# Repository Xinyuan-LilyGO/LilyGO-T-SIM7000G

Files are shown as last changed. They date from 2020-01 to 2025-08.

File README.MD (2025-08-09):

<h1 align = "center">LilyGo SIM7000G</h1>

## **This repository has been moved to [LilyGo-Modem-Series](https://github.com/Xinyuan-LilyGO/LilyGo-Modem-Series/) Please visit the latest repository to see how to get started**
<!-- 

# News

* **For more complete and rich examples, please visit the new repository [LilyGO-T-A76XX](https://github.com/Xinyuan-LilyGO/LilyGO-T-A76XX)**
* It is known that the firmware version 1529B08SIM7000G V01 has problems connecting to the MQTTS 8883 port. Please update the firmware version 1529B10SIM7000G
* Please see the [upgrade guide](./docs/How%20to%20update%20firmware.md)

```bash
-> AT+SIMCOMATI
<-  Revision:1529B08SIM7000G
    CSUB:V01
    APRev:1529B08SIM7000,V01
    QCN:MDM9206_TX3.0.SIM7000G_P1.03_20220415
    IMEI:xxxxxxxxxxxxx
```

### Version 20200415

   This board is an improvement of the original with fixes added that where recommended from feedback.
1. Added active GPS antenna power control, when the module GPIO4 is not turned on the antenna consumes only the static current of the LDO.
2. Replaced TP4056 with CN3065 for solar charge input management.
3. Added reverse battery protection
4. Added battery overcharge protection
5. Added battery over-discharge protection

 ### Version 20191227

   First board release,Sales have been stopped.

<h2 align = "left">Product 📷:</h2>

| Examples | Product  Link | Schematic | Status |
| :---: | :---: | :---: | :----: |
| [Version 20200415 (点击查看)](./Historical/SIM7000G_20200415/README.MD) | [Aliexpress](https://www.aliexpress.com/item/4000542688096.html)/[Amazon USA](https://www.amazon.com/dp/B099RQ7BSR?ref=myi_title_dp)/[FR](https://www.amazon.fr/dp/B099RQ7BSR?ref=myi_title_dp)/[DE](https://www.amazon.de/dp/B099RQ7BSR?ref=myi_title_dp) | [New Version](./schematic/SIM7000G_20200415.pdf) | ✅ |
| [Version 20191227 (点击查看)](./Historical/SIM7000G_20191227/README.MD) | Obsolete | [Old Version](./schematic/SIM7000G_20191227.pdf) | ❌ |

## Use reference

| Product | Youtube  link | explanation | Status | 
| :---: | :---: |:---:| :----: |
| T -SIM7000G | [Youtube link](https://www.youtube.com/watch?v=XlEUWIxdaNU) | How to test whether LILYGO T-SIM7000G can register with the network | ✅ |
| LilyGo device | [Youtube link](https://www.youtube.com/watch?v=f3BybP3L7ls) | How to enter boot mode to download the firmware | ✅ |

## Notes for new Users

0. SIM7000/SIM707G does not support 4G network. Please ensure that the USIM card you use supports 2G(GSM)/NB-IOT access,SIM7070 positioning and cellular cannot be used simultaneously. Please disconnect the network when positioning, and turn off GPS when connecting to the network

1. pin VIN is a USB input, if a battery is being used to power the device there will be no voltage output from VIN meaning 3.3v is the only power output.

2. When using the built-in battery pack the on/off switch will function as normal, supplying/cutting off power to the board, However, if an external battery pack is used and attached to the VBAT pin the on/off switch will be bypassed meaning the only way to shut off will be to disconnect the batteries.

3. On/off switch is for battery use only, it will not function when plugged into USB.

4. Battery voltage can not be read when plugged into USB using the onboard BAT ADC(35)

5. Recommended solar panels are 4.4v to 6v **DO NOT EXCEED OR BOARD MAY BE DAMAGED**

6. When an SD card in you can not upload software in Arduino IDE since the SD card uses IO2 as CS, the SD card must be removed when uploading a new sketch.

7. On Version 20200415, When using GPS the SIM7000G(GPIO4)/SIM7070G(GPIO5)(Physical pin number 48) needs to be set to HIGH to enable the antenna `modem.sendAT("+CGPIO=0,48,1,1");` once finished the pin can be set LOW `modem.sendAT("+CGPIO=0,48,1,0");` to prevent power leaking to the GPS antenna, This will make help battery life. If using USB or battery life is not a concern, it can be left HIGH.

8. If you are unable to access the network, please try <examples/Arduino_NetworkTest>, which will test the network connection. There are also binary files in the firmware directory, you can use the [Flash Download Tools](https://www.espressif.com/sites/default/files/tools/flash_download_tool_v3.8.5.zip) to download.

9.  How to change the connection method?
   - For example, the `Arduino_TinyGSM/AllFunctions.ino`  , you only need to change `modem.setNetworkMode(38);` to the corresponding number, and your network access speed depends on the carrier of the SIM card you use. Before using it, you can communicate with the operator of your SIM card.
   - The effect is as follows:
   ![](image/LTE.png)

10. The initial network registration may be slow. Please be patient. You can configure the locked band as shown in the following figure.
   ![CBANDCFG](image/CBANDCFG.png)

11. How to update firmware?
   - [Upgrade guidelines ](docs/How%20to%20update%20firmware.md)

12. When the onboard USB bridge cannot be downloaded, you can use the external USB bridge to upload the sketch
   ![](./Historical/Image/externalDownloader.jpg)

13. Voltage range

| Battery Voltage requirements | Minimum | Maximum | Charging Current |
| --- | --- | --- | --- |
| SIM7000G | 3.5V | 4.2V | 500mA |
| SIM7070G | 3.5V | 4.2V | 500mA |

* It is recommended to use 18650 batteries with a capacity of more than 2500mA

| Solar Voltage requirements | Minimum | Maximum | Charging Current |
| --- | --- | --- | --- |
| SIM7000G | 4.4V | 6V | 500mA |
| SIM7070G | 4.4V | 6V | 500mA |

> \[!TIP]
>
> It is recommended to use a solar panel with an output voltage of 6V or 5V and a power of about 5-10W. Solar energy can only charge the battery. Without the battery, the panel cannot supply power.
> Please note that this is only a suggestion. It is not necessary to use a 5-10W solar panel. 1W is also acceptable.
> The size of the solar panel determines the current and speed of solar charging. Please note that depending on the environment,
> the sunshine time may not exceed one hour per day. At this time, if the solar panel is too small and the light is not sufficient, it cannot be charged.

## GPIO MAP

| FUNCTION | GPIO NUM |
| --- | --- |
| RX | 26 |
| TX | 27 |
| PWR | 4 |
| DTR | 25 |
| RING | NC |
| RESET | NC |
| ON BOARD LED(BLUE)  | 12 |
| SD SOCKET MISO | 2 |
| SD SOCKET MOSI | 15 |
| SD SOCKET SCK | 14 |
| SD SOCKET CS | 13 |
| BATTERY ADC CONNECT | 35 |
| SOLAR ADC CONNECT | 36 |

## ON-BOARD LED

| FUNCTION | COLOR |
| --- | --- |
| MODEM STATUS | RED (Near the modem) |
| MODEM NETWORK STATE | RED (Near the modem) |
| CHARGE FULL | GREEN (Near the USB port) |
| CHARGING | RED (Near the USB port) |
| GPIO CONTROL | BLUE |

### **MODEM STATUS**

- As long as the modem is turned on, the STATUS light will remain on and will go out when it is turned off.

### **MODEM NETWORK STATE**

| Network light status | Module working status |
| --- | --- |
| 64ms on/ 800ms off | When not registered on the network |
| 64ms on/ 3000ms off  | Already registered on the network (PS domain registration successful) |
| 64ms on/ 300ms off | During data transmission (PPP dial-up state and when using internal TCP/FTP/HTTP and other data services) |
| Off | Power off or PSM sleep mode | -->

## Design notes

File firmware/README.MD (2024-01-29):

# Write to new users

- This page provides a quick diagnosis of whether the hardware is normal. The firmware in the example table below can provide a quick test of the hardware. Follow the writing method below.
- When using GPS positioning test, please do it outdoors or by extending the active GPS antenna. The geographical location cannot be obtained indoors.
- For network testing, please connect the LTE antenna to the board's silk screen MAIN or SIM IPEX antenna base.
- Please do not use a SIM card with a locked PIN code. Please delete the PIN code before use.

# 1️⃣ Quickly diagnose hardware

| GPS Test describe | GPS Test Firmware | Network Test Firmware |
| --- | --- | --- |
| Firmware decoded NMEA data | [GPS_Decoder.bin](./GPS_Decoder.bin) | [firmware](./Arduino_NetworkTest_Frimware.bin) |
| Firmware for raw NMEA data | [GPS_RAW_DATA.bin](./GPS_RAW_DATA.bin) | [firmware](./Arduino_NetworkTest_Frimware.bin) |

* [Firmware for raw NMEA data video](https://youtu.be/eVJ8NNOeWnY)

| Network Test describe | Network Test Firmware |
| --- | --- |
| Firmware automatically searches for networks | [firmware](./Arduino_NetworkTest_Frimware.bin) |

[1]: https://www.lilygo.cc/products/t-sim7000g

## Use ESP Download Tool

| Steps  | [T-SIM70XX][1] |
| --- | --- |
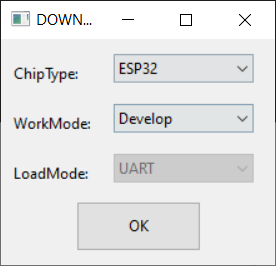
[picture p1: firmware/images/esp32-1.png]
| Step 1 |  |
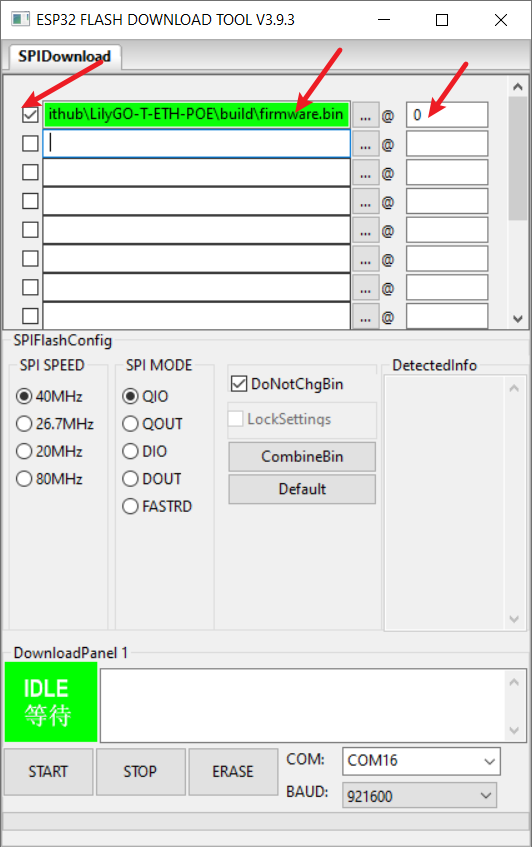
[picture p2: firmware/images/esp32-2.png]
| Step 2 |  |

## Use Web Flasher

[esp.huhn.me](https://esp.huhn.me/)

web_flasher

# 2️⃣FAQ

- Can't upload any sketch，Please enter the upload mode manually.
   1. Connect the board via the USB cable
   2. Press and hold the BOOT button , While still pressing the BOOT button (If there is no BOOT button, you need to use wires to connect GND and IO0 together.)
   3. Press RST button
   4. Release the RST button
   5. Release the BOOT button (If there is no BOOT button, disconnect IO0 from GND.)
   6. Upload sketch

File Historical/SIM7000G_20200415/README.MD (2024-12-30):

<h1 align = "center">LilyGO T-SIM7000G 20200415</h1>

### PinOut

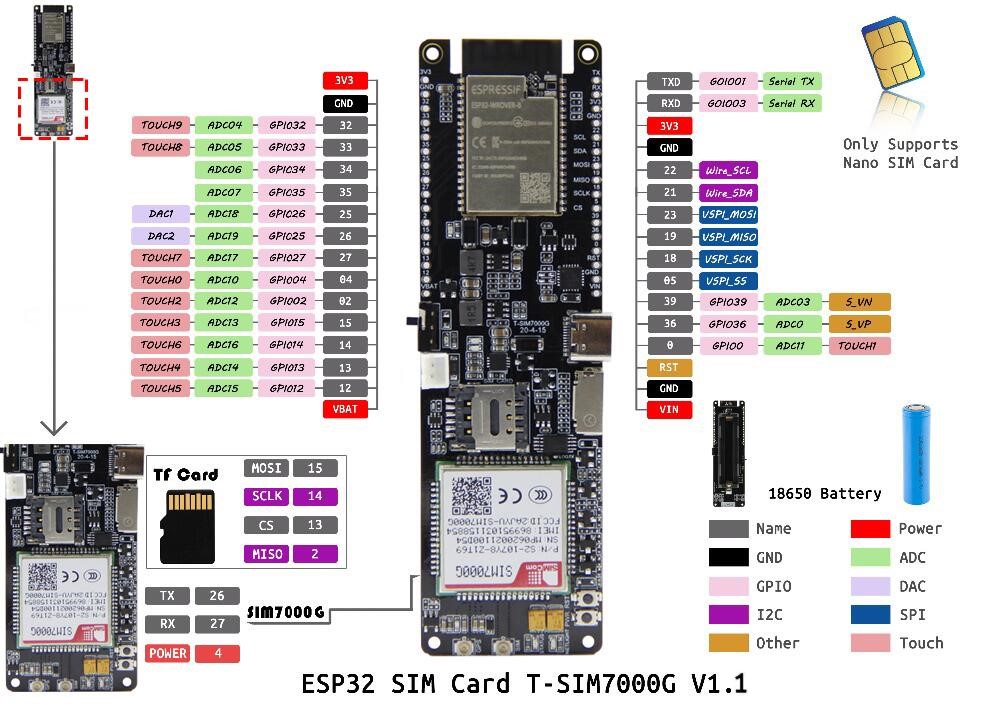
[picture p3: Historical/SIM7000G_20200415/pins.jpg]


### Dimensions
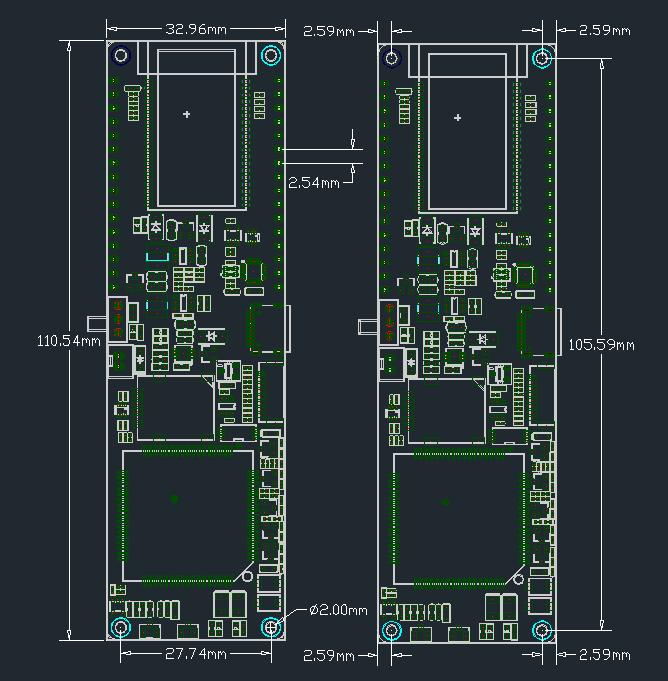
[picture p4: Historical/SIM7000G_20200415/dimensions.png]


## Examples
- Arduino + TinyGSM library: [examples/Arduino_TinyGSM](../../examples/Arduino_TinyGSM/)
- Platformio_Arduino_Thingsboard :[/exaples/Platformio_Arduino_Thingsboard](../../examples/Platformio_Arduino_Thingsboard)
- Loboris Micropython: [/examples/MicroPython_LoBo](../../examples/MicroPython_LoBo)
- Arduino Cayenne: [/examples/Arduino_Cayenne](../../examples/Arduino_Cayenne)

## SIM7000G connection
| Name | Pins |
| --- | --- |
| Modem DTR | 25 |
| Modem Rx | 26 |
| Modem Tx | 27 |
| Modem PowerKey | 4 |
| Modem Reset | 5 |
| Modem GPS | SIM7000G(GPIO4)/SIM7070G(GPIO5)(Physical pin number 48) |
| BAT ADC | 35 |
| SOLAR ADC | 36 |
| SD MISO | 2 |
| SD MOSI | 15 |
| SD CLK | 14 |
| SD CS | 13 |
| LED | 12 |

**Modem GPS** is the internal GPIO of the SIM7000G module. When using GPS, GPIO4 needs to be set to high level, as shown below:

```
// Set SIM7000G(GPIO4)/SIM7070G(GPIO5) to HIGH ,Open GPS power
modem.sendAT("+CGPIO=0,48,1,1");

// Set SIM7000G(GPIO4)/SIM7070G(GPIO5) to LOW ,Close GPS power
modem.sendAT("+CGPIO=0,48,1,0");
```

- About the onboard indicator light description:
1. In the pin diagram, the red indicator light near the upper right of the switch is only on when the battery is connected, and it is always on when the USB is connected. It indicates that the battery is charging. If the battery is not connected, it may be Flashing
2. Below the red light is the green indicator light, which lights up only when the battery is fully charged, and it is always on when the battery is connected

3. Close to the side of the SIM7000G antenna is the status indicator. If the SIM7000G starts normally, it will always be on. If it does not start normally, it will not be on. It cannot be turned off by software.
4. Close to the status indicator is the network indicator, it indicates the network status, it can be closed by software

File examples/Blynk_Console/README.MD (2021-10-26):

<h1 align = "center">T-PCIE-SIM7000 Blynk_Console</h1>

## **[English](./README.MD) | [中文](./README_CN.MD)**

# Steps:
1. Need to install the following dependencies
     - [Adafruit BMP085 Library](https://github.com/adafruit/Adafruit-BMP085-Library)
     - [blynk-library](https://github.com/blynkkk/blynk-library)
     - [TinyGSM](https://github.com/vshymanskyy/TinyGSM)

2. Register and login[blynk.cloud](https://blynk.cloud/dashboard/login) 

3. Create a new template or use an existing template (The name can be customized)

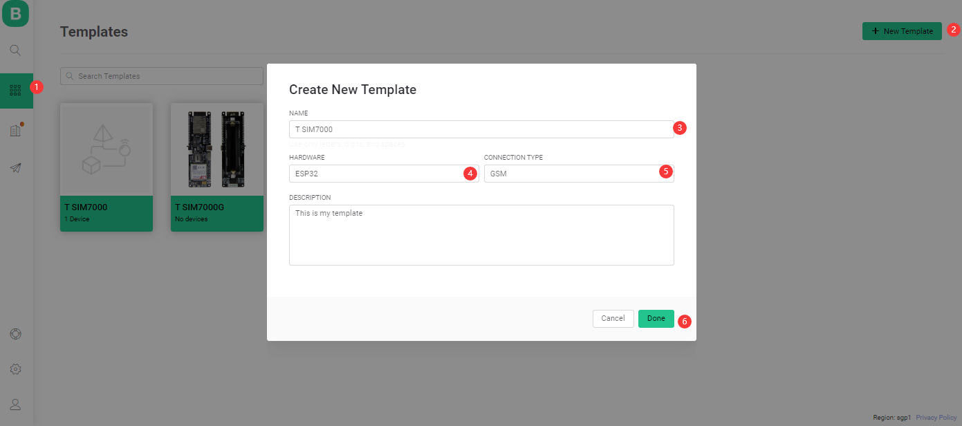
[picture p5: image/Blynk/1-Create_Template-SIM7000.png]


4.   When the Template is ready, go to Search -> Devices - Create New Device

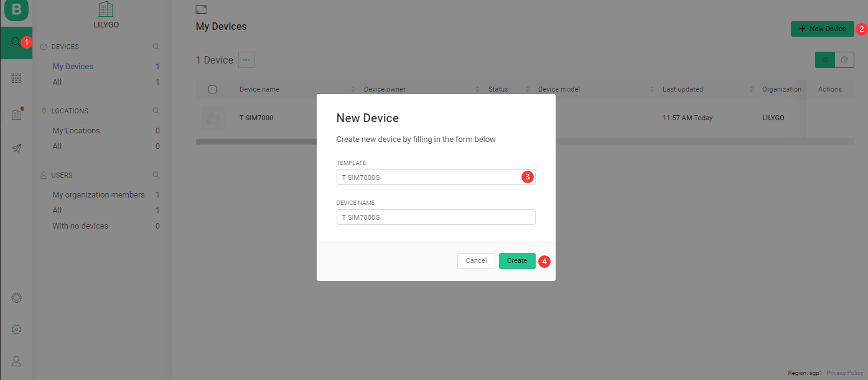
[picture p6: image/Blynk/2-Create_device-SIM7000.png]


5. Configuration module

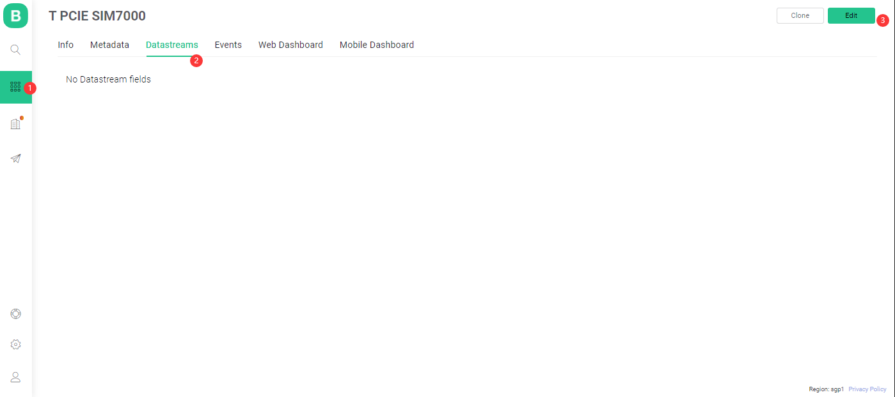
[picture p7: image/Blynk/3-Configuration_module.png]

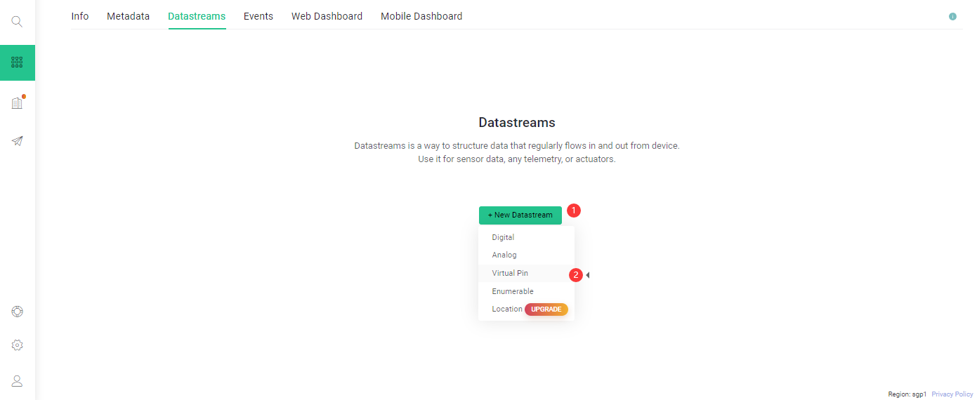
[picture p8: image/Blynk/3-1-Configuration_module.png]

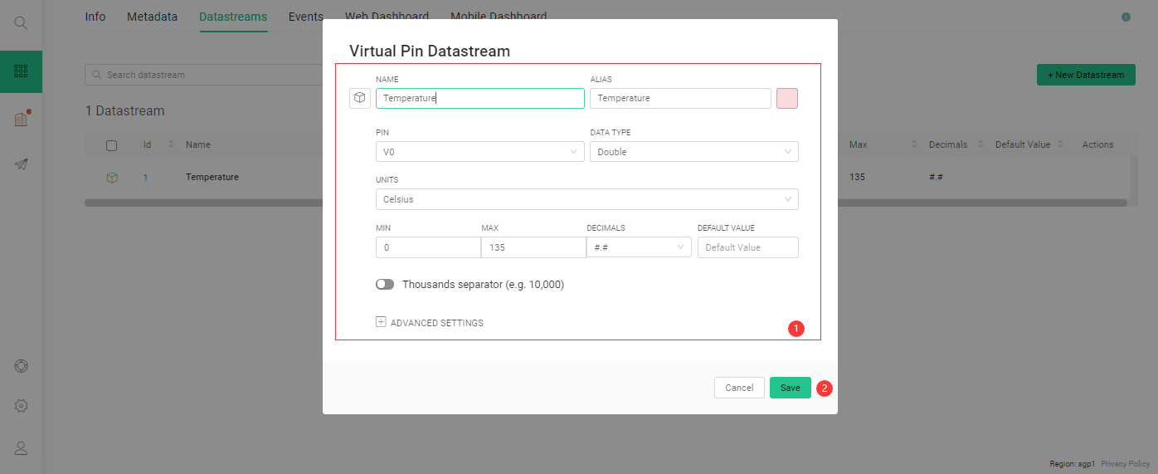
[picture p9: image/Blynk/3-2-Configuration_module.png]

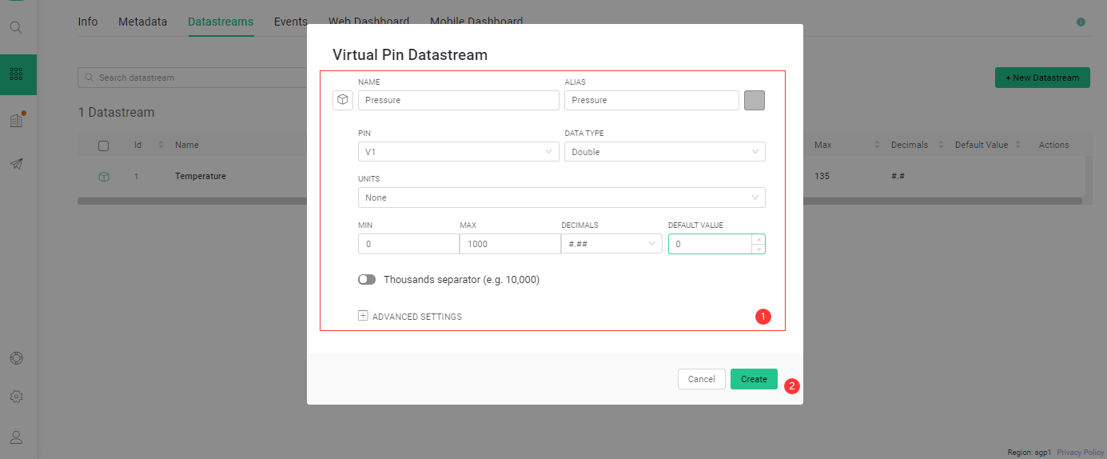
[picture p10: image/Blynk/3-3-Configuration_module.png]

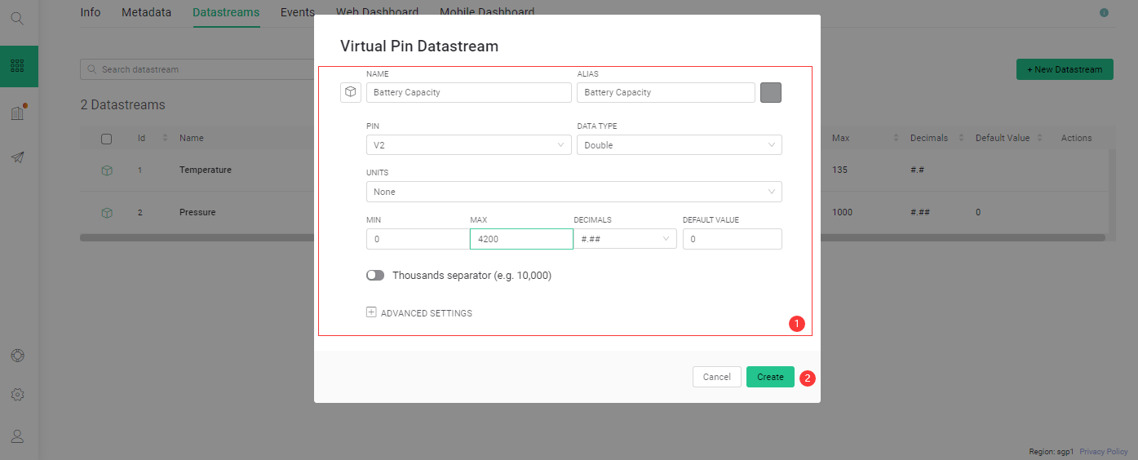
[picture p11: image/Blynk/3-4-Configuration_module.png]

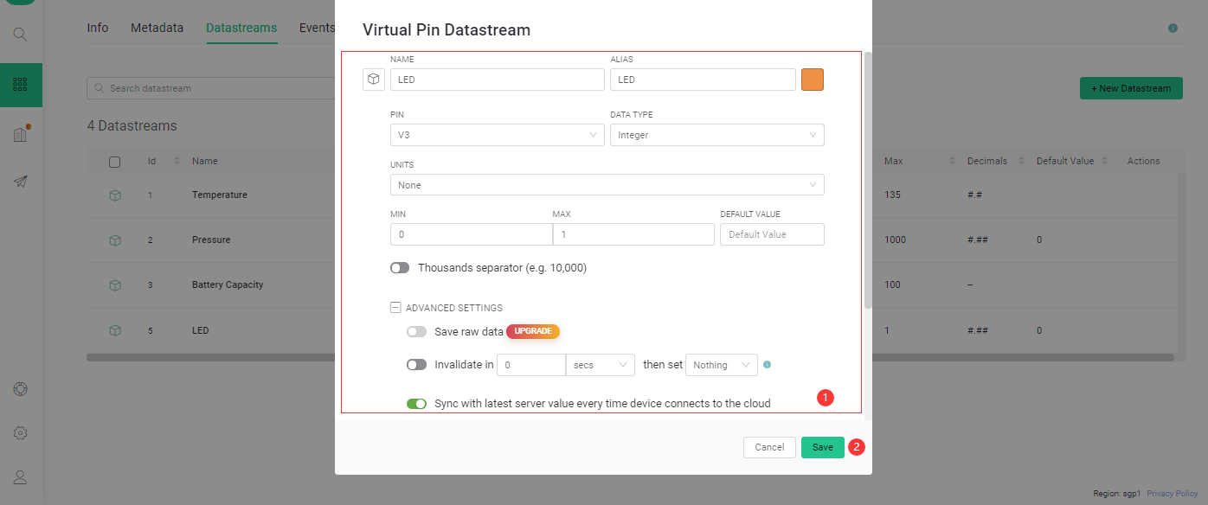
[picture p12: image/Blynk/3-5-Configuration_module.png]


6. Set up the Web dashboard

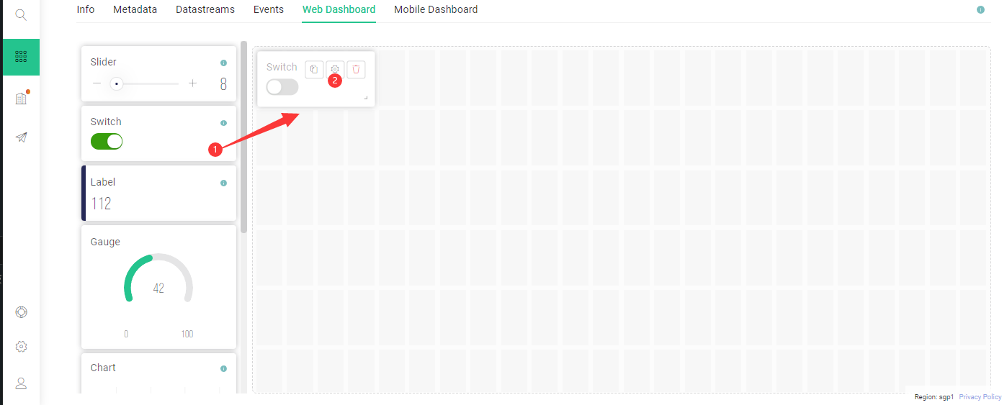
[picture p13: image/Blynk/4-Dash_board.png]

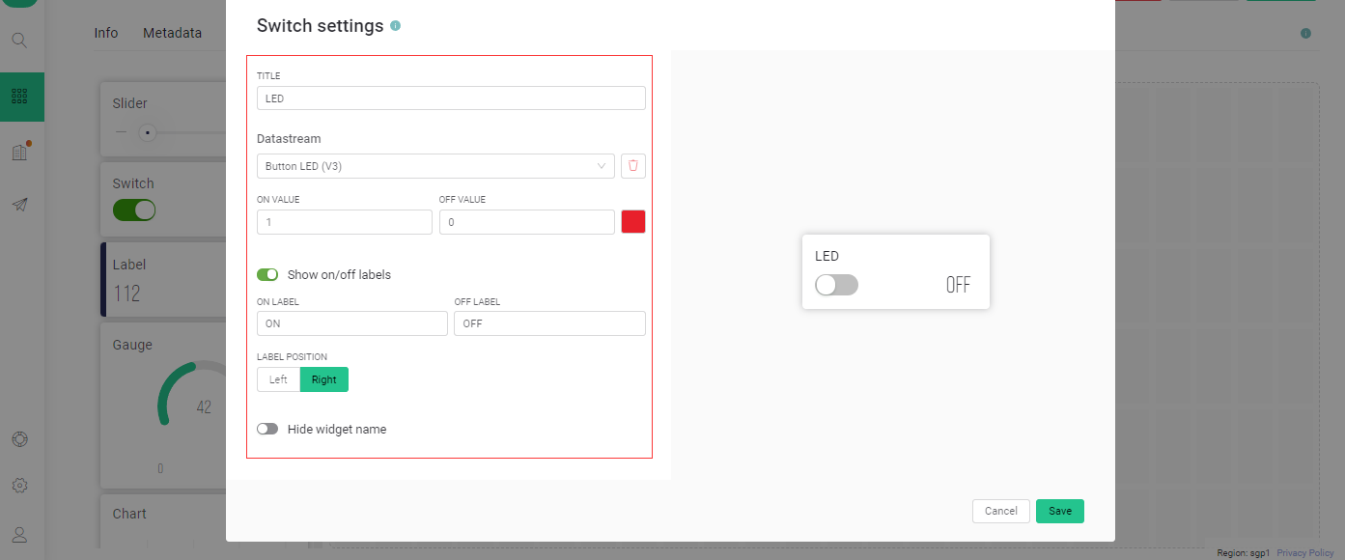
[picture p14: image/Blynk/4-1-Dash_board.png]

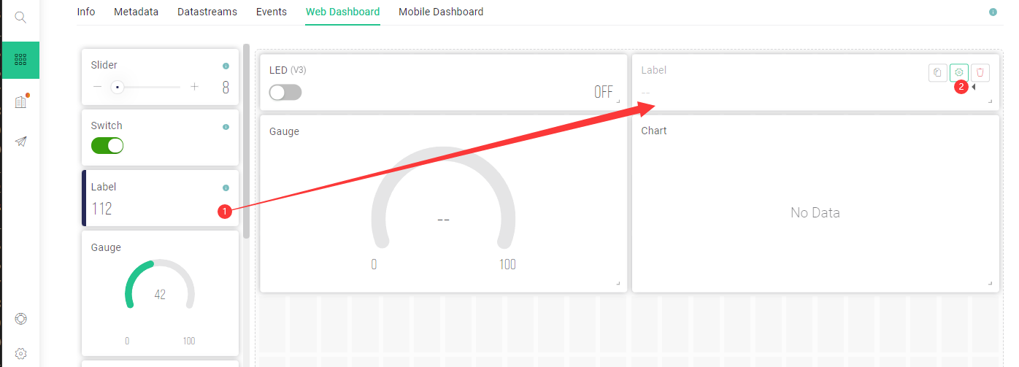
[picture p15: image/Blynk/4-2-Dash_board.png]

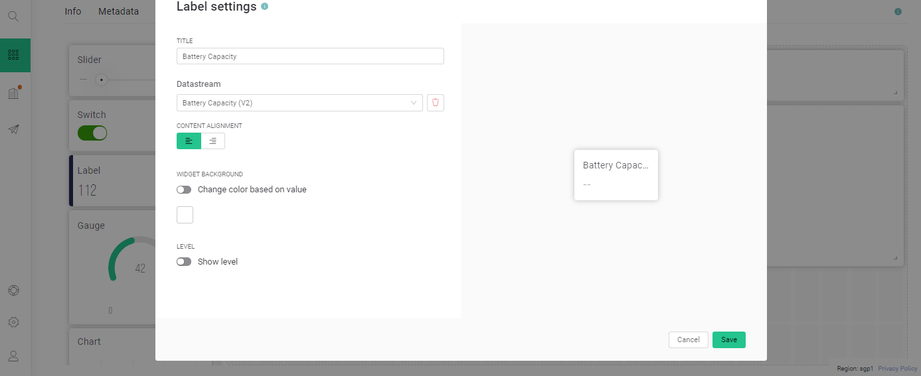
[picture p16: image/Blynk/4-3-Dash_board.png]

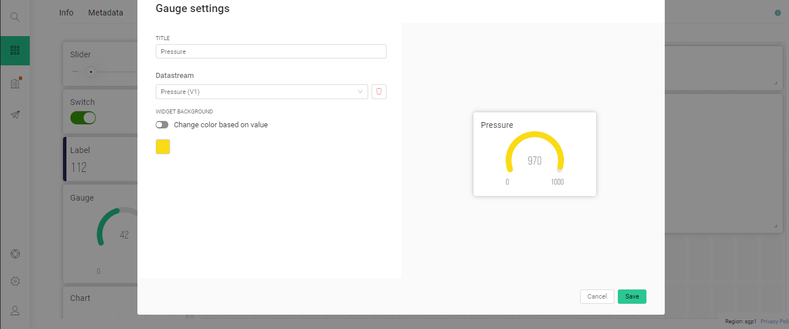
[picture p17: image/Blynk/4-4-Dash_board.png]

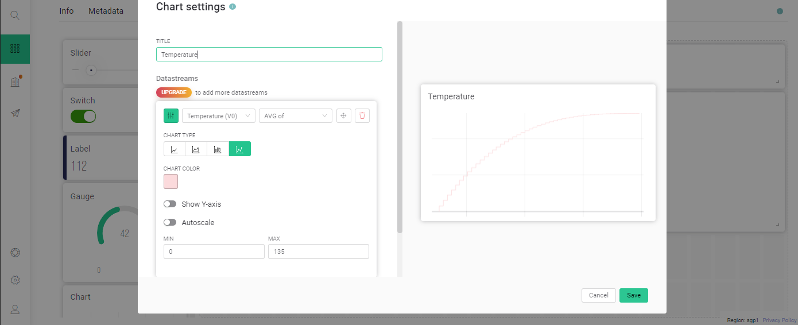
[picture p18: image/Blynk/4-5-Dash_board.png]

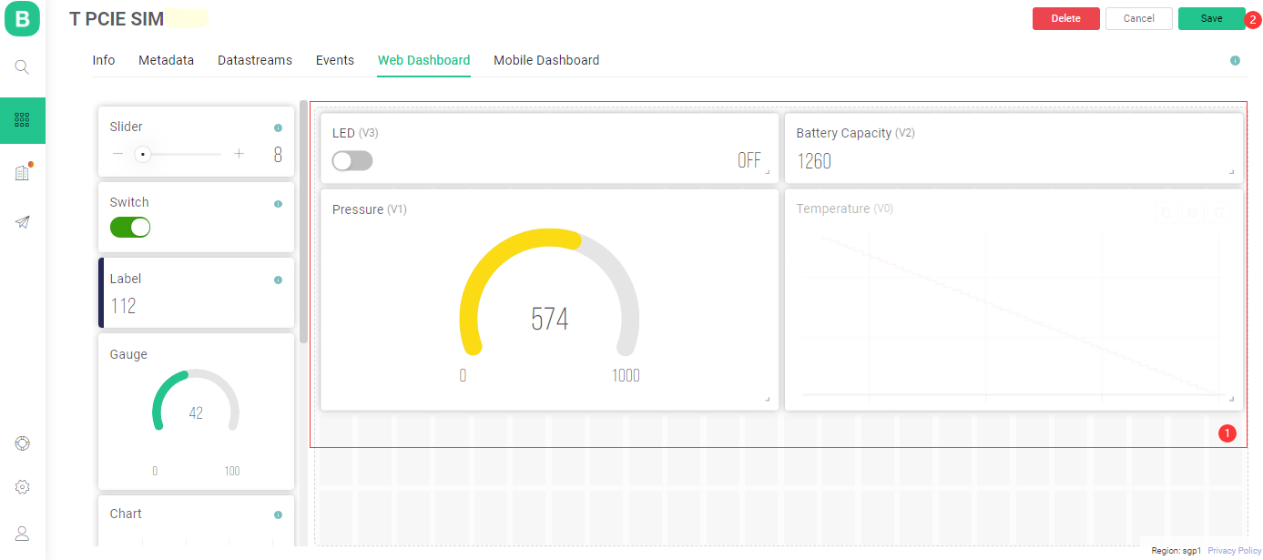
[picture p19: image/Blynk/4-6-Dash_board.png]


7. Replace the macro definition in the code

    #define BLYNK_TEMPLATE_ID ""
    #define BLYNK_DEVICE_NAME ""
    #define BLYNK_AUTH_TOKEN "";

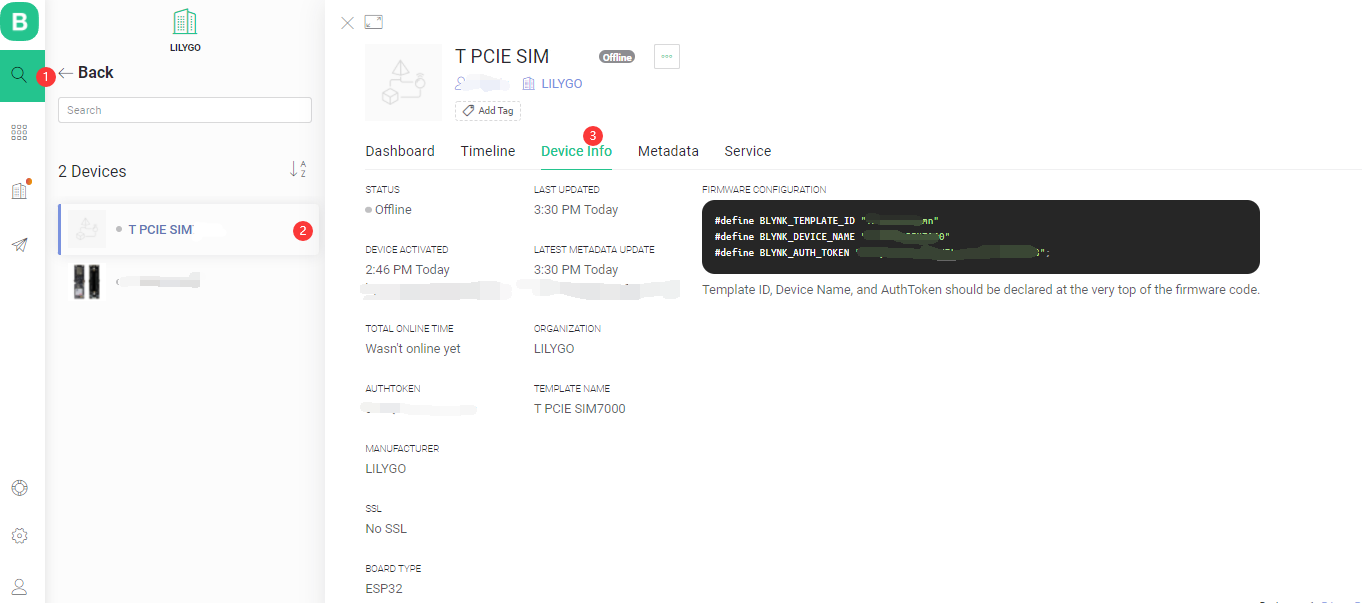
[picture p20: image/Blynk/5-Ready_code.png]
 

8. Upload the code and now you control the LDE and get the data in the cloud
   
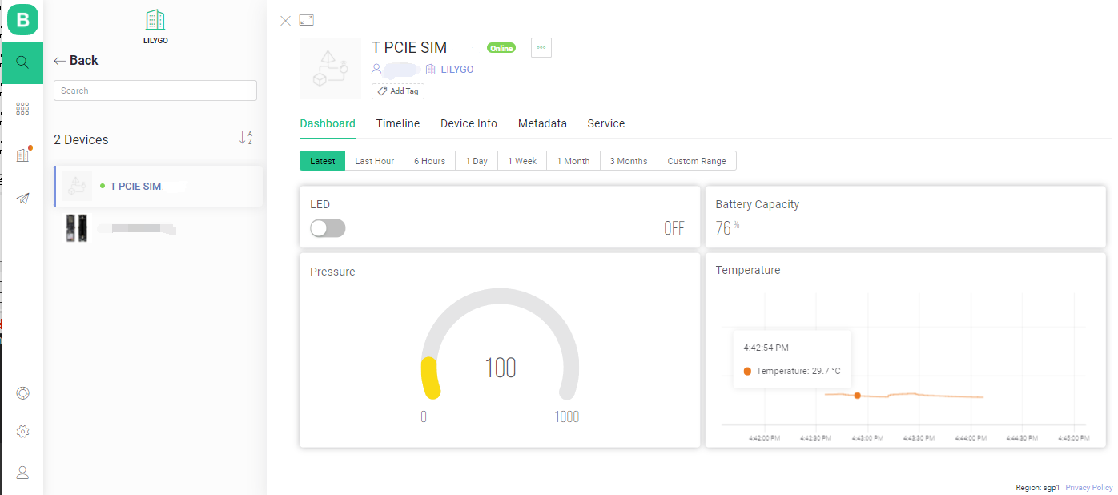
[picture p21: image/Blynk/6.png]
   

9. Reference[Documentation](https://docs.blynk.io/en/)

# Hardware
Connections for T-SIM7000 and BMP180
| T-PCIE pin  | BMP180 pin |
| --- | --- |
| 3.3 | VIN |
| GND | GND |
| GPIO21(SDA) | SDA |
| GPIO22(SCL) | SCL |

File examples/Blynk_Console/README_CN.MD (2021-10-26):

<h1 align = "center">T-PCIE-SIM7000 Blynk_Console</h1>

## **[English](./README.MD) | [中文](./README_CN.MD)**

# 步骤:

1. 需要安装下面的库
     - [Adafruit BMP085 Library](https://github.com/adafruit/Adafruit-BMP085-Library)
     - [blynk-library](https://github.com/blynkkk/blynk-library)
     - [TinyGSM](https://github.com/vshymanskyy/TinyGSM)

2. 注册登录[blynk.cloud](https://blynk.cloud/dashboard/login) 

3. 创建新模板或使用已有模板



4. 当模板准备好，进入搜索->设备-创建新设备  



5. 配置模块








6. 设置 Web 仪表板 









7. 替换代码中的宏

#define BLYNK_TEMPLATE_ID ""
#define BLYNK_DEVICE_NAME ""
#define BLYNK_AUTH_TOKEN "";



8. 上传代码，可以控制LDE和获取数据

 

10. 参考[文档](https://docs.blynk.io/en/)

# 硬件接线
| T-PCIE pin  | BMP180 pin |
| --- | --- |
| 3.3 | VIN |
| GND | GND |
| GPIO21(SDA) | SDA |
| GPIO22(SCL) | SCL |

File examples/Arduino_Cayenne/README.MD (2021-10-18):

<h1 align = "center">LilyGO T-SIM7000 Cayenne</h1>

💦 ☀💨🌹 The sample code is based on the **[LilyGO T-SIM7000](https://www.aliexpress.com/item/4000542688096.html)** board, which takes the data of the external BMP180 sensor and uploads it to **[Cayenne](https://cayenne.mydevices.com/)**.

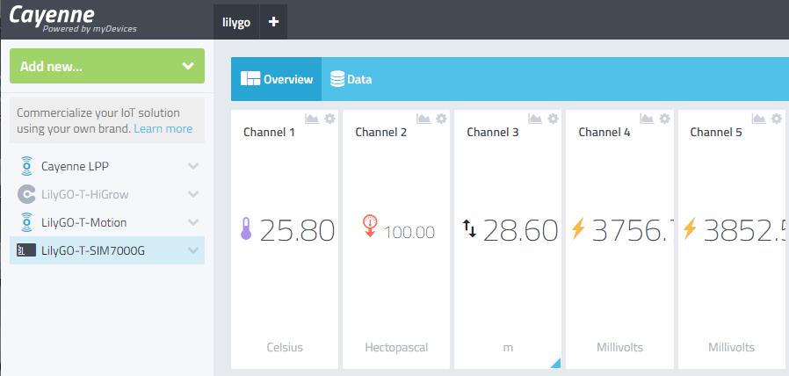
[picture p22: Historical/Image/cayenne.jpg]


# Steps:
1. Need to install the following dependencies
     - [Adafruit BMP085 Library](https://github.com/adafruit/Adafruit-BMP085-Library)
     - [CayenneMQTT](https://github.com/myDevicesIoT/Cayenne-MQTT-Arduino)
     - [ArduinoJson](https://github.com/bblanchon/ArduinoJson) Use version 6.13.0
     - [TinyGSM](https://github.com/vshymanskyy/TinyGSM)
2. Set the Cayenne authentication info to match the authentication info from the Dashboard.If you don't have an account, then [create an account](https://accounts.mydevices.com/auth/realms/cayenne/login-actions/registration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)
3. After logging in, you will see the dashboard, click **Add new** in the upper left,Choose **Generic ESP8266**,Then you can see the MQTT username, password and ID you need to use,Replace it with the definition in `main.cpp`
4. Set the network name and password.
5. Compile and upload the sketch.
6. A temporary widget will be automatically generated in the Cayenne Dashboard. To make the widget permanent click the plus sign on the widget.
7. By default, GSM is used to upload sensor data. You can also change it to ESP32 to upload. You only need to host the **USE_GSM** macro in the sketch.

# Hardware
Connections for T-SIM7000 and BMP180
| T-SIM7000 pin | BMP180 pin |
| --- | --- |
| 3.3 | VIN |
| GND | GND |
| GPIO21(SDA) | SDA |
| GPIO22(SCL) | SCL |

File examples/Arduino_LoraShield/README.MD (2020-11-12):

## Install the following dependency library files:
[arduino-LoRa](https://github.com/sandeepmistry/arduino-LoRa)

- For more examples, please refer to arduino-LoRa/examples

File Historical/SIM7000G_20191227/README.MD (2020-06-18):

<h1 align = "center">LilyGO T-SIM7000G </h1>

### PinOut

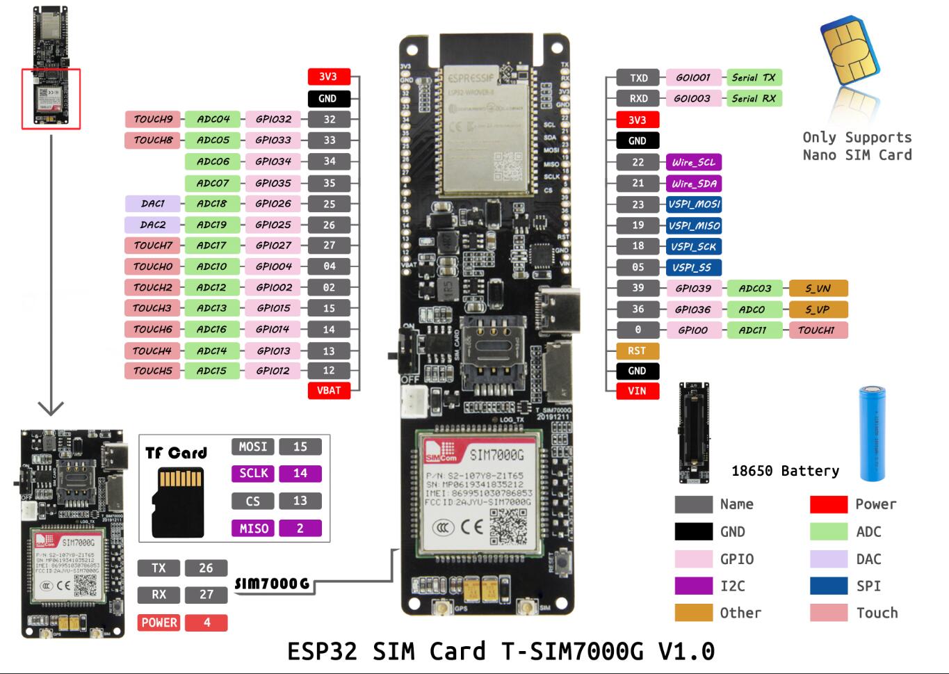
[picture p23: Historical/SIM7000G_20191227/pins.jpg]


### Dimensions
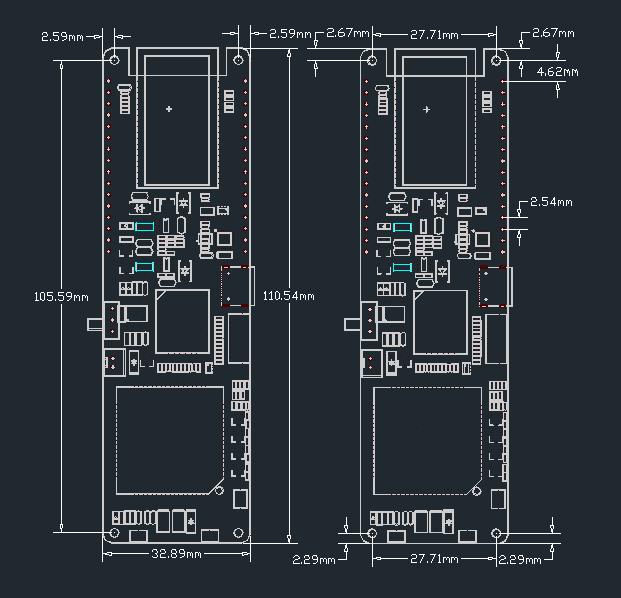
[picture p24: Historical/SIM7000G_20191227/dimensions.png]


## Examples
- Arduino + TinyGSM library: [examples/Arduino_TinyGSM](../../examples/Arduino_TinyGSM/)
- Platformio_Arduino_Thingsboard :[/exaples/Platformio_Arduino_Thingsboard](../../exaples/Platformio_Arduino_Thingsboard)
- Arduino Cayenne: [/examples/Arduino_Cayenne](../../examples/Arduino_Cayenne)

## SIM7000G connection
| Name | Pins |
| --- | ---- |
| PIN_RX | 26 |
| PIN_TX | 27 |
| PWR_PIN | 4 |
| BAT_ADC | 35 |
| SOLAR_ADC | 36 |
| SD MISO | 2 |
| SD MOSI | 15 |
| SD CLK | 14 |
| SD CS | 13 |

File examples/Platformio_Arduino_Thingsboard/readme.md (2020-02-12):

# Example project for Platformio

- T-SIM7000 NBIoT or GSM mode (modified TinyGSM lib)
- Connecting to Thingsboard and sending telemetry battery/rssi/bootcount via MQTT
- Sleeping ESP32 & SIM7000 (~1mA consumption)

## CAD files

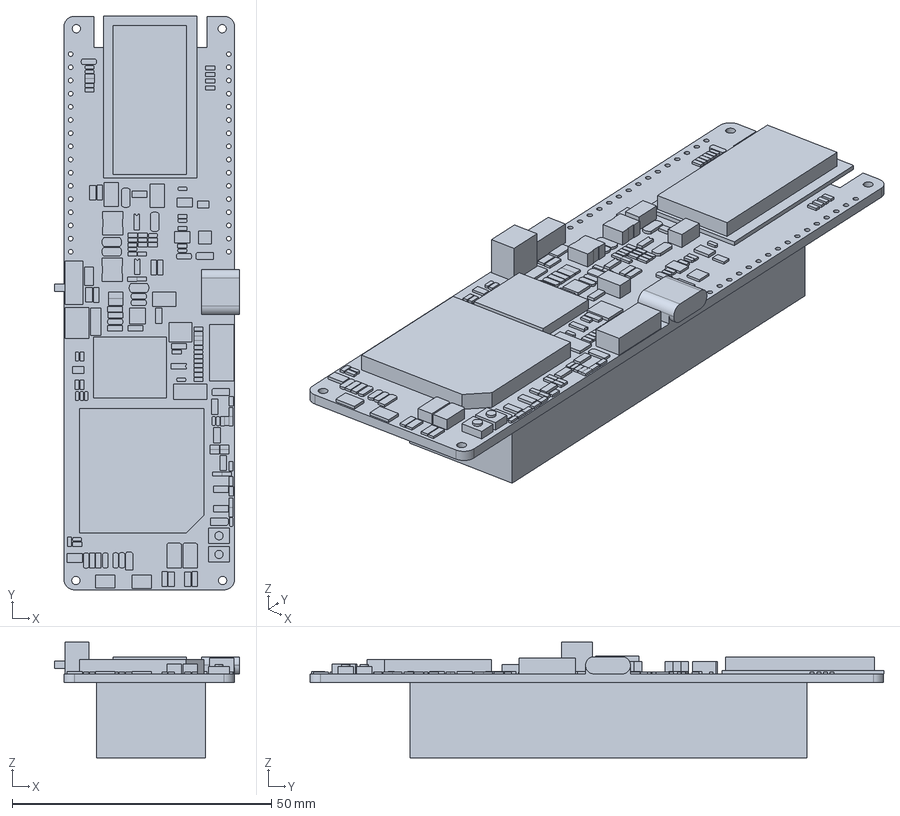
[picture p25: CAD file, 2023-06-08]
3D_file/T-SIM7000G(6.08).stp
35.7 x 110.6 x 22.4 mm

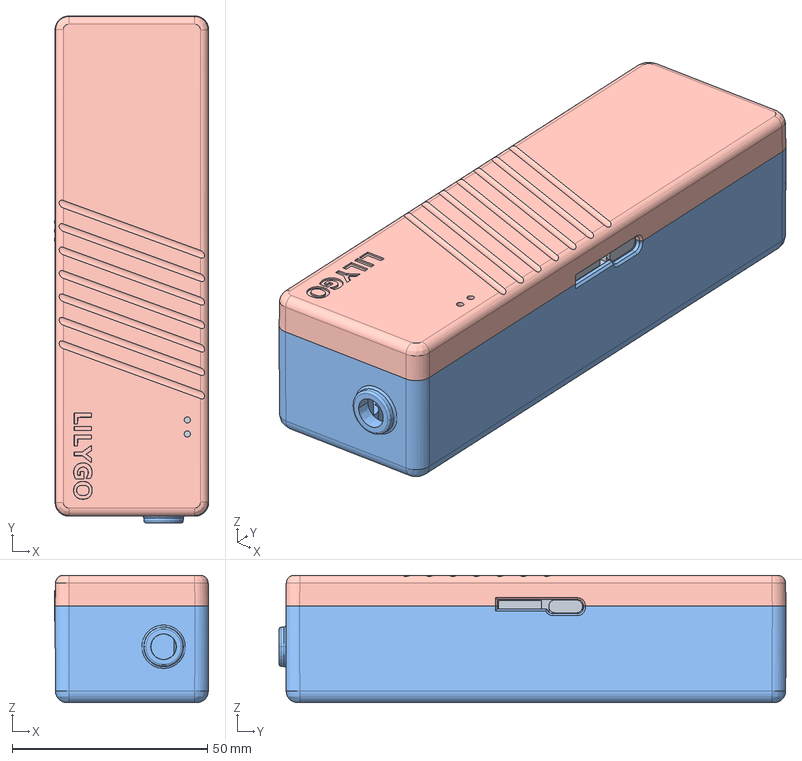
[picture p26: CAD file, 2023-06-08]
3D_file/t-sim7000g-shell.stp
39.5 x 129.8 x 32.6 mm
007_02_T-SIM7000G-B-COVER
006_02_T-SIM7000G-A-COVER
003_01_A7672-C-COVER
T-SIM7000G_6_08_

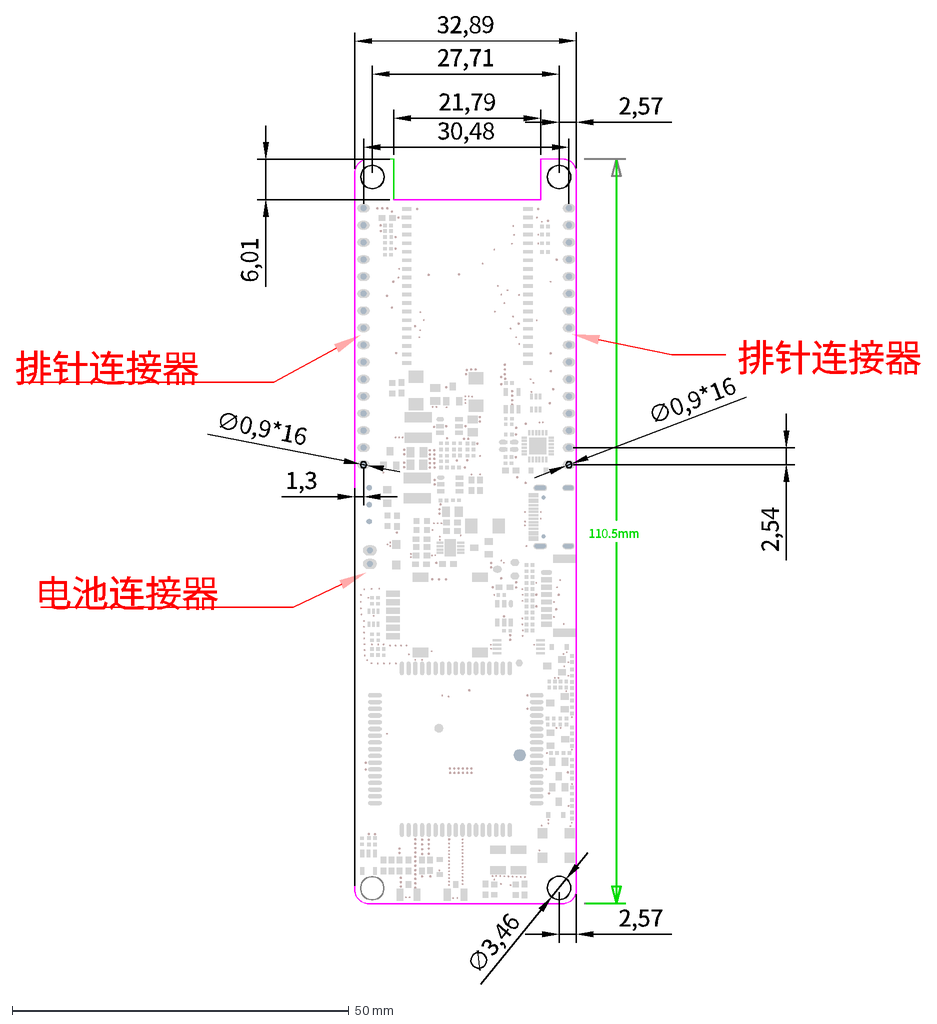
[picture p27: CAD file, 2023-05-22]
3D_file/T-SIM7000G..dxf
110.5mm
32,89
27,71
2,57
∅3,46
21,79
6,01
电池连接器
排针连接器
∅0,9*16
2,54
30,48
1,3

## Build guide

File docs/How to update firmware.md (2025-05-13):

## Quick Step

1. To solder the USB to the upgrade solder joint, you can choose a flying lead or directly solder the USB to the contact.
2. Power on the SIM7000G board, and at the same time connect the USB interface to the computer port (please note that you need to insert the SIM card during the upgrade process)
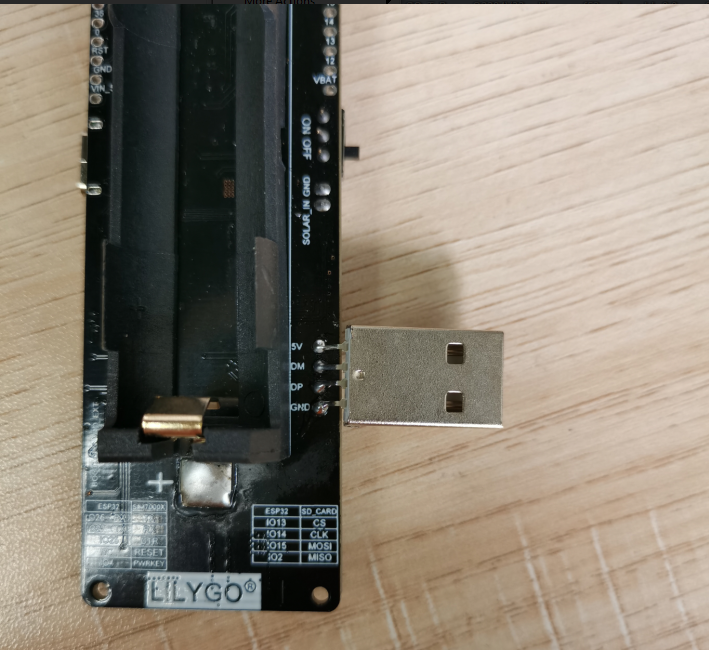
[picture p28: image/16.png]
    
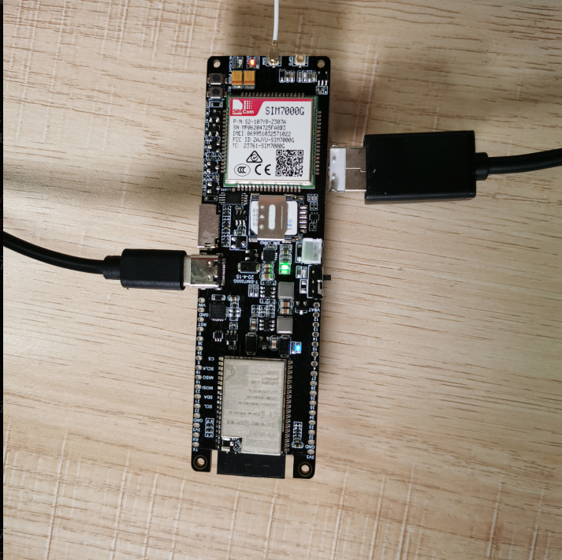
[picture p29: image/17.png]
    
3. Download [SIM7000X Driver](https://1drv.ms/u/s!AmbpOqVezk5drS-ateuVXXDK1ulv?e=yc0kXz), and decompress the corresponding compressed package according to the system you are using.
4. Open the computer device manager and follow the steps below to add the driver.
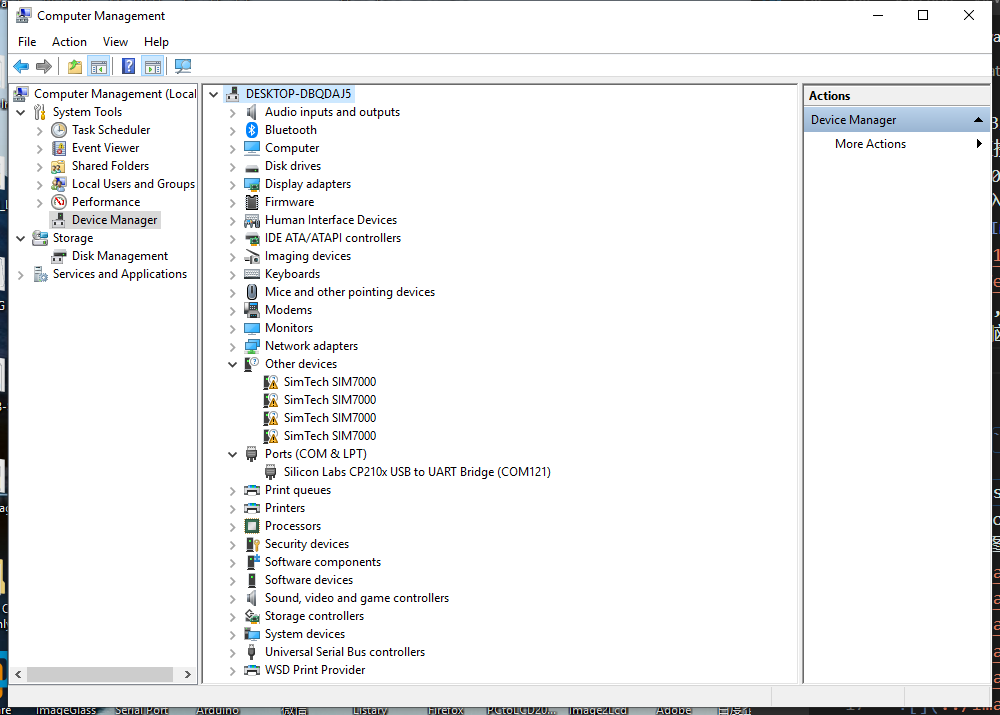
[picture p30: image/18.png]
    
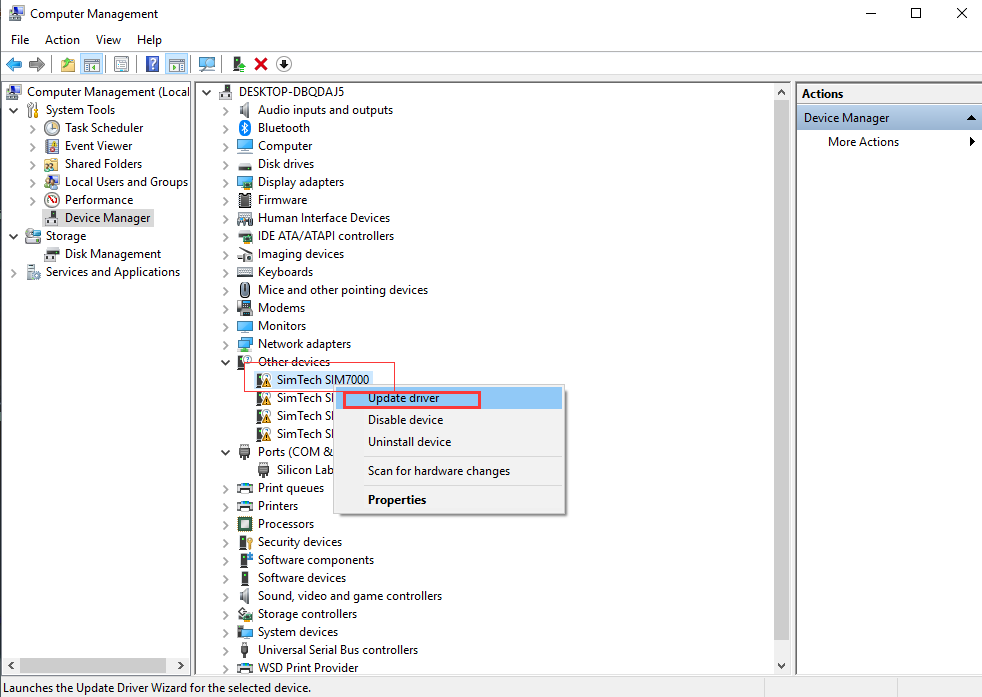
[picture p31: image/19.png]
    
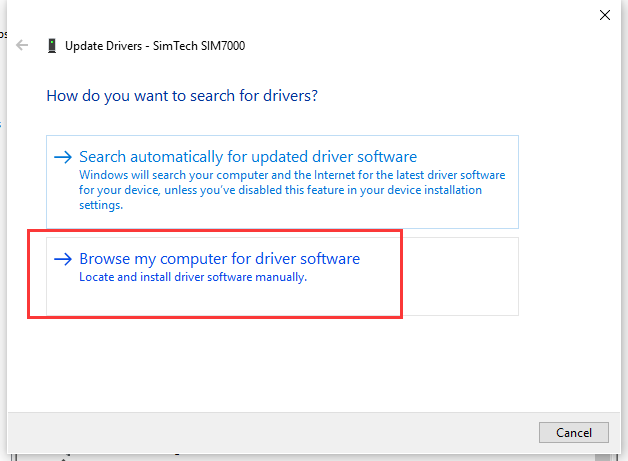
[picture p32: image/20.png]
    
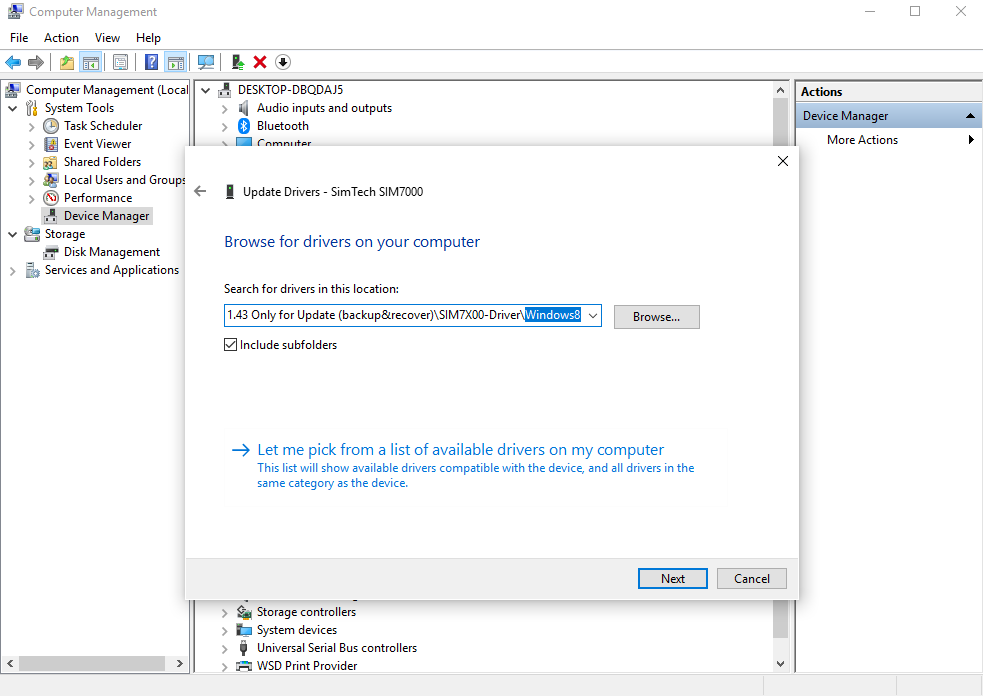
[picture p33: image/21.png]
    
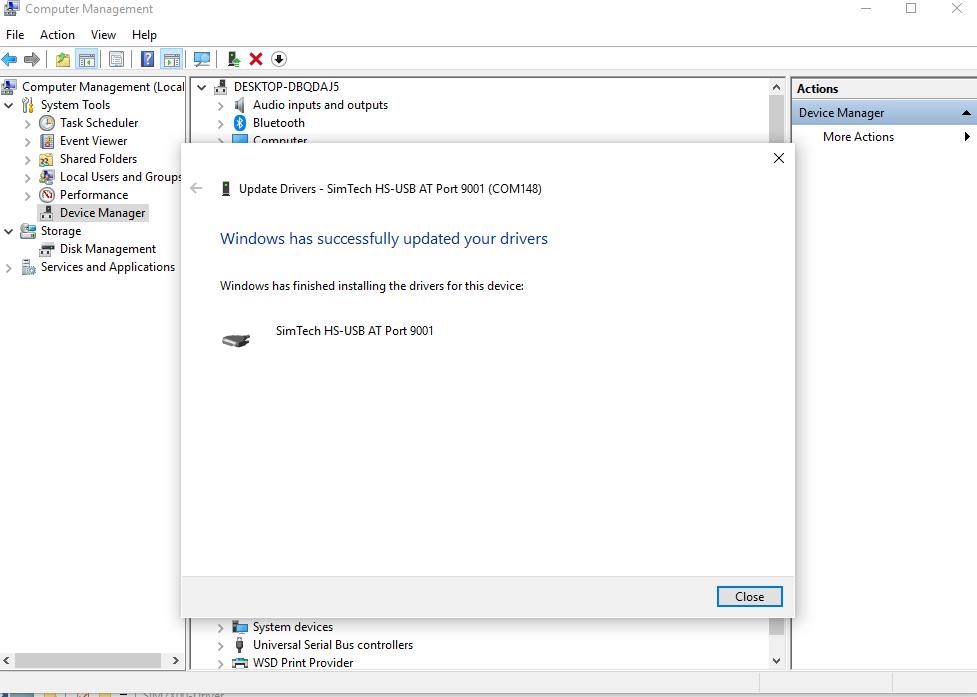
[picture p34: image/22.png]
    
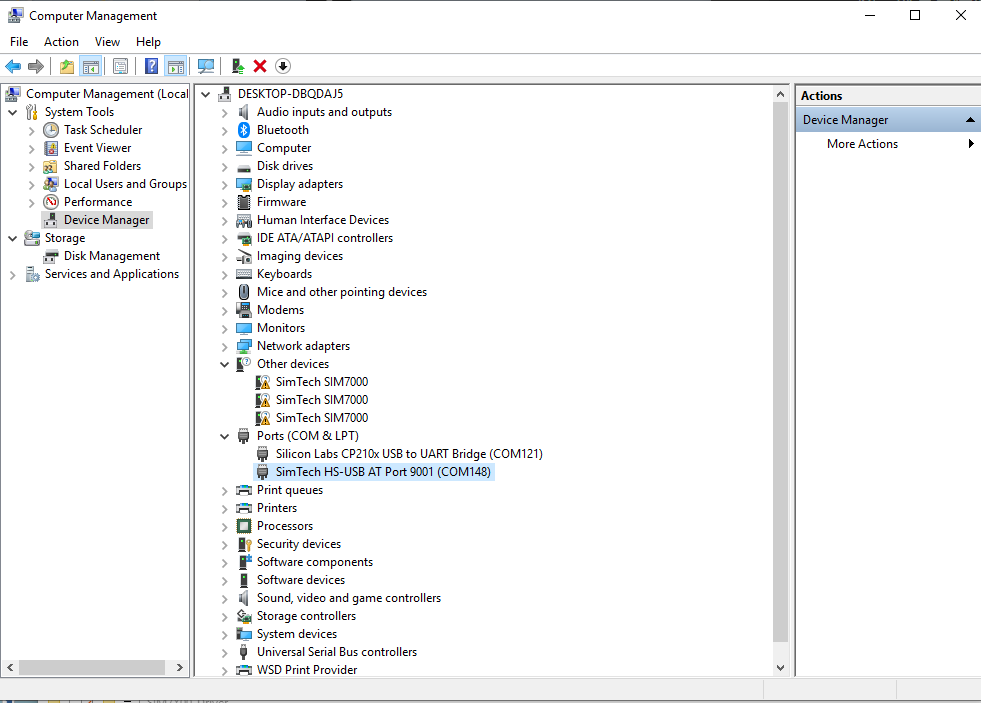
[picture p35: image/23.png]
    
    Follow the above steps to install the driver for the remaining ports that are not installed.
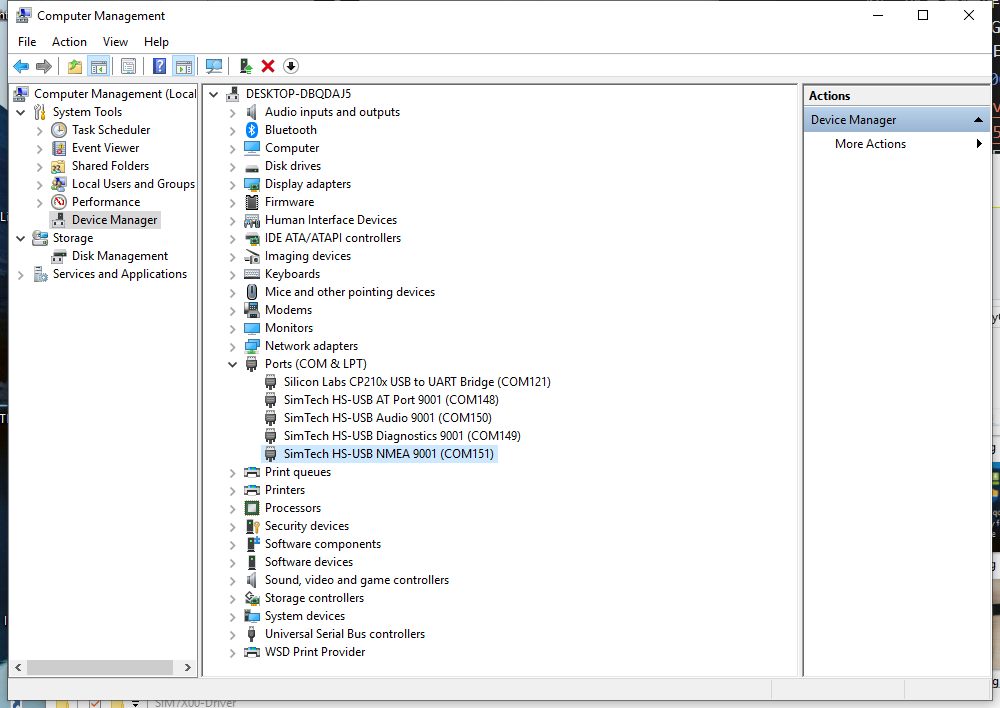
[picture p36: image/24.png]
    

5. Unzip `SIM7000-Update-tools.7z`
6. Open `setup.exe` , install update tools
7. Follow the steps below to install
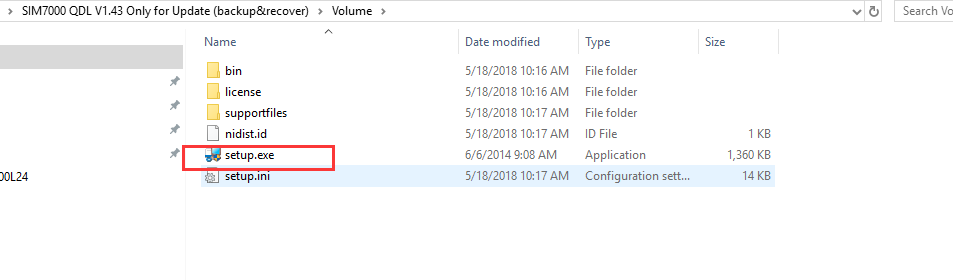
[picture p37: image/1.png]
    
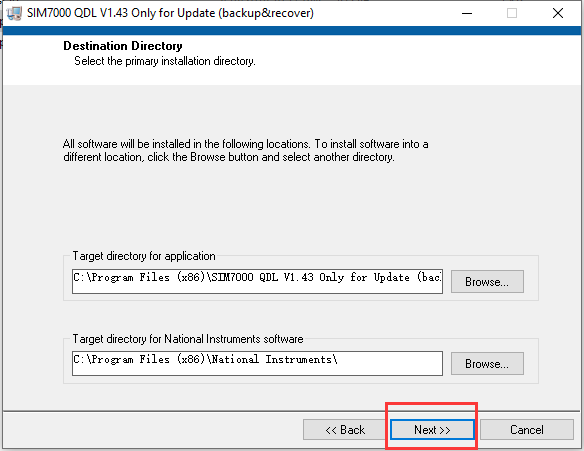
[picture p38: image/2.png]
    
    
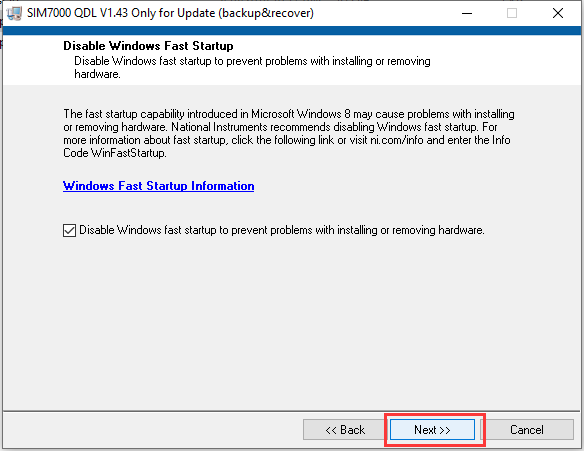
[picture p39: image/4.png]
    
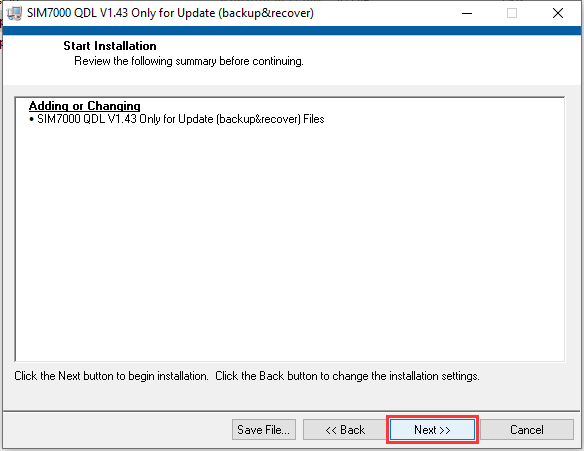
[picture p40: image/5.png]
    
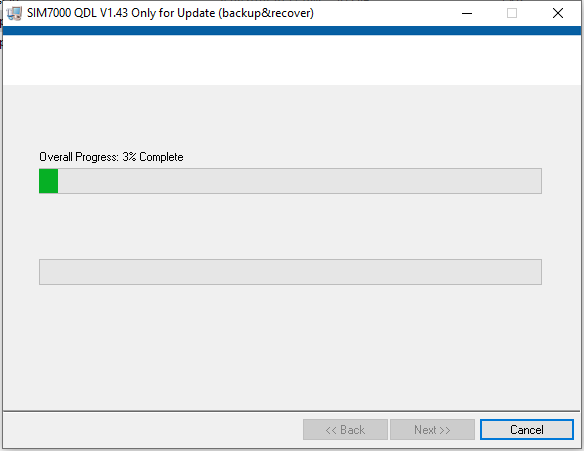
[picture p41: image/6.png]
    
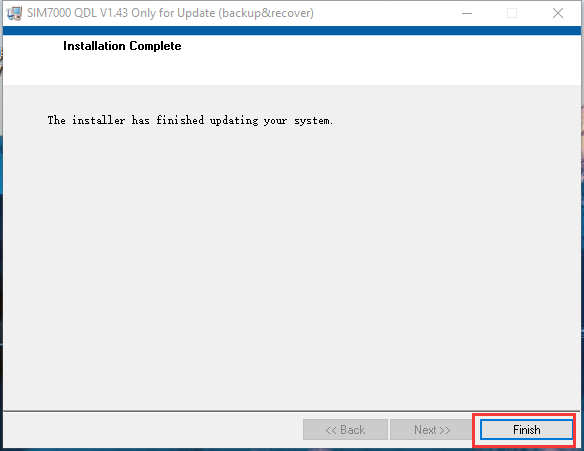
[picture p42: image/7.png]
    
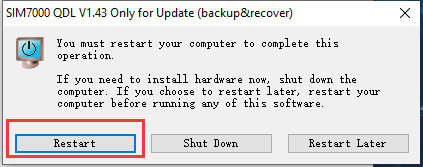
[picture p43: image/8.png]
    

8. Open the upgrade tool and follow the diagram below

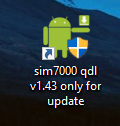
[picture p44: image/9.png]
    
    
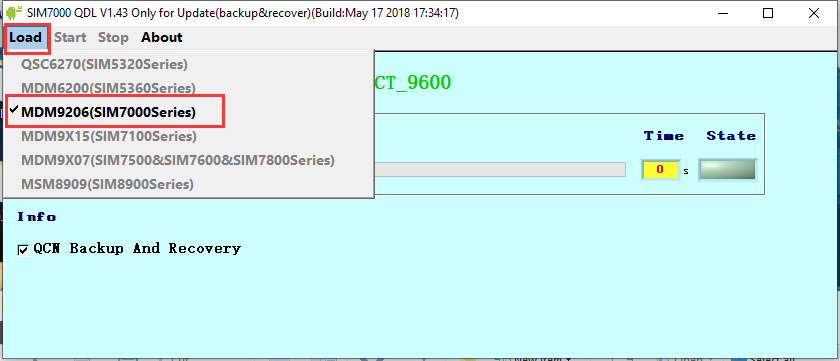
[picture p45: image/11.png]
    
    
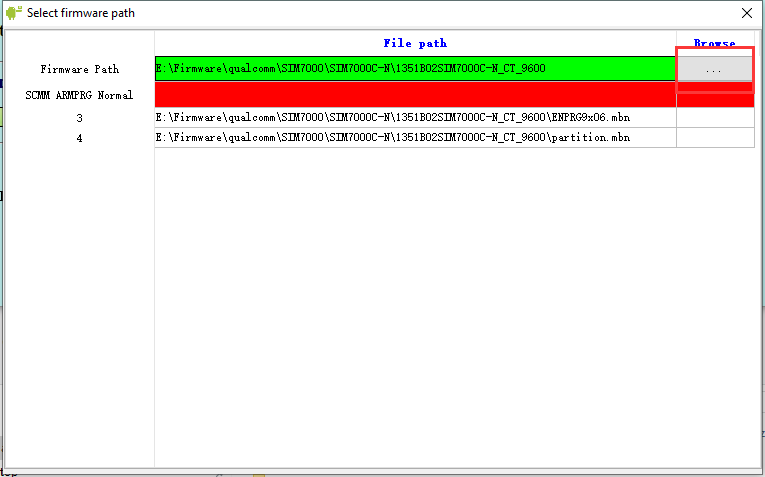
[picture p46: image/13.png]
    
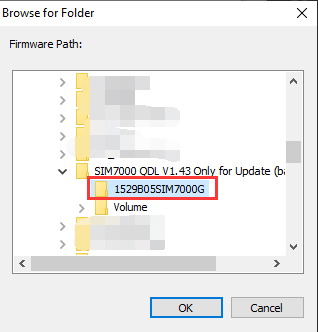
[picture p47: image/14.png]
    
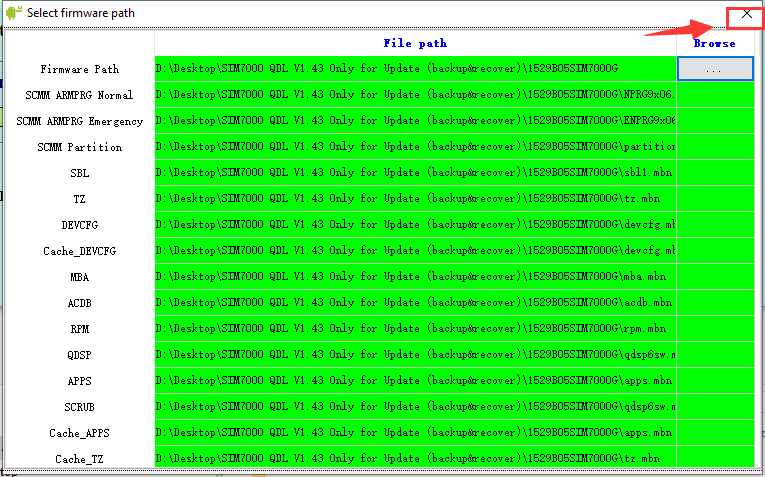
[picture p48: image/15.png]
    
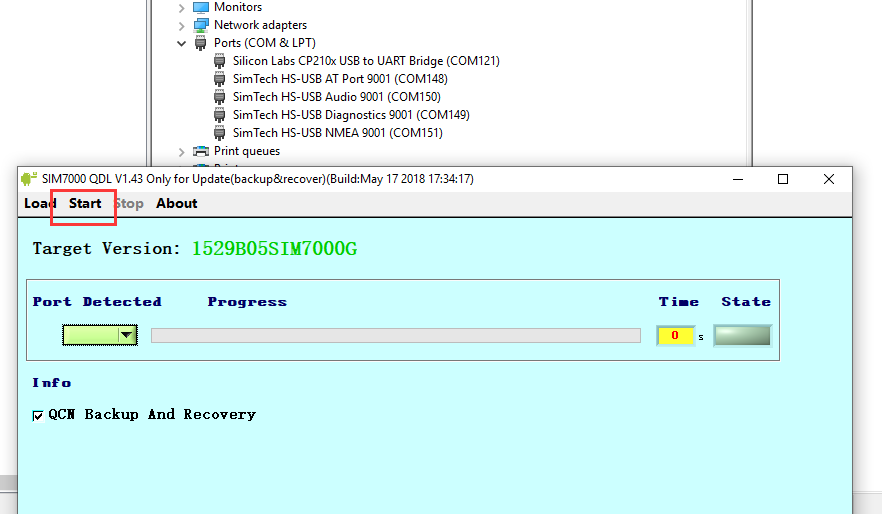
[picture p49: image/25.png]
    
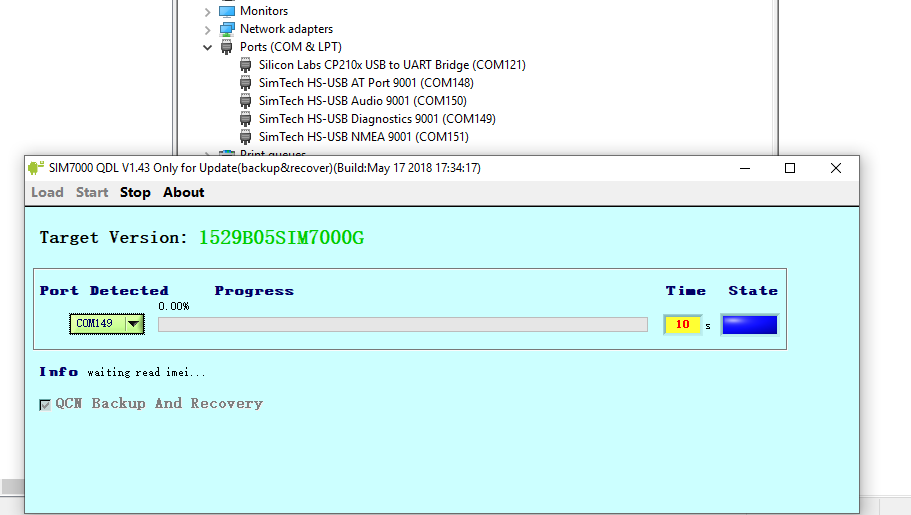
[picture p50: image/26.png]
    
    Note that when the following figure is executed, it will prompt that the new port has no driver installed. After adding the driver according to the above steps to install the driver, click Start again to update.
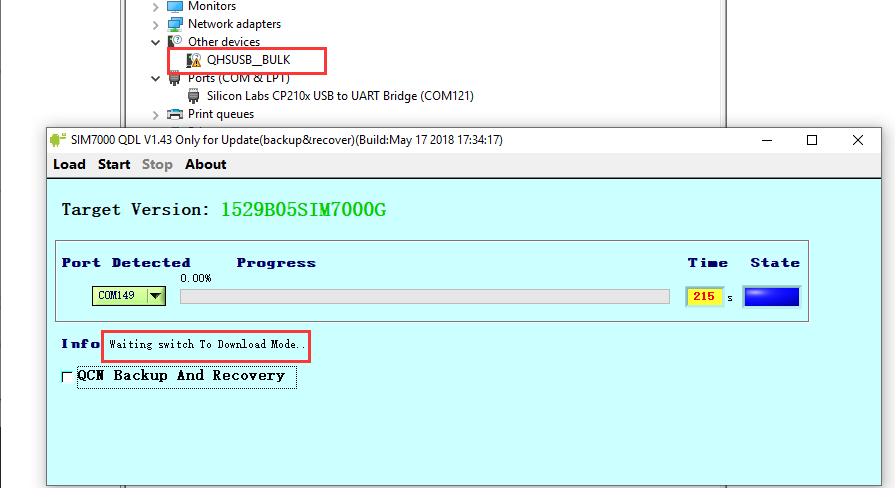
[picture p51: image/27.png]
    

    When prompted `Update Success!`, click Stop to stop the update. At this point, the firmware update has been completed.

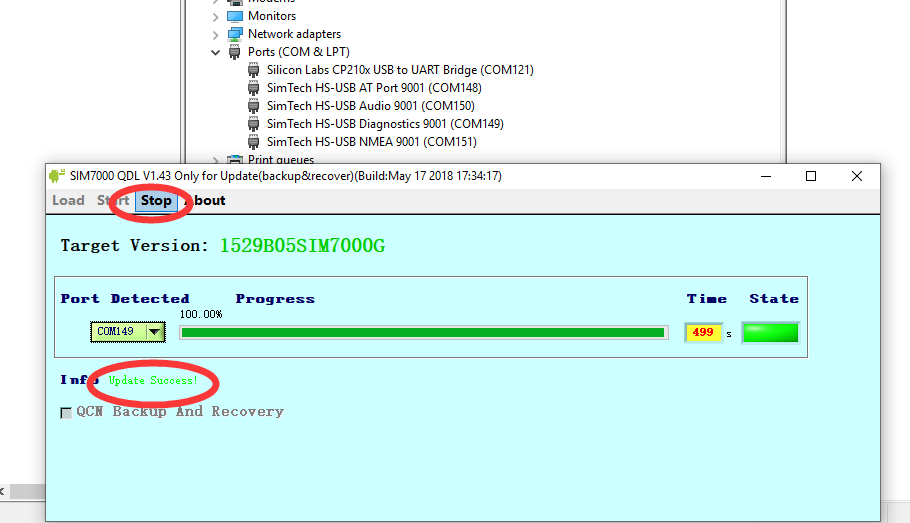
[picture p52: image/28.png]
    

9. Open the serial terminal tool, or the built-in serial tool of `Arduino IDE`, select `AT Port` for the port, and enter `AT+CGMR` to view the firmware version
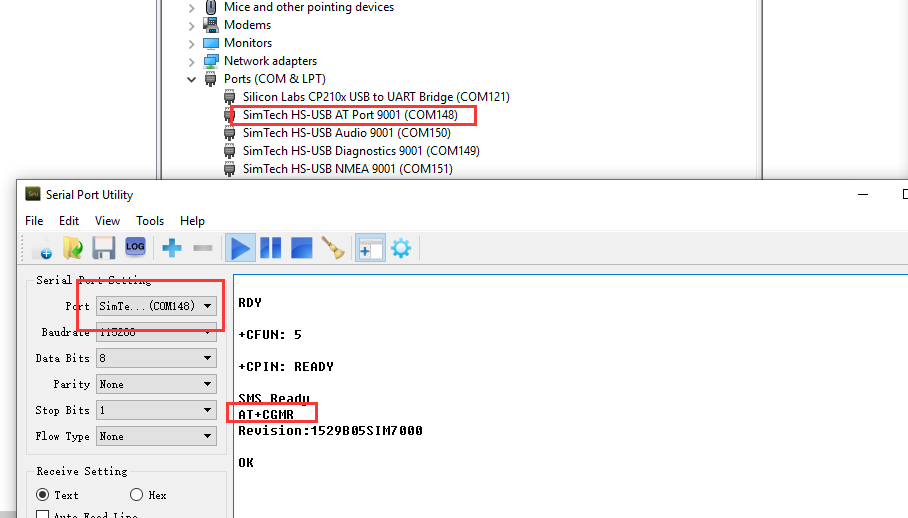
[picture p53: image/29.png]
    

## Resources

- [SIM7000X FlashTools](https://1drv.ms/u/s!AmbpOqVezk5drS1BascoH0_8EjTT?e=um3Q6A)
- [SIM7000X Dirver](https://1drv.ms/u/s!AmbpOqVezk5drS-ateuVXXDK1ulv?e=PN9QdC)
- [SIM7070  FlashTools](https://1drv.ms/u/s!AmbpOqVezk5dsHJDMvza3wE8961_?e=sa9zT8)
- [SIM7070  Dirver](https://1drv.ms/u/s!AmbpOqVezk5dsHJDMvza3wE8961_?e=sa9zT8)
<!-- - [1529B10SIM7000G Firmware](https://drive.google.com/file/d/105Jix1EYtxPomX5H1_2VmJphmYDoCYPJ/view?usp=sharing) -->
- [1529B11V01SIM7000G Fixed MQTTS,HTTPS](https://drive.google.com/file/d/12rZ9b7z3ONCPwtevOcz3khYl5vw4zGL3/view?usp=sharing)
  
## Note

If you need to update the 7070G internal firmware, please select the model below to update

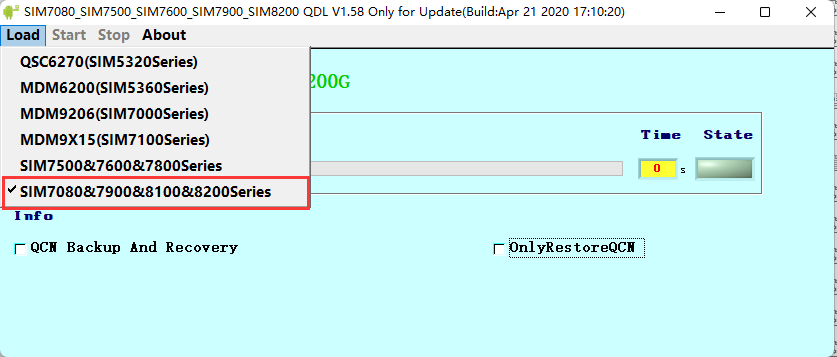
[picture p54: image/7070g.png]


Note: the modem must be kept powered on during the procedure; upload an appropriate sketch (such as [ATdebug.ino](/examples/Arduino_TinyGSM/ATdebug/ATdebug.ino)), as needed.

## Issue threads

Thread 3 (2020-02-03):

Deep sleep power consumption

ClemensGruber, 2020-02-03:
Has someone tested the power consomption in deep sleep already. I found on

http://www.lilygo.cn/prod_view.aspx?TypeId=50033&Id=1246
> Sleep Current: 1.2mA

This would be more than the previous model, the TTGO T-Com needs. SIM7000 should be much less power hungry in deep sleep. And I think there are some mechanisms to switch off power compeletely for the SIM7000? [At least it was discussed. ](https://github.com/Xinyuan-LilyGO/LilyGO-T-SIM7000G/issues?q=is%3Aissue+is%3Aclosed)

nikil511, 2020-02-05:
yes, I have tested it and was near ~1mA
https://github.com/Xinyuan-LilyGO/LilyGO-T-SIM7000G/issues/4

ROSW6341, 2020-02-08:
Was the current measured with an active GPS antenna connected?

ROSW6341, 2020-02-08:
I'm not sure this pertains to the issue of unexplained deep sleep power consumption, but are the signals to the source and drain of Q7 (V_BAT & VVBAT respectively) by chance reversed?

eiriksels, 2020-02-10:
Hi.

I have done some initial testing and I think it is draining the battery much faster than I expected. I first tried to just put the ESP in deep sleep, but for this board it seems that the SIM7000 stays alive(Unlike the T-Call board)? I use the TinyGSM Library.

I use this to enable sleep:
esp_sleep_enable_timer_wakeup(Time);
esp_deep_sleep_start();

I therefore included a modem turnoff command( modem.poweroff();) in addition to the sleep command.

Could you give me any advise on how you are putting the board to sleep between sending values?

nikil511, 2020-02-10:
https://github.com/nikil511/LilyGO-T-SIM7000G/tree/master/examples/Platformio_Arduino_Thingsboard

eiriksels, 2020-02-11:
@nikil511 Thanks a lot. It turns out that it was my network settings that caused the battery usage. I was actually on 2G and not NB IoT as wanted. I will create a separate issue for this setup because I have not been able to use the AT debug sketch with this board to manually set the operator setup.

eiriksels, 2020-02-12:
@nikil511 Did you disable or remove the blue onboard power-indicator led to reach the 1mA consumption?

nikil511, 2020-02-19:
@eiriksels nope...but..there is no power indicator led on my version of the hardware. :-/
(maybe something is different in the final version, I have beta hardware)

kapitan-u, 2020-02-27:
Improvement idea: 100k/100k divider for measuring battery power is causing excessive power draw.
please consider P-FET solution described here
https://fettricks.blogspot.com/2014/01/reducing-voltage-divider-load-to-extend.html
for future versions

ROSW6341, 2020-02-27:
Improvement idea #2:  The GPS antenna circuit applies supplies power for active antennas.  Unfortunately there is no means to switch the power off when the SIM7000 is shut down.  An active antenna will continue to draw about 10mA even when the ESP32 and SIM7000 are shut off.  A P-channel FET could be used as a switch with an N-channel FET's drain tied to its gate to act as a level converter (the 4+ volt battery supply is too high for either the ESP32 or the SIM7000).  The N-FET's gate would be tied to the SIM7000 1.8v V-EXT.  Pulling the N-FET's source low would enable the switch.

ROSW6341, 2020-02-27:
In response the kapitan-u's post.  The 100K/100K divider would draw about 20 uA assuming a battery voltage of 4 volts.  A reasonable assumption for the capacity of a 18650 battery is in the area of 3000 mAH.  So it would take about 150,000 hrs for the resistor divider to deplete the battery.  An active antenna with the current feed circuit will draw 500 times as much.

nikil511, 2020-03-11:
@ROSW6341
I tested sleep consumption with GPA antenna connected and its 36ma (!)
Tried AT+CGNSPWR=0 same thing
AT+CVAUXS=0 gives error

So, yes, I confirm there is a serious sleep current consumption problem!

Elmi77, 2020-05-28:
So can anybody recommend a passive GPS antenna that works with this board?

yevgenb, 2020-06-08:
Can we power off SIM7000 or GPS only completely to reduce consumption?

ROSW6341, 2020-06-08:
I retested the current draw in deep sleep mode with an active GPS antenna on v1 of the board.  This and the previous test above were done using an in-line USB voltage/current meter.  The previous reading of 36ma was in error because the USB com port was open being monitored by a terminal emulator.  The new reading of 16ma was taken with the same setup but without opening the com port (no terminal emulator).  That value is more in-line with what I would expect for the current drawn by the green 'battery charged' LED and an active GPS antenna.

ROSW6341, 2020-06-08:
> Can we power off SIM7000 or GPS only completely to reduce consumption?

Both can be powered off.  See the SIM7000 Series AT Command manual.  The SIM7000 Hardware Design documentation describes an additional way to power off the SIM using the PWRKEY.

ROSW6341, 2020-06-08:
So can anybody recommend a passive GPS antenna that works with this board?

The next version of the board (now available on AliExpress) has a means to control the power to an active GPS antenna.

Elmi77, 2020-06-14:
> So can anybody recommend a passive GPS antenna that works with this board?
>
> The next version of the board (now available on AliExpress) has a means to control the power to an active GPS antenna.

Sounds good! How can one recognise if the correct (new) version is offered? I think there are a lot of older boards still floating around...

Mr-HaleYa, 2020-06-16:
@ClemensGruber The new version has better power consumption due to the GPS antenna now being able to be completely disabled, If your question has been answered please close your issue

ClemensGruber, 2020-06-16:
I do not use the GPS function so I'm interested in the lowest possible deep sleep power consumption. We have a long term measurement project with solar power support. I found values between 1 mA in sleep mode and 7 uA in power off mode for the SIM7000x series, see https://www.simcom.com/product/SIM7000X.html so I wonder why there is still a sleep current of about 750uA on the web page. Has someone tried do power off the SIM7000 and measured the depp sleep current of the new version?

lewisxhe, 2020-06-18:
The new version has been updated, the issue will be closed, if there are other issues, please open the issue

ClemensGruber, 2020-06-18:
@lewisxhe you are writing at https://github.com/Xinyuan-LilyGO/LilyGO-T-SIM7000G/issues/11#issuecomment-626593667

> About the latest version, the test has been completed, and the final test sleep is about 300uA.

But on the product page https://www.aliexpress.com/item/4000542688096.html you can read Sleep Current:Without GPS antenna, sleep current is about 750uA

May you share your deep sleep testing code? And do you know why there is a far higher amount on the product page?

lewisxhe, 2020-06-18:
I have told them to let them delete, this sleep current is only the old version, the new version of the sample code when the test is completed, go to sleep about 300uA, this is my actual test!
@ClemensGruber

javipelopi, 2021-03-10:
@lewisxhe hi!

I would also like you to upload the code you used to get to 300uA and to know if you desoldered something to get to that consumption.

Thanks in advance and amazing job you are doing here!

ishdemon, 2022-07-21:
i got rid of the antenna all together..SIMCOM's onbaord GPS is pretty bad..paired a BN-220(Very small). GPS fix within 15 seconds , battery life has greatly improved.

Closed 2020-06-18.

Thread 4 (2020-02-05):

T-SIM7000 evaluation and improvements

nikil511, 2020-02-05:
I have been playing with T-SIM7000 since December last year. We got some beta hardware, slightly different to the one on sale today.

I can confirm that everything works as it should, including NBIoT with PSM sleep (~1mA)
So overall very nice module, low power, connects to network even with battery at 2.8v.

Issues found so far:
1) was missing 100k resistor from BAT voltage divider (this could be because of beta hardware)

2) SOLAR input +/- marking is under the plug, thus not visible. Also its better to reverse the plug to be seeed-studio solar panel polarity compatible (in my point of view). Keep in mind that a solar bellow 1W will not charge the battery. (1W@5V = 80x100mm). Would be nice to start charging from 0.5W for use-cases that TSIM is not uploading very frequently or when there are clouds.

3) battery drain auto-boot seems ok but not perfect. It only pulls 35μΑ at 2.7V and everything is turned off (ESP32 and 3v3 line off). However, when solar power is provided and the battery has recovered, **sometimes** ESP32 boots in to "download mode" so it is working, but still needs a reset button :-( Some kind of reset supervisor or battery cut off protector should be used to make sure that ESP32 boots properly when power is recovered slowly via solar.

4) SIM socket adapter is easy to brake, replace with a better one.
We have x10 T-CALLs on the field (same sim adapter) and some of them broke during attempts to replace sim cards. I think the sockets that you slide the sim-card inside are safer more robust. (also they could be used a JTAG debugger )

lewisxhe, 2020-02-07:
The situation you said, we will test it, thank you for your feedback

nikil511, 2020-02-19:
@lewisxhe I performed more tests. The empty-battery-solar-charge boot problem happens only with one of the modules I have. The other one always boots fine. So maybe some component value is on the borderline.

lewisxhe, 2020-02-28:
I do n’t have T-SIM right now, I ca n’t do more tests. When T-SIM arrives, I will do more tests on power consumption. After the test is complete, I will summarize the summary of the next revision.

Mr-HaleYa, 2020-06-16:
1. was fixed
2. the markings were moved (the plug was not reversed 😞 but probably best bc my circuits would explode now)
3. this seems to be fixed with the new board (boot correctly when I charge from dead with solar)
4. same socket, unfortunately. they should have a more robust one

If you feel your issue has been resolved, please close 🙂

lewisxhe, 2020-06-18:
The new board has been improved design, this issue will be closed

javipelopi, 2021-03-10:
Hi!

@nikil511 why do you say " Keep in mind that a solar bellow 1W will not charge the battery. (1W@5V = 80x100mm)." ?

Is it a limitation of cn3065 chip? Has it been solved in the final version?

Thanks in advance!

Closed 2020-06-18.

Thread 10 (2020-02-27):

SIM7000 nRESET overvoltage protection

ROSW6341, 2020-02-27:
The nRESET pin on the SIM7000 has a maximum input voltage of slightly over 2 volts.  The GPIO5 pin from the ESP32 can go as high as 3.3 volts.  Several options exist.  The first is to put a diode between the SIM7000 RESET pin and the rest of the circuit.  The second is to simply disconnect the pin completely from the circuit.  The SIM7000 hardware manual states "Note: This function is only used as an emergency reset. The RESET pin will be ineffectiveness in the power off mode.".  I've been testing several SIM7000 modules without ever needing to use the reset feature.  The third option is to leave the circuit as-is but state BOLDLY to configure the ESP32 GPIO5 as **OUT_OPEN_DRAIN**!
Personally I prefer option 2.  And it frees up a pin on the ESP32 which could possibly be used to switch power on & off to the GPS antenna circuit.  See my entry in the "Deep sleep power consumption" thread.

lewisxhe, 2020-02-28:
The SIM7000 reset pin will be removed. It will be used as a free GPIO in the next revision. I will test the antenna current. @ROSW6341

lewisxhe, 2020-02-28:
I do n’t have T-SIM right now, so I ca n’t do more tests, I ’m waiting for the board

Mr-HaleYa, 2020-06-16:
@ROSW6341
A new version of the board has been released (20200415) Please have a look at the schematics

---
If you feel your issue has been resolved, please close  🙂

Closed 2020-06-16.

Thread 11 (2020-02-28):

Comments for the next revision

lewisxhe, 2020-02-28:
I tested on the hardware of T-SIM 20191211 version and got the following results

All tests use a timer to wake up from sleep.

1. Use GPS antenna (No. 1), remove LORA module, sleep current is about 12mA

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

2. Use GPS antenna (No. 1), connect to LORA module, sleep current is about 5.6mA (the unit of ammeter in the upper right corner is A)
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

3. No GPS antenna, no LORA module, sleep current is about 750uA (the ammeter unit in the upper right corner is uA)
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

4. No GPS antenna is used, there is a LORA module, and the sleep current is about 2mA (the unit of the ammeter in the upper right corner is A)

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

Based on this, provide feedback to the LilyGo team as a reference for the next revision

1. Remove SIM7000 NRESET, release GPIO5, will be used in Lora expansion board
2. Reset the GPIO Pin to release the HIGH SPEED SPI Pin
4. GPS active antenna has leakage current during deep sleep, increasing power control, this part of the circuit can be closed when GPS is not used
5. Add power monitoring IC [DIO6809S](http://www.dioo.com/uploads/product/20190312/eed546a7a6148e82e3d785879360556a.pdf)
6. ADC power monitoring plus Mos tube control [P-FET solution](https://fettricks.blogspot.com/2014/01/reducing-voltage-divider-load-to-extend.html)
7. Use the new pin layout:

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

8. Add GPIO0 as an external button, you can manually download when the automatic download circuit fails
9. To reduce external noise, connect a 0.1uF capacitor in parallel with the ADC pin
10. Change the power supply to PMIC, the specific selection must also consider

ROSW6341, 2020-02-29:
Thanks for the update. I believe several things should be reconsidered.  The DIO6809S will hold the processor in RESET mode when it detects low supply voltage, however it is quite possible the current the ESP32 draws in reset is higher than when it is in deep sleep.  And while in forced reset, the ESP32 cannot report its condition. Therefore I do not believe the DIO6809S is advantageous to the project.
Also I do not believe adding the P-FET control will impact battery usage in any significant way.  The two 100K/100K voltage dividers draw a only total of about 40uA.  And the P-FET control as depicted in the link has drawbacks having to do with the capacitor in the circuit.
And finally the ESP32 ADC are known to be inaccurate.  A means to self calibrate them is to add (another) 100K/100K voltage divider between VCC3V3 and ground then feed the mid point to an ADC input.  By first measuring it (3.3v / 2) the ADC value can then be used to adjust the other two ADC readings and report accurate values.

lewisxhe, 2020-02-29:
The fourth and fifth are suggestions from other users. I just list them here. The design needs to be reconsidered. I also think that adding a reset IC is not a good idea. The current consumption of the P-FET is very small. I think it can be ignored.

Regarding these suggestions, 1,2,3,6,8,9,10 are my personal suggestions
@ROSW6341

lewisxhe, 2020-02-29:
If PMIC is used, I think ADC should be removed

ROSW6341, 2020-02-29:
The P-FET circuit as depicted has a problem when the divider is kept enabled too long.  The capacitor will charge up disabling the divider and it cannot be re-enabled until the control signal goes high for a significant enough time to discharge the capacitor.  A diode across the capacitor would at least allow for re-enabling the divider more quickly.  Adding the circuit would be at the cost of 2 or components to save 40uA of current draw on a design that has a relatively large battery with a solar panel charger.
I did not see a control signal in your pin assignments for the GPS antenna power switch.  It might be possible to control it via a SIM GPIO pin but I have been unable to determine what state they are in while the SIM is in power down mode.
I do not understand how the use of a Power Management IC (PMIC) could invalidate the need for the Analog to Digital Converters.

lewisxhe, 2020-02-29:
PIMC is similar to AXP192 and AXP202, but they are not currently used because the SIM800 startup current is too large, leading to PMIC protection. I am conducting another PMIC test, adding soft start to reduce the startup current, and I used SIM800L An upgraded version of SIM800C is used as the test object. If all goes well, the battery test can be removed because the PMIC already has a complete test function. @ROSW6341

ROSW6341, 2020-02-29:
Sorry, one more comment.  I realize I come to this project late but I believe adding LORA to the design would result in less optimum results for both NBIoT/LTE Cat-M1 and LORA (cost, complexity, etc).  Both are intended for similar purposes and would very likely not be used at the same time or in the same installation.  I think splitting the project into two projects would provide better solutions for both. Both would use the ESP32 and basic support circuitry but one would use the SIM7000 while the other would use LORA.

lewisxhe, 2020-02-29:
Yes they are not together, lora is just an extension module, i believe few people will let them work together

ROSW6341, 2020-02-29:
OK, now I understand about the PMIC.  I has an ADC with multiple inputs eliminating the need to use the ESP32's ADC.  I haven't had a chance to check its details but hopefully its adc circuity can accept the voltages from the battery and solar panel without the voltage dividers.

lewisxhe, 2020-02-29:
Oh! I even said the wrong topic. The SIM800 mentioned earlier is T-Call. Haha, I will continue to upgrade the SIM7000!

ROSW6341, 2020-02-29:
But if LORA is an extension module the SIM7000 will be there (unused, but adding cost and restricting the use of unavailable ESP pins) when the LORA is needed.  I still think two sister designs, one with the SIM7000 and the other with LORA.

ROSW6341, 2020-02-29:
Obviously the future of this design is not my call.  I have a product design in works for which the ESP32 & SIM7000 appear to be ideal and the design you have when I learned of it fit very nicely.  I'm making suggestions based upon the assumption the design is to a product board and not a development board.  The latter is used to develop a product which when completed, is revised to remove components and features that were needed solely for development.

lewisxhe, 2020-03-01:
Ok, thank you for your comments. We will listen carefully! @ROSW6341

kapitan-u, 2020-03-03:
In response to:
>  The DIO6809S will hold the processor in RESET mode when it detects low supply voltage,
> however it is quite possible the current the ESP32 draws in reset is higher than when it is in deep > sleep. And while in forced reset, the ESP32 cannot report its condition. Therefore I do not believe > the DIO6809S is advantageous to the project.

idea is not holding ESP32 in reset but use DIO6809S as wake up signal source, also it will draw less current that 100k/100k divider

ROSW6341, 2020-03-03:
OK, I understand but what is the ESP32 going to do once it wakes up and realizes the voltage is too low?  It might be better off staying in Deep Sleep giving the solar panel time to recharge the battery.  Also if the battery voltage is periodically reported in the application's messages, a low battery condition could be recognized and dealt with before it got too low.
Every part in an embedded design should justify its cost and the more parts the higher the possibility of some failure mode.

kapitan-u, 2020-03-03:
Consider flood sensor application. Battery powered device expected ti sit at the basement for 10 years. Reporting only flood event and weekly status.

lewisxhe, 2020-03-04:
If you use DIO6809S as the wake-up source, then I do n’t recommend it. You can use the ulp coprocessor to detect during esp32 deep sleep.
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
ROSW6341, 2020-05-19:
I generally have not had a problem with getting the SIM to power up.  Power down has been the problem.  On occasion it does not acknowledge the receipt of the command leaving only the PWR KEY.  I've monitored the board current via a device in series with the USB and have seen the attempt fail (the current stayed in the 70mA range).  Being able to monitor the STATUS pin would allow the code to take additional steps to power off the SIM.

ROSW6341, 2020-05-20:
I've had the opportunity to study the schematic a bit and found a couple of things that might not be quite right.  First the CN3065 (U13) has an operating range up to 6v with an absolute max of 6.5v.  The zener diode D3 that protects it from over-voltage from the solar input is currently a 6.8v zener (WC).  It should probably be changed to a 5.6v zener (WA) which has an upper tolerance limit of 6v.  Second, U16 the VBUS-VCC4.2V step down converter is shown with a part number of JW52222.  I believe the part number should be JW5222.
The board looks like it will be a good development platform, especially with all the LEDs.  I'd like to request if possible, that all LEDs that cannot be controlled via code (STATUS, CHRG, STDBY) have cut-jumpers placed in series somewhere so they can be optionally disabled for product deployment by cutting the jumper.  NETLIGHT is OK because it can be controlled via code.  I understand if this cannot be done because of board size constraints or other reasons but thought I'd ask just-in-case.

lewisxhe, 2020-05-21:
The new version is already in production, and the changes will not be implemented temporarily. But another PCI-E version will leave the state to connect to ESP32

domojega, 2020-05-21:
Hi to all! I am newbie here so apologize if I say/write something dumb or uncl3ar, but would like to add my 1 cent here. Putting an accelerator/gyro MEMS in the board would be quite useful, adding the possibility to sense movement/theft/earthquake/ whatever...

kapitan-u, 2020-05-22:
Agree 100% having MPU9250 would be great. However there must be an option to have it powered while ESP is in deep sleep, so MPU may wake it up on motion.

lewisxhe, 2020-05-22:
Adding an IMU to the board will undoubtedly increase the cost, and not everyone needs it, you can use an external module to add it directly

domojega, 2020-05-22:
I agree that the price matters but at least, when I do the redevelopment, I try to include all relevant and possible scenarios on the PCB so, putting the placeholder on the PCB is a quite good and cheap option. If anyone wants to have a MEMS on its board, let them just solder one. Adding modules and increase the volume of the device is rather unpopular for me... I would rather see the board with the 18650 as an optionl (if you want it, then buy and solder it) and would just place a connector for the LiPo...
Also, software support with examples is miserable and you should provide more instructions on howto basis. But, anyway, the module itself is bullseye.

ROSW6341, 2020-05-28:
Two questions: 1) Will the existing version still be available or will it be replaced by the new version? 2) Any idea when the new version will be available for beta testing and/or sale?

nikil511, 2020-05-28:
Got the new ones today, so they must have more. Check their AliExpress page
(or contact lilygo directly)

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

ROSW6341, 2020-05-28:
Thanks for the info.  Just order 3.  Hope these get here faster than the last version 1 boards.

ClemensGruber, 2020-06-18:
> I'd like to request if possible, that all LEDs that cannot be controlled via code (STATUS, CHRG, STDBY) have cut-jumpers placed in series somewhere so they can be optionally disabled for product deployment by cutting the jumper.

This is really important! Thanks to point this out @ROSW6341! It makes no sense to optimize power consumption at different areas and burn power with "stupid" LEDs. This may be helpful for debugging but is useless in a low power szenario. Please have this low power setting always in minde when developing a solar and GSM/LTE board!

Closed 2020-06-12.

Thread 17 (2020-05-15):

Specification incomplete - solar voltage input range?

Elmi77, 2020-05-15:
As is can't find this information anywhere: what is the allowed input voltage range at the JST solar input connector?

Thanks!

nikil511, 2020-05-19:
v1 that is available at the time of writing this uses TP4056
ABSOLUTE MAXIMUM RATINGS ·Input Supply Voltage(VCC)：-0.3V～8V
But for solar to charge the batteries you need >4.5v
long story short, use a **5.5v or 6v panel**

Elmi77, 2020-05-25:
Cool, thanks!

ROSW6341, 2020-05-28:
Foe protection the TP4056 has a 6.8v zener diode across the input from the solar panel.  Most nominal sized panels will have a noticeable voltage drop when charging the battery.  The voltage from my 4"x6" 6 volt panel drops to below 4 volts in all but very bright sunshine.  I decide to use a panel designed to charge a 6v SLA battery.  It has an unloaded output of over 9v.  Instead of imposing a linear regulator, I chose a step down switching regulator with an output voltage of 5v.  The excess voltage is converted of available current by the regulator.  I found complete modules on Amazon at 5 for $8.

ROSW6341, 2020-05-28:
Correction, the modules I purchased were $9 for 5 and I have not tested them in the field.  There are other modules on Amazon at lower prices.  One that shows up frequently is labeled Mini360.  In perusing information about it, I came across a review where the author did extensive testing and found they were not very efficient. <https://goughlui.com/2018/07/04/tested-mini-360-mp2307-based-3a-buck-converter-module/>.

Mr-HaleYa, 2020-06-11:
@Elmi77 Close this if you have solved your problem

Mr-HaleYa, 2020-06-17:
@Elmi77
The new board (20200415) uses a CN3065 chip to charge. Looking at the schematics there is no protection IC for it so the charging range is now 4.4v to 6v

I have submitted a PR that adds this info to the readme so others will know

---

If You have solved your issue please close 🙂

Mr-HaleYa, 2020-06-24:
@Elmi77 @lewisxhe
The question has been answered and added to the readme
this can now be closed

Closed 2020-06-24.

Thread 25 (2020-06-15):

No GSM network functionality - waitForNetwork() never succeeds

Elmi77, 2020-06-15:
I'm initialising all the GSM-stuff based on the code out of the all-functions-example. Unfortunately this does not work, waitForNetwork() never returns with true. When calling modem.getSignalQuality() right before waiting for the network, it shows me a signal quality of 99. What I already have tried:

- the board is battery-backed, so there should be enough power
- the SIM card is verified to work (done with an Android device)
- I tried a second antenna as replacement for the original one
- I added a call modem.sendAT("+CFUN=1") right after modem.restart() to ensure radio is powered

All this did not help. So: what could be the reason for the troubles? What could I try in order to get it working?

rakaandro, 2020-06-15:
I made a echo terminal for the TTGO-SIM7000G, you can send AT commands over USB-Serial to the modem.

check if PIN is okay
check available networks and so on ..... The is a .pdf out there with all the commands.

```
/***
           Echo terminal for TTGO T-SIM7000G
           open USB-COM Port with a terminal programm and send AT commands
           directly to Sim7000G (over the ESP32)

           by RaKa 06/2020  
 ***/

#include <HardwareSerial.h>

// modem connections
#define MODEM_TX 26
#define MODEM_RX 27
#define MODEM_RST 5

void setup()
{
  Serial.println("Modem hardware reset first ....");
  pinMode(MODEM_RST, OUTPUT);
  digitalWrite(MODEM_RST, LOW);
  delay(260); //Treset 252ms
  digitalWrite(MODEM_RST, HIGH);
  delay(4000); //Modem takes longer to get ready and reply after this kind of reset vs power on
  Serial.println("Modem hardware reset ready!");

  //start serial connection
  Serial.begin(115200);

  //Serial1 at pin 12 and 13
  Serial1.begin(9600, SERIAL_8N1, MODEM_TX, MODEM_RX);
  Serial.println("ready. Enter AT commands:");
}

void loop()
{
  int data;
  //wait for terminal commands
  while (Serial.available())
  {
    // send data to Serial1 (SIM7000G)
    data = Serial.read();
    Serial1.write(data);
  }

  //wait for data from Serial1 (SIM7000G)
  while (Serial1.available())
  {
    //send received data to terminal
    data = Serial1.read();
    Serial.write(data);
  }
}

```

lewisxhe, 2020-06-16:
What frequency band SIM card are you using?
The default example uses setNetworkMode, 51 as the preferred parameter. Does your country still support 2G? I tried sometimes it is difficult to connect using 51, and it takes a long time to connect, if your country still supports 2G, you can change 51 to 13 to try!

Mr-HaleYa, 2020-06-16:
America has killed 2G (T-Moble is the last with it but they are quickly phasing it out). T-moble is also shutting down 3G so you may be having problems based on carrier

Elmi77, 2020-06-16:
> I tried sometimes it is difficult to connect using 51, and it takes a long time to connect, if your country still supports 2G, you can change 51 to 13 to try!

13 seems to work. Amazingly the description in example code says this is GSM!?
I hadit set to 2 (automatic) but it seems the automatism isn't that automatic :-D

Mr-HaleYa, 2020-06-17:
@Elmi77
Ya, the boards can be finicky sometimes and that is mostly attributed to how the tinyGSM library functions.

---

If you have solved your problem, please close 🙂

Closed 2020-06-17.

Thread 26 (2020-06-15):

General question about solar

Mr-HaleYa, 2020-06-15:
what is the operating voltages of the solar panel? I have 5 volt panels, 6 volt panels and 12 volt panels. What is the recommended voltage and wattage?

Elmi77, 2020-06-15:
According to https://github.com/Xinyuan-LilyGO/LilyGO-T-SIM7000G/issues/17 input voltage should be less than 8V, but I'm not sure if something has changed with the new 2020 hardware revision.

Elmi77, 2020-06-15:
...and please keep in mind the maximum voltage of a solar panel is always bigger than the nominal voltage!

Mr-HaleYa, 2020-06-16:
Its 5.5v to 6v If anyone else is looking for this

ro85ac, 2020-07-22:
@Mr-HaleYa I am using the device with a 6W 6V  solar power.  Data every 15 seconds to the cloud by wifi. As you can see in the attached picture, I cannot understand why the battery is not charging when there is voltage in the solar panel.

Do you have any ideea?

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

Mr-HaleYa, 2020-07-23:
I believe it has mppt power tracking which basically only charges when the sun is at an optimal angle using math to calculate the best voltage because I'm like a battery or solar panel can only Supply a certain amount of current so you have to charge when it's at its highest voltage and current or else you draw too much power and the voltage will drop below what it can actually be charged with. Something like that...

I use an external solar charger because my panels are 12-volt and don't work with the 6-volt input and I get the exact same thing because that's how the solar chargers work it is very bad for your batteries to sit at the max capacity for an extended period Of they will literally explode.

As long as it is charging to the 4.2 max voltage at least once a day or whenever you need it then it's it should not be sitting at 4.2. It should hit 4.2 and then tomorrow charge back to 4.2

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

ro85ac, 2020-07-23:
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

The solar panel stays during day at 4.2V and drops to 0V during night, but the battery keeps discharging. I am using the cayenne project. Am I using a wrong solar panel or the board is not working properly ( I have an oldder version --- the one from January )?

Mr-HaleYa, 2020-07-23:
@ro85ac
Are you saying that it never fully recharges and instead is slowly dropping over time?

ro85ac, 2020-07-23:
@Mr-HaleYa
Yes, as you can see on the first graphic, the battery never recharges. It keeps dropping.

Mr-HaleYa, 2020-07-23:
can you please share a picture of the solar panel with something easy to compare sizes such as a US quarter  or a soda can

ro85ac, 2020-07-23:
@Mr-HaleYa
This is the link where I bought the solar panel. It's the model 6V 1000mA size (170mm x 230mm)
https://www.aliexpress.com/item/32877917510.html

Mr-HaleYa, 2020-07-23:
hmmm I have some similar panels that are 6v and they charged mine in a couple of hours and I had 4 18650s in parallel so the capacity was much higher. How many panels do you have?

ro85ac, 2020-07-23:
@Mr-HaleYa I have one battery and one solar panel. 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

Mr-HaleYa, 2020-07-23:
please continue this on #47

Closed 2020-06-16.

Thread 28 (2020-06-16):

Use external battery...

Mr-HaleYa, 2020-06-16:
Ok, so I desoldered the battery-pack that is on the board and was trying to use one that has 3 x 18650 in parallel just for more capacity.
How do you connect this correctly? do I need to solder my backs terminals to the + - tabs on the back of the PCB or can I use the Vbat pin and gnd?

I tried using the Vbat pin connected to my batteries + and gnd connected to the - and it would flash the blue LED then turn off (I think it was off but my script shuts it off as soon as it boots so idk) none of the other listed turned on ( I only kept the battery in for ~3 sec to hopefully not kill it if I was doing it wrong) I toggled the power switch and pressed the PWR button and nothing happened...

Sadly, I tried to flip the battery to see if that was the problem and I got Magic Blue Smoke from the TCS9208 so that is dead now... I have 5 more boards but I don't want to do that again so I am asking here

Mr-HaleYa, 2020-06-16:
oh my gosh, I'm stupid... I had it... I took a look at the schematics and the green and red led don't tun on when using the battery and the Vbat and the + on the bat back are the same pin............ 😭😭😭

Mr-HaleYa, 2020-06-16:
Is there any way for you board makers to add backward battery protection and led PLEASE it would have saved me a board... I guess I can still use the USB-c connection...

Mr-HaleYa, 2020-06-16:
I've replaced my board with a new one and Is there 5v power on the VIN pin when using Battery because none of my attached sensors are working and I can't get a read with a multimeter.

Mr-HaleYa, 2020-06-16:
So There is no 5v output if you are using a battery??? how am I supposed to use anything? what are these even made for if they can't even power a sensor to collect data? This has to be a mistake right? (3.3v isn't enough to power for what I'm doing I need 5v)

@nikil511
you seem to have experience with these boards, what is your opinion? shouldn't it have a 5v output?

lewisxhe, 2020-06-17:
VIN is a USB input. If battery power is used, there will be no voltage output from VIN. It is only input and cannot be output

Mr-HaleYa, 2020-06-17:
@lewisxhe
Thank you. After reviewing the schematics I came to the same conclusion. I was able to change out my sensors for 3.3v tolerant ones.

Closed 2020-06-17.

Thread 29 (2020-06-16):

Further source of information?

grichfitz, 2020-06-16:
Hya,
I’m about to upgrade a project from the T-Call to this T-SIM.
There is a lot of information available on the web for the T-Call, not so much for the T-SIM, because it so new.
Has anyone else found a website with more info than that is on here??
TIA

Mr-HaleYa, 2020-06-16:
@grichfitz lol nope, this is it 😄 I can try to help you if you would like. What questions do you have?

grichfitz, 2020-06-16:
Hello Mr HaleYa,
Thanks for your reply. I wasn’t expecting a questions and answer, but you help will be most helpful.

1. Can I power the board via 5v pin? And will this charge the battery? Will the board reset if power supply removed and it switches to the battery?
2. My project uses ESP_SLEEP_WAKEUP_EXT1, on pins, 12, 13, 14, 15, 25. This seems to be the max on the T-Call which gives me feedback to which pin woke it up. What pins can I use on the T-SIM? I see some of these are taken up by the SIM7000 chip.

Any help with this will be greatly appreciated.

TÍA grichfitz

Mr-HaleYa, 2020-06-16:
@grichfitz
Yes, you can power with 5v on the VIN pin (bottom right) looking at the schematics it will charge the battery. It should transfer seamlessly but I have never tried.

I use pins 18, 19, 23, 35 (25 is used by DTR but can be used if you don't require DTR which is used to wake the modem if you put it to sleep or shut it down) I'm sure more pins can be used but I have not tested others

grichfitz, 2020-06-16:
Mr HaleYa,
Your a gentleman with information, thanks.
I´ll be testing this at the weekend when the board arrives.
Thanks

Mr-HaleYa, 2020-06-16:
just letting you know... DO NOT PUT THE BATTERY IN BACKWARDS!!!!! I killed mine... #28

___
If your issue has been resolved please close 🙂

grichfitz, 2020-06-17:
What version board do you have? Version 20200415 is meant to have protection against this.

Mr-HaleYa, 2020-06-17:
@grichfitz
ha no it doesn't... Maybe if use the battery socket, but I was using an external battery pack (3x 18650 in parallel for more capacity) connected to VBAT and GND and it was all cool and dandy until I put the battery in backward then poof magic blue smoke and battery IC no longer works lol

It does have reverse solar panel connection if you connect your solar panel backward if that's what you were thinking

___

any devs reading, I think you should redo the vbat pin so it's connected in the same fashion that they positive terminal of the battery socket is connected as in you can use the on-off switch and it uses all the same circuit as the integrated battery socket. also, throw in some backward battery protection if you can.

Mr-HaleYa, 2020-06-24:
@grichfitz
refine your question, ask more questions, or can you close this since it has now gone a week with no activity?

Closed 2020-06-24.

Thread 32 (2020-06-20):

Status LED / Status Signal

kapitan-u, 2020-06-20:
It will be very useful to have SIM7000 status signal connected to ESP32 gpio and to remove status LED.
Booth measures will improve battery life.

Mr-HaleYa, 2020-06-24:
How can you connect it to the esp32 and remove it? Wouldn't that just remove it altogether?  🙃

In order to make it function as I believe you are saying. You want the esp32 to decide whether or not to allow the signal light to turn on or off, is not an easy task because you can either have the esp32 read the status of the Sims 7000g which I do not know of any library that can do that easily quickly or efficiently and then toggle the light or have the esp32 block the Flow by activating a transistor or deactivating it so that the same 7000g cannot toggle the light.

If you are that concerned about battery life take a soldering iron and pop the LED off lol

I did find it strange that they added to LEDs for Sim 7000g status in the new version. I guess the left one tells you whether it has power and the right one tells you it's connectivity status to GSM. I guess if you have GSM disabled but you want to know if the modem has power then they both come into use. For example, if you were to shut down the GSM connection when you're not using it it would still have power but the GSM indicator LED would not be blinking. I actually wish the old version was like the new version because I would shut down my GSM connection and that was the only LED on the board so then I didn't know if the board had power or not. it was installed outside on a solar panel with batteries and so I would have to sit there for 10 minutes and wait for it to reconnect or I would have to go inside and get my probe to check voltages.

lewisxhe, 2020-06-24:
This opinion is used in T-PCE. For T-SIM, the next improvement will be made after the board is sold out
The network status light can be turned off, as described here
https://github.com/Xinyuan-LilyGO/LilyGo-T-Call-SIM800L/issues/72#issue-639741563

Mr-HaleYa, 2020-06-24:
@lewisxhe
How many are left and what are you wanting to change in the next version? I want to use these as a mainboard in around 100+ devices so I'm worried if big changes are coming...

lewisxhe, 2020-06-24:
If there are no major problems with customer feedback, we will not make major changes. If you have any requirements, you can ask them.

lewisxhe, 2020-06-24:
If there are no major problems with customer feedback, we will not make major changes. If you have any requirements, you can ask them.

Mr-HaleYa, 2020-06-24:
I would really really like an improved solar charger because even with the solar charger that is in it right now I'm using a independent solar charger because it is very hard to find large solar panels that stay within the charging range. I'm using 10-watt 12 volt panels. I tried a 6 volt 5 watt panel but each panel was plus or minus 5% of that voltage and some of them were frying the boards charging circuit because they were spiking up to 7.4 volts and if the battery was already charged that voltage couldn't go anywhere and would fry the battery charger. I understand improving this would add cost but it is very necessary cost because the solar charger is not very useful in large applications it's only useful in very small garden panels for testing in your window as if it's not very robust

lewisxhe, 2020-06-24:
So, your question now is that the solar voltage input range on the board is too low?

Mr-HaleYa, 2020-06-24:
I will open an issue in the morning regarding a full explanation of what I mean and my requirements if our team is going to buy  over a hundred of these we are honestly hoping to get around 1000 within the year

Mr-HaleYa, 2020-06-24:
@kapitan-u  @lewisxhe
I think this can be closed as the question was answered and alternatives where given

Closed 2020-06-28.

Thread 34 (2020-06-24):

Questions and maybe some requests

Mr-HaleYa, 2020-06-24:
@lewisxhe
As I said in a previous issue post, My team and I are looking to buy 100+ of these boards.

I would really really like an improved solar charger because even with the solar charger that is in it right now I'm using an independent solar charger because it is very hard to find large solar panels that stay within the charging range. I'm using 10-watt 12-volt panels. I tried a 6-volt 5-watt panel but each panel was plus or minus 5% of that voltage and some of them were frying the boards charging circuit because they were spiking up to 7.4 volts and if the battery was already charged that voltage couldn't go anywhere and would fry the battery charger. I understand improving this would add cost but it is a very necessary cost because the solar charger is not very useful in large applications it's only useful in very small garden panels for testing in your window as if it's not very robust.

I see that there is not much room left on the PCB without either switching components to the bottom or increasing the size of the PCB.  It looks like some resistors could be moved to the left side of the left and right of the esp32 and the sim7000g Gould be moved down ~3mm. That would make some room for additional voltage control hardware that would greatly improve usability.

We use an mppt that has a 28v range with a 3.7v output to charge our 18650s
https://www.aliexpress.com/item/32862470804.html?spm=a2g0s.13010208.99999999.321.189c3c003qqGg6
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

lewisxhe, 2020-06-26:
I'm not an in-depth user of this board, I can only return your feedback.

Mr-HaleYa, 2020-06-28:
that would be great if you could advise them to allow a higher range of charging input via solar.

Mr-HaleYa, 2020-07-01:
If you have anything else to add, please comment, otherwise I hope you tell the engineers. I will close this since it is technically, not an issue.

fgnievinski, 2023-06-06:
@Mr-HaleYa @xyzzy42: based on your experiences, where would be the best point in this Lilygo board to connect an external solar charger -- the Vin pin or the battery connectors?

We're using the [Adafruit solar charger](https://www.adafruit.com/product/4755) whose "Load output is regulated to never be over 4.4V so it's safe for 3.3V regulators or 5V boost converters".

We're considering the following two scenarios:
1. with a a step up in Vin:
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
2. without a step up, in the battery connectors on the back of the board ([not the Vbat/GND pins](https://github.com/Xinyuan-LilyGO/LilyGO-T-SIM7000G/issues/40#issuecomment-660769873)):
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

the first scenario works but it seems wasteful considering the series of [down regulators](https://github.com/Xinyuan-LilyGO/LilyGO-T-SIM7000G/issues/237#issuecomment-1576129143) in the Lilygo board.

Mr-HaleYa, 2023-06-06:
@fgnievinski You should not comment on _old **CLOSED**_ issues... Nobody likes [Nercoposting](https://www.urbandictionary.com/define.php?term=necropost)...

___

The first scenario is a waste of a regulator.
The second is close but you would be putting 4.4v into where a 3.7v battery should be and that's bad...
Instead, connect the Lipo pad and GND on the adafruit board to where the battery would be on the back of the TTGO board.
That way the TTGO board thinks there's just a battery there but the battery is also attached to the solar charger.

I love adafruit, I worked with them and their products are excellent. 👌
I use [these ](https://www.aliexpress.us/item/3256803364381619.html) solar chargers in my production boards. They work amazingly and are very affordable

xyzzy42, 2023-06-06:
@Mr-HaleYa, do you mean here?
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

I wouldn't do that.  The load output from the adafruit charger board would then be connected to the battery protection circuit, which limits voltage to 4.2 V.

I'd connect it to the VBAT pin.  And always have the battery switch on the lilygo board set to the OFF position.

The power switch has the 18650 battery, the battery protection circuit, and the battery charger on one side, and the VBAT pin and everything else on the other.  So by going to the vbat pin and keeping the switch off, it avoids the battery protection and charger circuit, which aren't desirable with the load output from the adafruit charger board.

The 4.4V limit on the charger board load output is higher than the boost regulator voltage of 4.2V, but it should handle it fine and the 3.3V linear regulators shouldn't have a problem with the higher voltage either.

fgnievinski, 2023-06-06:
I think @Mr-HaleYa's recommendation is NOT to use the Adafruit charger's load output at all -- maybe something like this?

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

the recommendation above seems to agree with Adafruit's tech support, which made no big deal about skipping the load sharing feature (however, that was for an earlier version of the charger, whose output was NOT regulated):

https://forums.adafruit.com/viewtopic.php?p=337687#p337687

I'll also check @xyzzy42's suggestion, of connecting the Adafruit charger's load output to Vbat/GND pins on the TTGO; but, if I'm not mistaken, we have burned a board that way in the past (although I don't remember the details, maybe a USB connector was being used in conjunction).

thank you both for your input (and sorry for any disturbance)!

Mr-HaleYa, 2023-06-06:
@xyzzy42 not the charger load output... the lipo itself. if you're going to do it that way cut the switch off in the OFF position because if it's ever bumped ON it would probably kill the board, at least the charge circuit.

> NOT to use the Adafruit charger's load output at all

@fgnievinski Yes, like that. This is the way I do it on all boards, works great. Doing it this way you can use USB at the same time. just make sure the power switch is OFF.

xyzzy42, 2023-06-07:
Ok, connecting the battery directly would not have the same issue with the lilygo battery protection circuit trying to "protect" the regulated solar panel output from the adafruit charger.

The adafruit charger is a much better charger than the one on the lilygo board.  If you connect the battery directly you will lose some features.  The adafruit charger will not cycle the battery if it is fully charged and the panel can supply the needed load on its own.  This is better for battery life.  Drawing a load from the battery directly will also mess up the charge termination current.  Charging stops when the current drops below a certain level.  If the load is coming directly from the battery, there is no way for the charger to tell if charge current is going to the battery or to the load.

The reasoning for not connecting the load output of the charger to the powered device appears to have been solely because that version of the board could drive the load output to 6V+.  This would indeed be a big problem.  But the new version of the board is limited to 4.4 V and that is not much more than the 4.2 V battery limit and should be within the maximum ratings of the boost regulator and the linear regulators after it.

xyzzy42, 2023-06-07:
> Doing it this way you can use USB at the same time. just make sure the power switch is OFF.

How do you figure that?  The schematics place the charger and the battery, `VCC_BAT`, on the same side of the switch, pin 2.  So connecting USB will charge the battery with the switch in either position.

fgnievinski, 2023-06-07:
thank you @xyzzy42, I follow your reasoning. ideally we'd take advantage of load sharing, so that solar is prioritized over battery when available, to avoid cycling the battery. here's a diagram illustrating my interpretation of your proposed setup:
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
now the battery is kind of far from the load, so maybe it'd be good to use an extra capacitor, to smooth out the ~2A spikes?

Closed 2020-07-01.

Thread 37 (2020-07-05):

Does not recover after battery dies

Mr-HaleYa, 2020-07-05:
I am using the latest version of the board and have an external battery pack of 18650s that are wired in series attached to the vbat pin and ground. I am using in mppt solar charger to charge the battery pack that is attached because the onboard solar charger has too tight of voltage tolerance.

I have been using it without any problems for months, during the day the charger charges the batteries and at night the batteries keep  everything going.

Anyways, I wanted to do a test to see what would happen if the solar panel got covered in dirt or if it rained for a week. I disattached the solar panel and let the batteries drain until the board shut off. When I measure the battery's voltage they were at 1.7 volts which I expected they would be lower than the 2.5 volt cut off because I have an external sensor attached that can draw voltage all the way down to 1.7 volts... I then reattached the solar panel and left it charging in the sun. After about six hours I was getting suspicious since I had not seen any new data up here on my graphs. I went outside and check the voltage of the batteries and they were at 3.7 volts but the SIM 7000 status LEDs were off.

The blue LED was on and solid. my sketch shuts the blue LED off after boot to save some power. No other LEDs were on except the blue one. I press the power button and nothing happened I was only able to get it to recover by pressing the reboot button.

I **need** these boards to be able to recover after batteries died and are recharged. Is this a known issue? could it be caused because I am using an external battery pack connected to the vbat pin and gnd instead of the positive / negative terminal of the battery connector that is on the back of the board? Does the board have any kind of circuitry that is supposed to have it recover such incidents? Or can it be added?

lewisxhe, 2020-07-06:
I think it should enter the download mode unexpectedly. I suspect that the download circuit affects it. If you can, please remove them and try again. The previous version also reported this problem.

Mr-HaleYa, 2020-07-06:
Do what?

Mr-HaleYa, 2020-07-06:
I _need_ to be able to do updates on these, They will be installed in remote locations and I will be doing GSM OTA updates, since that is software (I assume) modifying the hardware won't affect that?

lewisxhe, 2020-07-08:
Hi , @Mr-HaleYa
I personally think it may accidentally enter the download mode, so you must manually reset it. If you can, I ask you to remove the download circuit. Of course, this is just my guess.

Mr-HaleYa, 2020-07-08:
I put a dead battery in a different board with the exact same configuration and this time when it started charging with solar it recovered... I have some batteries on a test station so that they drain till they're dead so I can do a couple more of these test runs but it appears that it's a 50-50 chance now.

Also can you take a picture of the board and circle what I'm supposed to remove or cut or modify because I don't really want to start playing doctor with it when I don't know what I'm messing with

lewisxhe, 2020-07-08:
Although I can’t be 100% sure, I will give you the original part of the screenshot download part tomorrow, if you can, you can remove it and try again, but it cannot be automatically downloaded after removal.

lewisxhe, 2020-07-09:
Hi @Mr-HaleYa
If you can, please remove the components marked in the figure below, I think it has a lot to do with it. Note that it cannot be automatically downloaded after removal. You can short IO0, then reset, and then click download.

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

Mr-HaleYa, 2020-07-09:
Can this be fix in the future? I really like the idea of adding a switch to "allow" programming or not so that this issue never happens if the switch is off (disconnects this circuit)

lewisxhe, 2020-07-09:
It is temporarily unclear that it is caused by it, this only happens in some cases, you can try it first, and then feedback to us

Mr-HaleYa, 2020-07-11:
I have tried with another dead battery and it recovered fine... I don't want to destroy one of my boards for no reason lol. Can the engineers test it since they should be looking to fix such problems?

I think you might be able to connect to a power supply and slowly turn up the voltage to mimic solar charging.

Mr-HaleYa, 2020-07-15:
What appears to happen is that the board is trying to power bellow a capacity (not voltage but capacity) that can not be sustained... the solar charger puts out the required voltage amount to charge the batteries, and the board sees this voltage and tries to turn on, then idk what happens but I assume the mppt cant supply the right amount (it's rated to charge output at 3 amps so should be plenty...) or it shuts off or something because the board appears to shut off then repeats... it looks to be strobing extremely quickly, but that is only with a dead battery... after the battery charges this should stop, but it doesn't. the led that I have programmed to turn off after successful boot (onboard led blue) never shuts off and the board never recovers until RST pressed

nissimzur, 2020-07-17:
Slow voltage power up may not generate a reset. Many MCU has this problem.
I offer to stay in light sleep, no GSM, test voltage and send esp_restart(); when voltage is high to normal boot the GSM chip.
Another option to use a MOSFET that will block the power to PCB below 3.7V. So, PCB will get powers only when the battery if full to work. GSM pulls a lot of power in powerup.

Mr-HaleYa, 2020-07-17:
So have it boot and check the voltage and run a low power function that uses nothing then once the voltage is high have it reboot and run normally?

Mr-HaleYa, 2020-07-18:
> Another option to use a MOSFET that will block the power to PCB below 3.7V. So, PCB will get powers only when the battery if full to work. GSM pulls a lot of power in powerup.

@nissimzur
What kind of circuit would this look like?

Mr-HaleYa, 2020-07-18:
@lewisxhe
shouldn't this not be happening because there is a 2.4v voltage cutoff for battery discharge protection. when I plug in a 3.2-volt battery it doesn't turn on but if start charging it starts trying to turn on... shouldn't the voltage cutoff stop this until a voltage is met?

Could it be spikes of voltage from the solar charger making it think it's high enough so it tries to boot? Would adding a large smoothing cap help?

would adding a MOSFET even help? would it be "tricked" by charging spikes?

when I connect battery to charger and meter to battery I don't see any spikes but they would be happening really fast because the blue light flickers until ~2.6v the goes solid (board turning on and locking)

Mr-HaleYa, 2020-07-19:
@lewisxhe
oh my gosh, I think I found the solution!!! https://4donline.ihs.com/images/VipMasterIC/IC/FAIR/FAIRS25678/FAIRS25678-1.pdf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

as I was saying before I would do Pin1 to Batt, pin2 to GND, and Pin3 to RST so that when the voltage is below the threshold on Pin1 then Pin3 will be held LOW making the board be held in RST so it will not boot then once the voltage is above the threshold Pin3 will be held HIGH allowing the board to boot normally!!!

I think the KA75250 or KA75270 would be PERFECT since they are 2.5v or 2.7v thresholds.

They make these as tiny ICs (SOT-89) so this could easily be added to the board in the next revision so that they never have this horrible problem again! have one between the VBAT, GND, and RST so it stays off till VBAT is above the threshold value you choose. The IC comes on at 0.8V so it will be the first thing on, before the MCU.

Please let me know your thoughts!

Mr-HaleYa, 2020-07-19:
Those components are hard for me to find in the USA ao maybe this will work better. It is smaller and lower power with a threshold of 2.7v. NCP301HSN27T1G https://www.onsemi.com/pub/Collateral/NCP300-D.PDF

Mr-HaleYa, 2020-07-20:
The only thing that I see that could be a problem is that the SIM7000G still activates when the RST is LOW and the Arduino is off so I don't know if it can get stuck in a locked state like the MCU.

lewisxhe, 2020-07-29:
When RST is at low level, it can only make ESP32 unfair, if the voltage can make SIM7000G start, then SIM7000G will still work normally, if the battery is not enough, then SIM7000G will automatically shut down

Mr-HaleYa, 2020-07-29:
@lewisxhe  did you show the engineer what I found? I think adding that part would eliminate the MCU startup error.

Mr-HaleYa, 2020-08-15:
If you use the battery pad on the back it will not run into this problem, but if you use the Vbat pin to power the board you can have the MCU brick. The Vbat pin needs to be rebuilt to be the same as the pad on the back of the PCB, otherwise its literally useless because it has no protection features and can brick the MCU on low power boot.

Closing this since it will require a new revision of the board to correctly fix

Closed 2020-08-15.

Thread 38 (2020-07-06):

Modem of module not responding on AT commands

cuplesoft, 2020-07-06:
Hello,
I bought this module for tests and at the beginning everything was fine : network connection, gps data etc.

After two days of tests I lost connection with modem. I can't get any response on AT commands.
It may be possible that firmware was broken or SIM7000G died..?
Can I upload default firmware for this device and bring my module back to life?

Mr-HaleYa, 2020-07-06:
@cuplesoft
You probably just messed up the 7000g. this can happen if you are messing with AT commands.

this is on the TinyGSM page

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

___

You need to modify it to look like this

```
// Select your modem:
#define TINY_GSM_MODEM_SIM800

#define MODEM_RST     5
#define MODEM_PWKEY   4
#define MODEM_DTR     25
#define MODEM_TX      26
#define MODEM_RX      27

#include <TinyGsmClient.h>

// Set serial for debug console (to the Serial Monitor, speed 9600)
#define SerialMon Serial

// Set serial for AT commands (to the module)
#define SerialAT Serial1

#include <StreamDebugger.h>
StreamDebugger debugger(SerialAT, SerialMon);
TinyGsm modem(debugger);

void setup() {
  // Set console baud rate
  SerialMon.begin(9600);
  delay(10);

  // Set GSM module baud rate
  pinMode(MODEM_PWKEY, OUTPUT);
  digitalWrite(MODEM_PWKEY, HIGH);
  delay(10);
  digitalWrite(MODEM_PWKEY, LOW);
  delay(1010); //Ton 1sec
  digitalWrite(MODEM_PWKEY, HIGH);
  delay(4510); //Ton uart 4.5sec but seems to need ~7sec after hard (button) reset, On soft-reset serial replies immediately.

  // Set and start the GSM module at baud rate
  SerialAT.begin(9600, SERIAL_8N1, MODEM_TX, MODEM_RX); //reversing them
  delay(6000);

  bool ret = modem.factoryDefault();

  SerialMon.println(F("***********************************************************"));
  SerialMon.print  (F(" Return settings to Factory Defaults: "));
  SerialMon.println((ret) ? "OK" : "FAIL");
  SerialMon.println(F("***********************************************************"));
}

void loop() {

}
```

I have it set to sim800 because the commands are __very__ similar (and they dot have sim7000 set up yet so it won't work 🙃 )

your output in serial should be

```
AT+IPR=0
AT+IFC=0,0
AT+ICF=3,3
AT+CSCLK=0
AT&W
AT&W

OK
***********************************************************
 Return settings to Factory Defaults: OK
***********************************************************

```

I have ran this sketch on the 20200415 version of the board and it completes successfully. If this does not fix your problem let me know, also tell me the board version (20191227 or 20200415)

best of luck
~Hale

cuplesoft, 2020-07-06:
Thanks for nice solution but it doesn't work on my device :(

Return settings to Factory Defaults: FAIL

It's look like modem starting normally : STATUS led is on, NETLIGHT led starts blinking once per second and several seconds after blinks once per 3 seconds. This is correct behavior?

But output from modem doesn't exists - requests only:

[W][sd_diskio.cpp:471] ff_sd_initialize(): GO_IDLE_STATE failed
[E][sd_diskio.cpp:739] sdcard_mount(): f_mount failed 0x(3)
SDCard MOUNT FAIL
[2068] Wait...
[5069] Initializing modem...
AT+CFUN=0
怘⸮ f`⸮f
⸮⸮[15070] ### Unhandled:  f`f

[15070] Failed to restart modem, delaying 10s and retrying
AT+GMM
[16070] Modem Name: SIMCom SIM7000
ATI
[17070] Modem Info:
AT+CPIN?
AT+CPIN?
AT+CPIN?
AT+CPIN?
AT+CPIN?
AT+CNMP=51
AT+CMNB=2
[30072] Waiting for network...
AT+CEREG?
AT+CGREG?
AT+CEREG?
...
AT+CGREG?
AT+CEREG?
AT+CGREG?
[100850] Waiting for network...
AT+CEREG?
AT+CGREG?
AT+CEREG?
AT+CGREG?
AT+CEREG?
...

Mr-HaleYa, 2020-07-07:
I ran the script that I shared on 5 of my boards and it finished with `Return settings to Factory Defaults: OK` on all of them. If you can not get it to run then nothing will...

Mr-HaleYa, 2020-07-07:
have you used battery power or just USB? if you put the battery in backward it can cause "undesired behavior" and also will kill the charging circut...

cuplesoft, 2020-07-08:
I used many configurations - tests ;)
Generally I connected my module to my Laptop. Of course it many times with battery NCR18650B or with battery only.
Charging circuit you said... Hmm, this may be possible because at the center of module green led is on, BUT near of green is red led and blinking very fast (5-10 blinks per second) This is not too good i think..

lewisxhe, 2020-07-08:
Have you tested whether the AT has responded using serial port loopback?  Also, on the board, there seems to be two LED lights near SIM7000. Is it normally on?

Mr-HaleYa, 2020-07-08:
that is normal for the green light to be solid in the red light to be blinking extremely quickly. that means it is working correctly with USB. When connected using the battery pack on the back those lights function as charge indicators for solar panels. But when using USB they don't have actual functionality they just blink as energy pulses through the charge circuit

lewisxhe, 2020-07-09:
The green light is the full indicator
The red light is the charging indicator,
When it is not connected to the battery, the status is undefined.

You can try to connect the battery and observe whether the indicator light is normal.

The indicator lights I mentioned are two red lights next to the SIM7000G. One silk screen is NETLIGHT, STATUS. Please check if STATUS is on.

Mr-HaleYa, 2020-07-09:
@cuplesoft

These LEDs at the bottom
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

cuplesoft, 2020-07-09:
Finally! My device is working now :-)

I did it by running this code:

[https://github.com/Xinyuan-LilyGO/LilyGO-T-SIM7000G/tree/master/examples/Arduino_TinyGSM/ResetModem](https://github.com/Xinyuan-LilyGO/LilyGO-T-SIM7000G/tree/master/examples/Arduino_TinyGSM/ResetModem)

In my case BOUND must be 9600 and after upload I need to reset module manually.
Not every time this procedure works because sometimes result was "Reset settings to Factory Default: FAIL".
I reset manually by button again and now works!

Thanks for help for everyone.

lewisxhe, 2020-07-09:
It may be that you set the baud rate, if it is not the default, then it is changed, and then you send any command will not return.

philo-create, 2020-07-20:
Hello.i have  the same  problem  with  my  board.

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

I have  used the  recommended  code to reset the modem and got the  following  output but my  modem still doesn't work,what else do you recommend  i should do
`***********************************************************
 Return settings to Factory Defaults: OK
***********************************************************`

philo-create, 2020-07-20:
Hello.i have the same problem with my board.

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

I have used the recommended code to reset the modem and got the following output below but my modem still doesn't work,what else do you recommend i should do?

`***********************************************************
 Return settings to Factory Defaults: OK
***********************************************************`

Mr-HaleYa, 2020-07-20:
what did you do, to begin with???

philo-create, 2020-07-20:
the board has been working fine. I have  been using  it to read  humidity and  temperature  data for a month now  but  then it suddenly stopped connecting  to the network,just woke-up one-day and  the  board wasn't  working  properly anymore.

Mr-HaleYa, 2020-07-20:
what connection typer were you using(2-3-4G catm nb) and what sim card? and where are you located

philo-create, 2020-07-21:
The board had been working for a month  over the 4g connection before it suddenly stopped working ,i have another similar board that i got the same time that is still working,  therefore the problem has nothing to do with the sim card  (I tested the sim card to make-sure) or location (South Africa).

Mr-HaleYa, 2020-07-21:
when you run the reset example do you have ATdebug enabled. if so can you share the serial output

philo-create, 2020-07-21:
So just run  the  reset  example and i am  getting  a  different  output,before  my  output was  successful but  today its a  fail

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

philo-create, 2020-07-21:
forgot to  mention  that i am  using  the 20191227 Version ,i know  that this  board  doesn't have  the   reverse battery protection and  that  can  affect the modem,so  i made  sure  that the  problem wasn't t battery related before  i posted my  problem  here

Mr-HaleYa, 2020-07-21:
sometimes it fails sometimes it passes its dependent on the modems mood... press the rest on the board until you get a pass and send me a pic of that if you can

pixelfriese, 2021-07-31:
Hi. I have the same problem with my board too.

When I run the reset program, I get the following output. The baud rate is set correctly. I can't send AT commands to the board from the console. Only when I insert the AT command in the program code will they run. My guess is that I won't get any feedback on the if (SerialAT.available) query if the modem is already running.:

```
14:25:32.941 ->
14:25:32.941 -> Starting Up Modem...
14:25:32.941 ->
14:25:32.975 -> Testing Modem Response...
14:25:32.975 ->
14:25:32.975 -> ****
14:25:34.437 -> u⸮
14:25:36.443 -> AT

14:25:36.477 -> OK
14:25:36.477 ->
14:25:36.477 -> ****
14:25:36.477 ->
14:25:36.477 -> AT&FZE0&W
14:25:36.545 -> AT&FZE0&W

14:25:36.613 -> Autobaud support: (9600,19200,38400,57600,115200).
14:25:36.613 ->
14:25:36.613 -> OK
14:25:36.613 -> AT+IPR=0
14:25:37.567 -> AT+IFC=0,0
14:25:38.587 -> AT+ICF=3,3
14:25:39.573 -> AT+CSCLK=0
14:25:40.593 -> AT&W
14:25:41.751 ->
14:25:41.751 -> ***********************************************************
14:25:41.751 ->  Reset settings to Factory Default: FAIL
14:25:41.751 -> ***********************************************************

```

But if I press the reset button on the board again and the modem is already active, I get the following output:

```
14:32:37.269 -> Starting Up Modem...
14:32:47.517 ->
14:32:47.555 -> Testing Modem Response...
14:32:47.555 ->
14:32:47.555 -> ****
14:32:57.745 -> ****
14:32:57.745 ->
14:32:57.745 -> ***********************************************************
14:32:57.745 ->  Failed to connect to the modem! Check the baud and try again.
14:32:57.745 -> ***********************************************************
14:32:57.745 ->
```

cuplesoft, 2021-11-29:
I'm here again...
Why blue led light is always on when usb is connected?

nkkn87, 2023-04-20:
Hi, I understand that this post was long time ago. But now I am using SIM7000E and use to send data to server with http get. SIM could stop working (power light is on but newtwork status light totally off), So I cannot run continuously. When this happens, I cannot send any commands, even AT command. I have to power cycle the SIM module and it starts working again.
Anybody encountered this and any idea how to fix this?

ceren16, 2023-08-09:
> sometimes it fails sometimes it passes its dependent on the modems mood... press the rest on the board until you get a pass and send me a pic of that if you can

Hello my board is not still working , how can I solve it?

Closed 2020-07-09.

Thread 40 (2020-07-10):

Questions about board (20200415)

Mr-HaleYa, 2020-07-10:
So I hooked a battery to the vbat pin and gnd backwards and this component exploded....

What is it? Why did it? isn't there supposed to be backwards battery protection or is that only if you use the socket on the back?

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

lewisxhe, 2020-07-10:
Sorry, I will report the situation to the hardware engineer, and I will ask them what to do.

slavino, 2020-07-10:
> Sorry, I will report the situation to the hardware engineer, and I will ask them what to do.

maybe bigger "BAT +" and "BAT -" signs on the board in next HW version :D

Mr-HaleYa, 2020-07-10:
It was an external battery pack, but yes they could put bigger symbols on the back

lewisxhe, 2020-07-11:
Did you use the rear 18650 battery holder to access the battery before? Is it normal ?

Mr-HaleYa, 2020-07-11:
What? Is it normal for things to explode? No it is not normal... yes I use the rear battery pack and it worked just fine but then I desoldered the rear pack and soldered a larger one to vbat and gnd and accidentally put one battery in backwards and the part exploded. I did the exact same thing to five other boards and as long as you don't put the battery in backwards they don't explode.

lewisxhe, 2020-07-11:
No, you misunderstood, I mean, have you used the battery holder provided on the back of the board for charging before?  Is it normal?  Or is it your first time using the charging function?

Mr-HaleYa, 2020-07-11:
I said yes I used it, then I removed it.

Mr-HaleYa, 2020-07-16:
@lewisxhe
any other questions? did your engineer reply?

What part is it and where is it on the schematic and I will replace it.

lewisxhe, 2020-07-16:
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

This is a boost IC, you can replace it if you can

nissimzur, 2020-07-17:
This chip boost Vbat 3.6 to 4.2 needed by GSM.
If you remove U11, you can hook to C32 the plus side to external 4.2 V
if you use USB 5V. you can put a diode in series
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
 with 5V and get easy 4.2 V.

Mr-HaleYa, 2020-07-17:
@nissimzur
are you the engineer/developer?

nissimzur, 2020-07-17:
I am.
look for Dr. Nissim Zur at youtube

Mr-HaleYa, 2020-07-17:
I was if you are the person who built the TTGO SIM7000G?

lewisxhe, 2020-07-20:
This is a stupid approach, and the Modem may not be turned on when using battery power. He is not an engineer of LilyGo.

lewisxhe, 2020-07-20:
The method of connecting the diode in series does not consider the use of battery power supply. When the battery is used, the Modem may not be opened smoothly

lewisxhe, 2020-07-20:
The engineer just told me to use the negative battery on the back of the board instead of GND, which has battery over-discharge, overload, and short-circuit protection.

Mr-HaleYa, 2020-07-20:
That's not an option, its mounted on a PCB
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

Mr-HaleYa, 2020-07-20:
@lewisxhe
Ok, I rebuilt my PCB to have spring contacts to connect to the Battery pins on the back of the TTGO when it is mounted on a PCB. This should add the following benefits
- Backward battery protection
- overcharge Protection
- Over-Discharge protection
- overcurrent protection
- on/off switch

I think I will still add an STM1061N27WX6F To monitor the battery and force the MCU off (RST LOW) until the voltage is greater than 2.7v so it does not give the bootloader problem

Closed 2020-07-29.

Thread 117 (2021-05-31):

Unable to flash device

Ollebolle, 2021-05-31:
Hi! I just got this board and it looks awesome, but I'm not able to flash it at all. I've tried the platformio example as well as simply going through the Arduino IDE but no matter what I do I get this error message:

```
Chip is ESP32D0WDQ5 (revision 1)
Features: WiFi, BT, Dual Core, 240MHz, VRef calibration in efuse, Coding Scheme None
MAC: ****
Uploading stub...

A fatal error occurred: Failed to write to target RAM (result was 01070000)
*** [upload] Error 2
```

I've also tried 3 different usb-c cables with no difference. I've also set a bridge in between pin0 to ground and thereafter reset the board, which gives me:
```
rst:0x1 (POWERON_RESET),boot:0x3 (DOWNLOAD_BOOT(UART0/UART1/SDIO_REI_REO_V2))
waiting for download
```

But still not able to flash. Can anyone please help? 🤔

francoisfanuel, 2021-06-02:
I have the same problem using Big Sur. I switched to platformio remote on a raspi 4 to workaround it until I figure it out.

Mr-HaleYa, 2021-06-15:
yup mac sucks for Arduino development. Use a Windows PC, downgrade the OS, or find another hobby... not much you can do until they fix the bug

Ollebolle, 2021-06-16:
> yup mac sucks for Arduino development. Use a Windows PC, downgrade the OS, or find another hobby... not much you can do until they fix the bug

Yeh I eventually gave up trying to get it to work on Mac and moved over to my Windows machine where it worked right away. 🤷‍♂️

Closed 2021-06-16.

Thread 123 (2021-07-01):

System reboots after power is removed before battery kicks in.

TravisDuck999, 2021-07-01:
I'm sure this has been touched on somewhere else but I can not seem to find it.

My setup is as follows :

Solar with V going to the Vin pin.
18650 clipped into the rear battery pack and fully charged.

When I have a power failure the 5V turns off and the small solar panel takes over and charges things with the battery helping if needed.

My problem is when the main 5V power goes off  the system reboots completly and then starts running on the battery.

Has anyone gotten the system to work without having this reboot happen ?

I have constant power dips here and this is not ideal to have the system reboot every time it goes off and back on.

TravisDuck999, 2021-07-06:
Figured it out.

If anyone else is having this problem I fixed it by adding a cap between the 3.3V and GND pins.

This give the ESP32 that little bit of power needed to keep going before the battery system kicks in properly ( after the power has cut out ).

I started with a 1000uF cap but went down to a 100uF and it still works, not sure how much lower you can go.
I wanted to use a Super-Cap to do this but realise now that it is crazy overkill and might damage something on the power rail when it charges for the first time.

Your Cap size will change depending on your 3.3V draw and other things attached to your 3.3V power line of course, this test was done with extremely basic setup and little peripherals

Closed 2021-07-06.

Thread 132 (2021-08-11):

Debugging - OpenOCD cannot access the board - jtag_trst == 0 assertion failed

eisenach, 2021-08-11:
Hello,
I'm trying to debug my firmware on TTGO-T-SIM7000G through OpenOCD and, regardless of the driver I'm using, and consistently on Windows and Linux, I have the following result
```
Reading symbols from D:\projects\sss\sss-lock-firmware\.pio\build\esp-wrover-kit\firmware.elf...
done.
PlatformIO Unified Debugger -> http://bit.ly/pio-debug
PlatformIO: debug_tool = ftdi
PlatformIO: Initializing remote target...
Open On-Chip Debugger  v0.10.0-esp32-20210721 (2021-07-21-13:35)
Licensed under GNU GPL v2
For bug reports, read
	http://openocd.org/doc/doxygen/bugs.html
adapter speed: 20000 kHz
WARNING: boards/esp32-wrover.cfg is deprecated, and may be removed in a future release.
         If your board is ESP32-WROVER-KIT, use board/esp32-wrover-kit-1.8v.cfg instead.
adapter speed: 5000 kHz

Info : tcl server disabled
Info : telnet server disabled
Error: no device found
Error: unable to open ftdi device with vid 0403, pid 6010, description '*', serial '*' at bus location '*'
Error: no device found
Error: unable to open ftdi device with vid 0403, pid 6014, description '*', serial '*' at bus location '*'

Assertion failed!

Program: D:\tools\pio\.platformio\packages\tool-openocd-esp32\bin\openocd.exe
File: ../src/jtag/core.c, Line 343

Expression: jtag_trst == 0
.pioinit:11: Error in sourced command file:
Remote communication error.  Target disconnected.: Success.
```

I also tried to run OpenOCD directly (not through PlatformIO), without luck.
Could you please advise?

Thank you,
Dom

tolgraven, 2021-12-28:
@LilyGO having the same issue. The default FTDI config clearly isn't the right one, but which one is? Which interface config do we use?

wwestrup, 2023-06-23:
Try adding the following to your platformio.ini file for your project. Make sure to modify the port and debug tool names as needed:

upload_port = /dev/ttyACM0
debug_tool = esp-prog
debug_init_break = tbreak setup
debug_port = /dev/ttyUSB1
build_type = debug
debug_speed = 5000

This will at least get you as far as I've gotten. (but it still doesn't work, at least not for me, yet.)

MateusLourenco97, 2023-07-16:
I got it working using the configurations @wwestrup  mentioned. What could probably going wrong with your peoject is that you're using the LED pin (GPIO 12) on your application code. To get it working you have to give up using the SD slot and the built in LED pins.

shanedoolane, 2023-10-02:
For anyone coming to see this. @MateusLourenco97 appears to have found the solution. If you remove LED control from your code on GPIO12 (the blue LED on our board) and start debugger, it works.

Otherwise, if you attempt to use the LED and debugger at the same time, it will fail to initialize.

For ESP-prog, use common GND, 3v3, GPIO12-15.

```
[env:esp32dev]
platform = espressif32
board = esp-wrover-kit
framework = arduino
debug_tool = esp-prog
debug_init_break = tbreak setup
```

shanedoolane, 2023-10-02:
@LilyGO or @lewisxhe do you know the reason GPIO12 was chosen for LED and JTAG interface? do you know how to make both work together?

shanedoolane, 2023-10-09:
I'm also seeing that I can't use JTAG/prog interface during deep sleep. The USB is able to wake out of deep sleep and successfully boot but JTAG fails.

shanedoolane, 2023-10-09:
Found a solution to wake from deep sleep when getting this error.
```cpp
#include "driver/rtc_io.h"

rtc_gpio_pullup_en(GPIO_NUM_12);
rtc_gpio_pulldown_dis(GPIO_NUM_12);
esp_sleep_enable_ext0_wakeup(GPIO_NUM_12, 0);
```

This causes GPIO to be pulled high in the application setup. The last line sets a wake-up from deep sleep interrupt on GPIO 12. Whenever GPIO12 is pulled low and in deep sleep, the ESP will wake up. Probing, we see that GPIO 12 is pulled high while app is running and in deep sleep. When we pull it down (i.e. when using JTAG, the ESP is woken from deep sleep).

Here's the logic analyzer trace of the JTAG initial handshake. You can see GPIO12 is pulled high before JTAG starts and as soon as it goes low, the ESP comes out of deep sleep.

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

I also tested with the reverse code (i.e. normally low with a pull-up wakeup trigger) but it did not work. Because esp-prog hold GPIO 12 high, the interupt is triggered as soon as the ESP sleeps so it continuously boots. Don't do it this way.
```cpp
#include "driver/rtc_io.h"

rtc_gpio_pullup_dis(GPIO_NUM_12);
rtc_gpio_pulldown_en(GPIO_NUM_12);
esp_sleep_enable_ext0_wakeup(GPIO_NUM_12, 1);
```

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

Closed 2021-10-19.

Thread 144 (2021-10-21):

Modem turns on & off periodically in short time intervals

jonrot1906, 2021-10-21:
Hey folks,
I currently can't get my LilyGo-T-SIM7070G module to work properly. When trying the NetworkTest sketch in the example folder the modem does connect over NB-Iot but will turn off completely after a few seconds (status and network led will turn off and won't respond to AT commands). This process repeats infinitely. I tried to do a factory reset, but this always fails on this device.

With Mongoose OS and the PPPos library I couldn't get the device to work permanently at all.

Device is connected per USB to my laptop, no battery inserted, no solar panel attached. Network Carrier is 1NCE, NB-Iot is possible.

Any help is appreciated!

LilyGO, 2021-10-23:
+CGREG:0,5 indicates to register with roaming network.
It has to do with your SIM card. The serial port is connected to the network. Everything looks fine.

jonrot1906, 2022-01-04:
Sorry that I left this topic uncommented for so long. My personal workaround was to do the following:
Turn on:
```pinMode(PWR_PIN, OUTPUT);
digitalWrite(PWR_PIN, LOW);
delay(1200);
digitalWrite(PWR_PIN, HIGH);
delay(300);
digitalWrite(PWR_PIN, LOW);
delay(10000);
```

Turn off:
```digitalWrite(PWR_PIN, HIGH);
delay(1500);
digitalWrite(PWR_PIN, LOW);
```

This does work on all my SIM7070G equipped devices (ESP32 + SIM7070G and also my [Waveshare SIM7070G Raspberry Pi Hat](https://www.waveshare.com/sim7070g-cat-m-nb-iot-gprs-hat.htm)). With "normal" turn on as provided in your examples, the modem will keep rebooting every 14 seconds or so.

szundi, 2022-03-16:
Hello, just FYI: according to the docs, if you keep the PWRKEY pin DOWN for 12.6sec, it resets.

rhr407, 2022-04-18:
I receive no response for HTTP Get request for the `http://httpbin.org/get` URL. Following is the output using the AT Command Tester from `https://m2msupport.net`

```

Checking registration status...

AT+CREG?

+CREG: 2,1,"912","3D73",0

OK
The device is registered in home network.

AT+CGREG?

+CGREG: 2,1,"912","3D73",0,"1"

OK
The device is registered in home network.

Device is registered..

Check the network APN...

AT+CGNAPN

+CGNAPN: 0,""

OK
Network did not send APN to the device.
Activate the network bearer...

AT+CNACT=0,1

OK

+APP PDP: 0,ACTIVE
Set up the HTTP URL...

AT+SHCONF="URL","httpbin.org"

OK
Set up the HTTP body length...

AT+SHCONF="BODYLEN",1024

OK
Set up the HTTP header length...

AT+SHCONF="HEADERLEN",350

OK
Initiating HTTP connection...

AT+SHCONN

OK
Get the HTTP connection state...

AT+SHSTATE?

+SHSTATE: 1

OK
HTTP connection is successful...

HTTP get request...

AT+SHREQ="http://httpbin.org/get",1

OK
No reponse received..

```

Gabriel-Gardin, 2022-09-25:
Hello, I was having the same problem, SIM7070 board was reseting in short periods of time, when I chagned my code to turn on the board using:
`pinMode(PWR_PIN, OUTPUT);
digitalWrite(PWR_PIN, HIGH);
delay(300);
digitalWrite(PWR_PIN, LOW);`

then it start working.

Apparently SIM7000G and SIM7070G have different power on GPIO requirements.

deeja, 2023-07-19:
Have been looking at this myself.
As @Gabriel-Gardin  said, changing the PWR_PIN to LOW stops this.
The reason is that setting to HIGH sets the inverted value of PWR_KEY on the SIM7070 module to LOW.
When held LOW for 12 seconds, the module resets.
From the 7070 hardware design manual:
> After the PWRKEY continues to pull down more than 12S, the system will automatically reset. Therefore, long-term grounding is not recommended

This is different from the SIM7000 which has a reset pin

Nadeem-Ullah, 2024-07-30:
Hey folks,!
I am using SIMCom SIM7070G module  ,for Cellular communication, connected to Raspberry Pi through Mini-PCIe USB connector. I created connection interface PPP0 using _mmcli_ and _nmcli_ commands through Network and Modem Manager.
When I ping google for testing, the GSM module hangs-up after ~50 minutes and can't capture the SIM-card while SIM index shows-up, ping do not work after that.
ERROR:(output of the "mmcli -m %modem-index -K" command running in my C programming for pinging at the instant of failure):

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

What may be the problem?

Your feedback is appreciated!

Nadeem-Ullah, 2024-07-30:
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

Did you solved your problem?

rhr407, 2024-07-30:
To the best of my knowledge SIM7070 and Sim7000 do not work with RPi on qmi
interface.

On Tue, 30 Jul 2024 at 13:41, Engr. Nadeem Ullah ***@***.***>
wrote:

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

rhr407, 2024-07-30:
No

On Tue, 30 Jul 2024 at 13:43, Engr. Nadeem Ullah ***@***.***>
wrote:

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

jonrot1906, 2024-07-30:
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

QMI didn't work for me as well, I use PPP with all the SIM7000/SIM7070 devices connected to my RPis. For convenience I modified some Sixfab code and created a [repo](https://github.com/BUSSE-IS/rpi-sim70X0). Have a look if you want. Works perfectly fine for me.

rhr407, 2024-07-30:
Thanks, I will have a look.

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

Nadeem-Ullah, 2024-07-30:
I didn’t used @qmi interface, I have used Modem Manager and Network Manager and it created ppp0 interface, as _ifconfig_ shows…

Nadeem-Ullah, 2024-07-31:
> I didn’t used @qmi interface, I have used Modem Manager and Network Manager and it created ppp0 interface, as _ifconfig_ shows…

Ohhh! sorry:

> In addition, install the libqmi-utils and udhcpc packages.
>
> sudo apt install libqmi-utils udhcpc

I have used qmi indeed.

I will try the PPP0 new method.

But how _libqmi-utils_ produces _ppp0_ interface, as I have created it...?

Nadeem-Ullah, 2024-07-31:
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

Hi: @jonrot1906
In your repo you haven't provided the "README" file that explains how to install and use the library.
Help, please.

jonrot1906, 2024-07-31:
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

Hi @Nadeem-Ullah,
I added some info to the repo, hope that helps. You should be fine simply running the "install.sh" script.

And well, ModemManager/mmcli uses qmi ports/protocol to my knowledge. For the SIM7600 module QMI is the way to go for me as it is faster, but for SIM7000/SIM7070 I found PPP to work far more reliable.

Nadeem-Ullah, 2024-07-31:
I am not using SIM7070G HAT for RPi but my own development board with CM4 inserted in it.Then I inserted SIM7070G through Mini-PCIe.

Is there any specific PIN configuration to be changed in your scripts (According to my development board) or its all okay?

Nadeem-Ullah, 2024-07-31:
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

I am not using SIM7070G HAT for RPi but my own development board with CM4 inserted in it.Then I inserted SIM7070G through Mini-PCIe.

Is there any specific PIN configuration to be changed in your scripts (According to my development board) or its all okay?

jonrot1906, 2024-07-31:
@Nadeem-Ullah Well, you need to specify then which board you are using. I used [this](https://www.waveshare.com/wiki/Compute_Module_4_PoE_4G_Board) Compute Module 4 PoE 4G Waveshare board with a SIM7600 module and got it to connect to the network by using a PPP connection over a ttyUSB port. This was quite similar to the "standard procedure" of connecting a Waveshare board like [this](https://www.waveshare.com/wiki/SIM7070G_Cat-M/NB-IoT/GPRS_HAT) to a RPi 3/4 via USB. In the end it's basically the same: the script will send some AT commands over a serial connection to the board. If it's over Mini-PCIe or USB wouldn't matter I guess.

Nadeem-Ullah, 2024-07-31:
I am using CM4 like [this](https://www.raspberrypi.com/products/compute-module-4/) in my own development board, having same PINS as Raspberry Pi 4 B. And connected SIM7070G board through Mini-PCIe with this CM4 using my development board extension.
It is detecting ttyUSB ports as well. And Serial Port (ttyAMA0) also works fine for sending AT commands. May be its a M.2 connection you mentioned above.
But for module power control, I am using GPIO23 of the Raspberry Pi and giving a Power Supply at Vbat PIN to the module. So, should I use PIN-23 instead of PIN-6 to be set to high for board to turn on?

jonrot1906, 2024-08-01:
@Nadeem-Ullah As I really don't know how your development board extension is wired up, it's hard to tell. You could either share some more information or just try it out. :-)

Nadeem-Ullah, 2024-08-01:
> @Nadeem-Ullah As I really don't know how your development board extension is wired up, it's hard to tell. You could either share some more information or just try it out. :-)

I am using SIM7070G in PPP mode and the '5 USB serial Modem port Interface' is 'ttyUSB5' in this mode. as shown in the picture below:
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

In which mode should I use the module?

If 'ttyUSB5' is correct for me, should I edit the file [reconnect_sim7000.sh](https://github.com/BUSSE-IS/rpi-sim70X0/blob/main/reconnect_sim7000.sh), replacing 'ttyuSB3 with 'ttyUSB5', according to my situation.

Another point is I have the 'AT+CPOWD=1' option in my module datasheet, can I use it directly instead of GPIO PIN for power off and on, as shown in file [reconnect_sim7070.sh](https://github.com/BUSSE-IS/rpi-sim70X0/blob/main/reconnect_sim7070.sh) ?

Another point is that you have used the 'wwan0' interface in your script in files [reconnect_sim7070.sh] and [reconnect_sim7000.sh], in which both have no 'wwan0' interface USB port except [SIM7500_SIM7600], as shown below, from the datasheets of these modules:

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

Should I replace 'wwan0' with 'ppp0' or its ok?

In file [reconnect.sh](https://github.com/BUSSE-IS/rpi-sim70X0/blob/main/reconnect.sh) you have used 'GPIO-7' and 'sudo /etc/init.d/rinetd restart' also, whats the purpose of these both and how I should replace these?

In the file [provider](https://github.com/BUSSE-IS/rpi-sim70X0/blob/main/provider) you have used '/dev/ttyUSB2 115200' which is understandable (AT command port) and _-T iot.1nce.net_ is also known as APN and I will replace it according to my ISP's APN.

Another question is that in the installation you have said: _Simply cd into the repo and run_, so, which _repo_ we should cd to or you talking about _**/etc**_ file directory?

help, please

Closed 2022-01-04.

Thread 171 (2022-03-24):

Troubles with Serial between ESP and SIM7000

dizider, 2022-03-24:
Hi :wave:,

I was interested in this module so I bought one and it came today. First, I was trying a basic example [ATdebug](https://github.com/Xinyuan-LilyGO/LilyGO-T-SIM7000G/blob/master/examples/Arduino_TinyGSM/ATdebug/ATdebug.ino) and unfortunately the code does not work. After that, I tried all other examples with the same result. The ESP32 can not connect to SIM7000G (respectively I am not sure if it is a connection problem but on every command, I got `0x00` as a response or nothing)

If I connect SIM7000 directly (through pins 26 and 27) to the PC everything works great. Is there anybody who solved a similar problem or do have you any idea what to do next? To be true, I am a little bit upset because I bought this module for its simplicity. I hope that I just miss something and the module is not defective.

Thanks for help

dizider, 2022-03-24:
UPDATE:
I figured out that the problem is between a chair and keyboard, obviously. After a few hours of sadness, I tried a micropython example, and voila, it works. Now I am sure that I missing something important about ESP32 Cpp serial api. Does anyone have any idea? I am confused :confused:

LilyGO, 2022-03-25:
Use [ATdebug](HTTP: / / https://github.com/Xinyuan-LilyGO/LilyGO-T-SIM7000G/blob/master/examples/Arduino_TinyGSM/ATdebug/ATdebug.ino)What does a serial port monitor print?

LilyGO, 2022-03-25:
Use [ATdebug] What does a serial port monitor print?

dizider, 2022-03-25:
Here is a dump of communication:
```
Testing Modem Response...

****
␀␀␀␀␀␀␀␀␀␀␀␀␀␀
␀␀␀␀␀␀␀␀␀␀␀␀␀
␀␀␀␀␀␀␀␀␀␀␀␀␀
␀␀␀␀␀␀␀␀␀␀␀␀␀
␀␀␀␀␀␀␀␀␀␀␀␀␀
␀␀␀␀␀␀␀␀␀␀␀␀␀
```

dizider, 2022-03-25:
Now I observed something that blew my mind! My previous thought that the problem is somewhere in UART configuration is gone. When I try to find out what's going on in the communication and I find a surprising thing -- communication "works well" when I connect the USB-UART convertor to pins 26 and 27.
```
Starting Up Modem...

aatt

OK
aatt

OK

```

LilyGO, 2022-03-26:
The serial port monitor is abnormal.  Can you take a screenshot?  Or record a video demo?

jendakol, 2022-03-26:
Hi @LilyGO, I'm @dizider's colleague ;-) He's not available right now but I'll try to answer. Unfortunately, I don't have the device so I'm unable to provide you with the screenshot. However, it wouldn't be of any help anyway, the output is just what is written above.

Maybe let me recapitulate what we have tried:
- Running C++ examples, provided in the repo, doesn't work. The modem is never connected, the output is _weird_.
- Surprisingly, when running microPython examples, everything is smooth and correct.
- When talking to the SIM module directly (with USB<->UART converter connected to pins 26/27), the SIM module works as expected.
- When the USB<->UART converted is connected to the SIM module pins, even the C++ code works. The converter doesn't have to be connected to the PC nor to Vcc or GND of the board - just the two pins.

So... do you have *any* idea what could cause this weird behavior?
- Could it be some HW issue?
- Could it be wrong Platformio setup (e.g. wrong board selected? We tried `esp-wrover-kit` and `esp32dev`)
- anything else?

We are really desperate :-) Thx.

dizider, 2022-03-27:
For you, who are solving a similar problem is here a solution: **use a newer version of Arduino ESP32** framework. If are you using Platformio, here is an example of `platformio.ini` file or you can check our project ([GPS tracker](https://github.com/litvinov-tabor2022/lightweight-gps-tracker)) where we are using this module :slightly_smiling_face:

```
[env:esp32dev]
platform = https://github.com/Jason2866/platform-espressif32.git
board = esp32dev
framework = arduino
platform_packages =
    framework-arduinoespressif32 @ https://github.com/espressif/arduino-esp32#master
```

Closed 2022-03-27.

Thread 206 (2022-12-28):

Unable to get SDCard working. Bad Board?

tweathers-sec, 2022-12-28:
Unable able to get the SDCard working. Bad board?

Using many variants of the sample code provided, I continue to get the following error. Yes, the SDCard is formatted to FAT.

`
[  1821][E][sd_diskio.cpp:802] sdcard_mount(): f_mount failed: (13) There is no valid FAT volume
SDCard MOUNT FAIL
`

Relevant Code Used - Snipped for brevity.

```
#include <SD.h>
#include <SPI.h>
#include <LittleFS.h>

#define SD_MISO 2
#define SD_MOSI 15
#define SD_SCLK 14
#define SD_CS 13

void setup()
{
    SPI.begin(SD_SCLK, SD_MISO, SD_MOSI, SD_CS);
    if (!SD.begin(SD_CS)) {
        Serial.println("SDCard MOUNT FAIL");
    } else {
        uint32_t cardSize = SD.cardSize() / (1024 * 1024);
        String str = "SDCard Size: " + String(cardSize) + "MB";
        Serial.println(str);
    }
}
```

Tig3rch3n, 2022-12-28:
Have you tried a different brand of SD Cards?
I had some Trouble with 'NoName' SDCards

They work under Windows/Linux/Android no Problem.
But for some reason they don't support "SPI Mode" so they are useless for any Arduino Projects.
Seytonic did a Video about the Topic a few days ago https://youtu.be/wNfpRwQgDG4

tweathers-sec, 2022-12-29:
Thanks for the recommendation, but I don't use off label cards for that specific reason. I have tested a number of different SanDisk and Kingston cards that work fine with my other ESP32's. For whatever, this board just doesn't like them.

Tig3rch3n, 2022-12-30:
Could you post the full Code?
I can test in Tonight/Tomorrow :)

tweathers-sec, 2022-12-30:
Sure thing... So far, I have just been using the Examples provided in this repo.

https://github.com/Xinyuan-LilyGO/LilyGO-T-SIM7000G/blob/master/examples/Arduino_NetworkTest/Arduino_NetworkTest.ino

lewisxhe, 2023-01-03:
My test is normal.
1. Please try to add pinMode (SD_MISO, INPUT_PULLUP) before SPI.begin; Test whether it is normal
2. Make sure the SD card is FAT format and accessible on the computer
If it still doesn't work, I suspect that there is a problem with the SD card seat welding

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

Tig3rch3n, 2023-01-08:
> Sure thing... So far, I have just been using the examples provided in this repo.
>
> https://github.com/Xinyuan-LilyGO/LilyGO-T-SIM7000G/blob/master/examples/Arduino_NetworkTest/Arduino_NetworkTest.ino

Just tested it with my Version 20200415 Board, I had to Comment out the Modem Init (no IoT Sim yet)
But everything works out of the Box with a ext3 Formating
I get

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

tweathers-sec, 2023-01-10:
Thanks all for the input. It was certainly a bad connection with the PCB. I ended up doing an exchange for a new board and my code is working without issue. Closing this out.

Closed 2023-01-10.

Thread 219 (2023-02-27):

VBAT + GND pins vs +/- battery pins on back of board

jjharlow, 2023-02-27:
I've read every issue regarding external batteries with these boards and this isn't clear to me. Is there a benefit to soldering my battery pack directly to the +/- pins on the back of the board (I removed the existing battery holder) vs using the VBAT & GND pins?

It sounds like there are some benefits, namely overcharge/discharge and retaining the use of the On/Off switch by connecting to the board via the battery pins on the back. If that is the case, absent any protection on my batteries and the VBAT not providing this, it seems like a big advantage.

https://github.com/Xinyuan-LilyGO/LilyGO-T-SIM7000G/issues/40#issuecomment-661050487

However, another post suggest that the behavior of the on/off switch and associated logic may be questionable and bypassing it was a better choice.

https://github.com/Xinyuan-LilyGO/LilyGO-T-SIM7000G/issues/65#issuecomment-770247748

So my question, is there any actual recommendation or is it situational?

Thanks.

jjharlow, 2023-03-08:
Well, for me it's going to come down to leveraging the onboard solar charger, which means I will be soldering to the back of the board.

fgnievinski, 2023-06-06:
related information:
https://github.com/Xinyuan-LilyGO/LilyGO-T-SIM7000G/issues/37#issuecomment-674332698

Closed 2023-03-08.

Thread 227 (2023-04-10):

Board stop transmiting if battery is under 4 volts

Gabriel-Gardin, 2023-04-10:
Hello. I am having problems when trying to use the board with not totally full batteries.

The schematic says that the under voltage protection voltage is defined from the DW01 chip(2.4 Volts)

I am testing with a battery which is at 3.86 volts, everything starts to work but then it doesn't finish transmitting and the boards is turned off until I press the pwr button, which, as per my understanding, resets the DW01 chip and the board comes back on.

Is this the expected behaviour? Shouldn't it be working with almost 3.9 volts?

Gabriel-Gardin, 2023-04-10:
Ok, so I have debugged a little more an it seems that the problem is that when the board starts transmitting some heavy ripple starts on the battery, which cannot stand the high current surges.

In the image bellow you can se the ripple that is causing the problems...

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

Gabriel-Gardin, 2023-04-14:
Ok... so I have figured out what the problem is.

IN gprs class 12, when transmitting data the modem can consume bursts of 2.3msecs and 4.616ms period when the current can go as up to 2A. This is way more than a common 18650 battery can give, therefore it's a common practice to add supercapacitors to help the battery with this high current bursts.

So I added a 5.5V 1F super cap in parallel with the battery and now, everything is working(currently the battery is at 3.69V) working perfectly...

More info about powering GPRS modems with battery here:

https://www.tecategroup.com/white_papers/ppr_2003_GPRS-perf.pdf

https://www.ti.com/lit/ug/tiducg0/tiducg0.pdf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,about%2020%20mA%2F1000%20mAh

https://usermanual.wiki/Pdf/QuectelLowPowerDesignUserGuideV13.1941735194

Gabriel-Gardin, 2023-04-14:
So to close this I would suggest adding a super cap in the board... 5.5V x 1F seems to be good enough for Li-Ion 18650 batteries.

liorisakov, 2023-06-06:
Thanks!

fgnievinski, 2023-07-07:
@Gabriel-Gardin could you post a photo, please? I'm trying to see how close to the board the capacitor needs to be. Also, did you put a resistor or a switch to avoid short circuiting when the capacitor is empty? We've tried a full faraday supercapacitor and it helps when the battery is fully charged, but not below 4V. Many thanks for your help.

valdobb, 2024-01-26:
I rather met using  Super pulse battery capacitor (SPC)  and Hybrid Layer Capacitors (HLC) rather than the usual capacitors.

Closed 2023-04-14.

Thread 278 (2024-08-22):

with camera

psuuc-cmvelbis, 2024-08-22:
can i ask how to connect if i want to connect an esp32-cam to this board(lilygo t-sim7000g)

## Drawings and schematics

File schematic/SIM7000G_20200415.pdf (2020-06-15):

Battery Interface | 输输输输4.4-6V

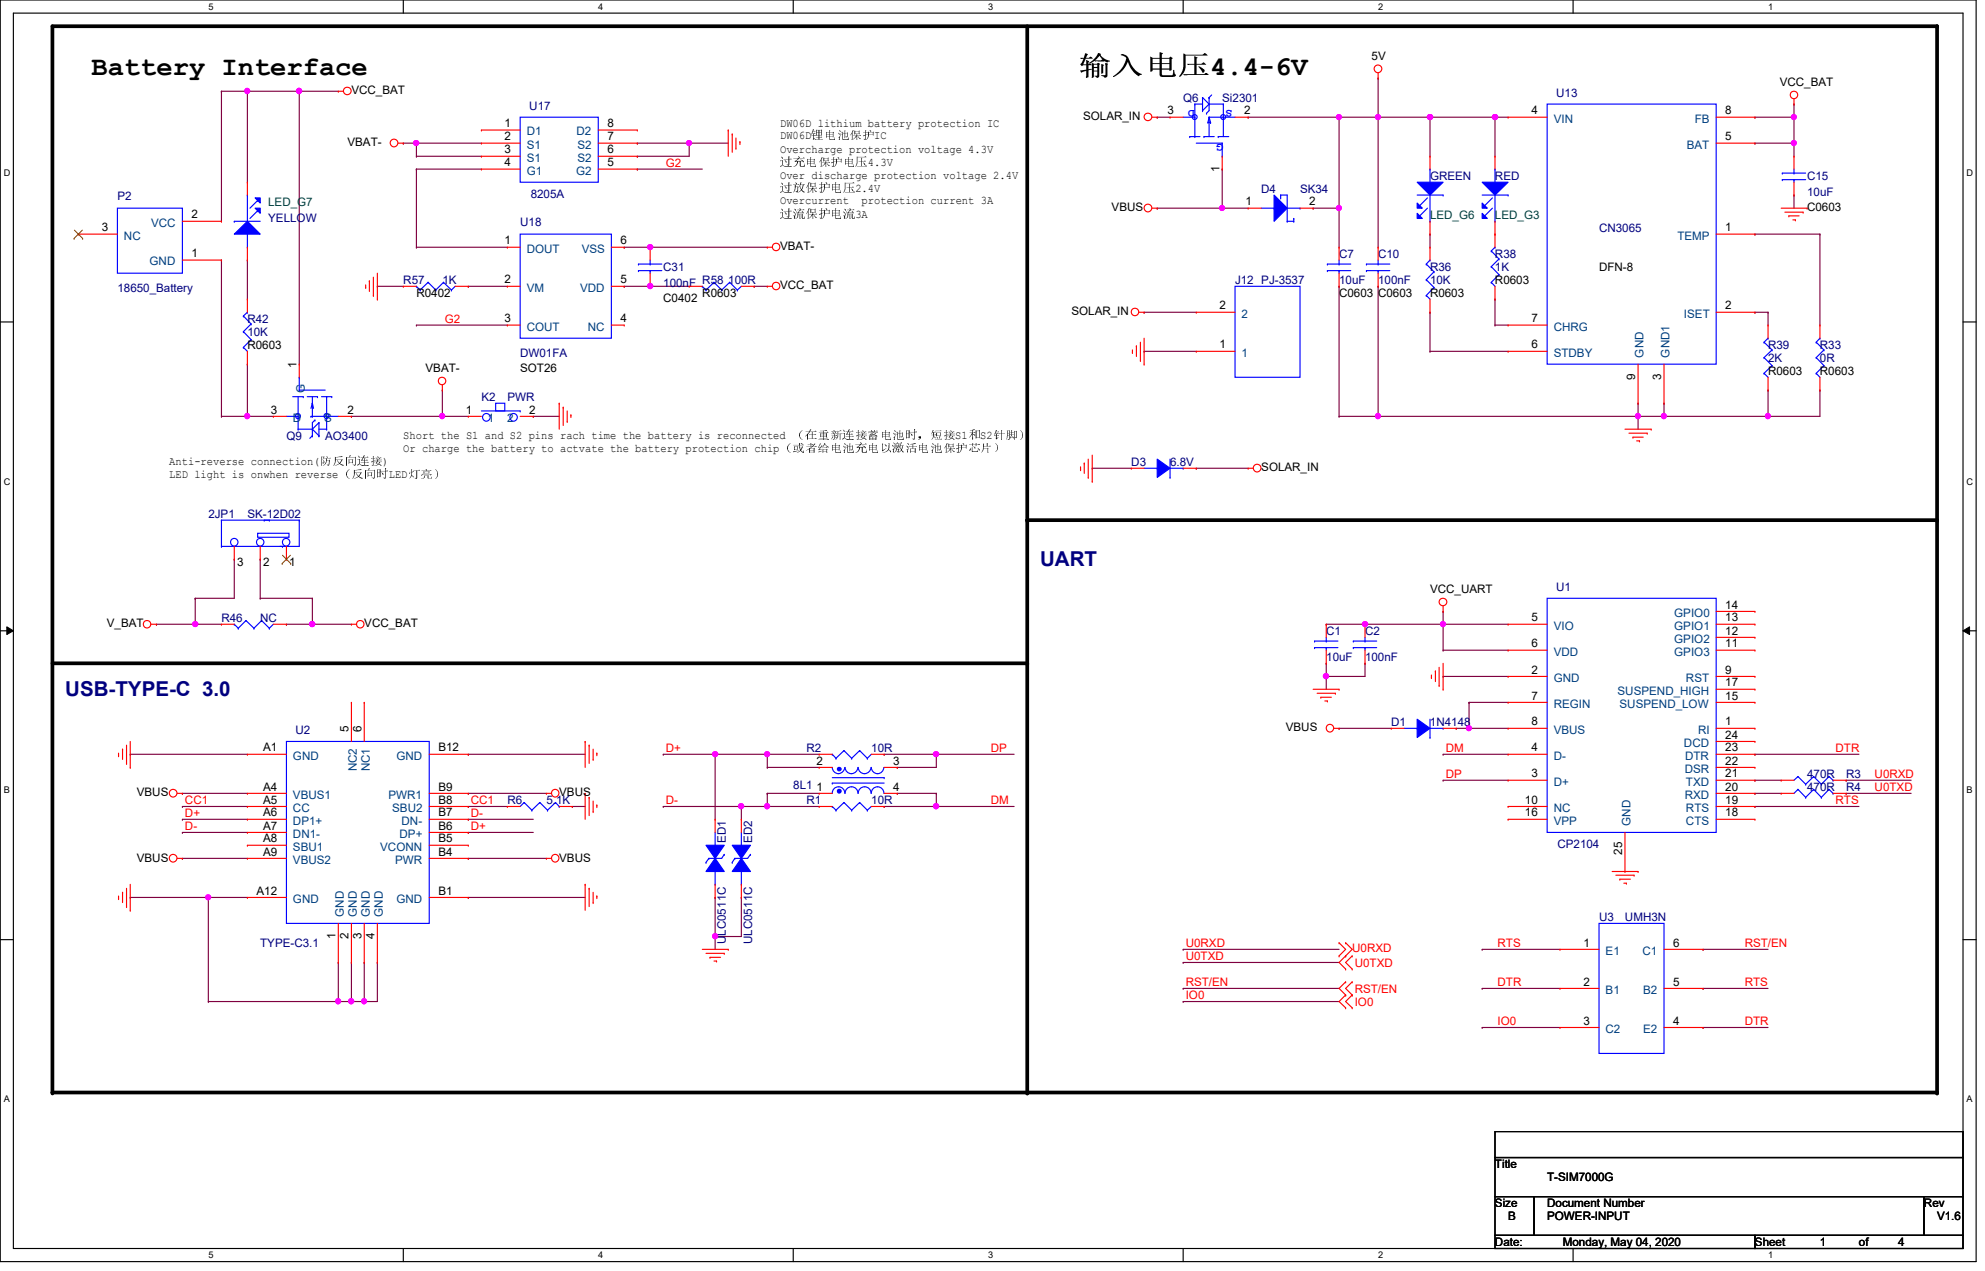
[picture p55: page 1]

Short the S1 and S2 pins rach time the battery is reconnected （在在在防防在在在在，短防S1和S2针针）
Or charge the battery to actvate the battery protection chip（或或或在在或在或或或在在或或或或）

Anti-reverse connection(防防防防防)
LED light is onwhen reverse（防防在LED灯灯）

Core | Connector

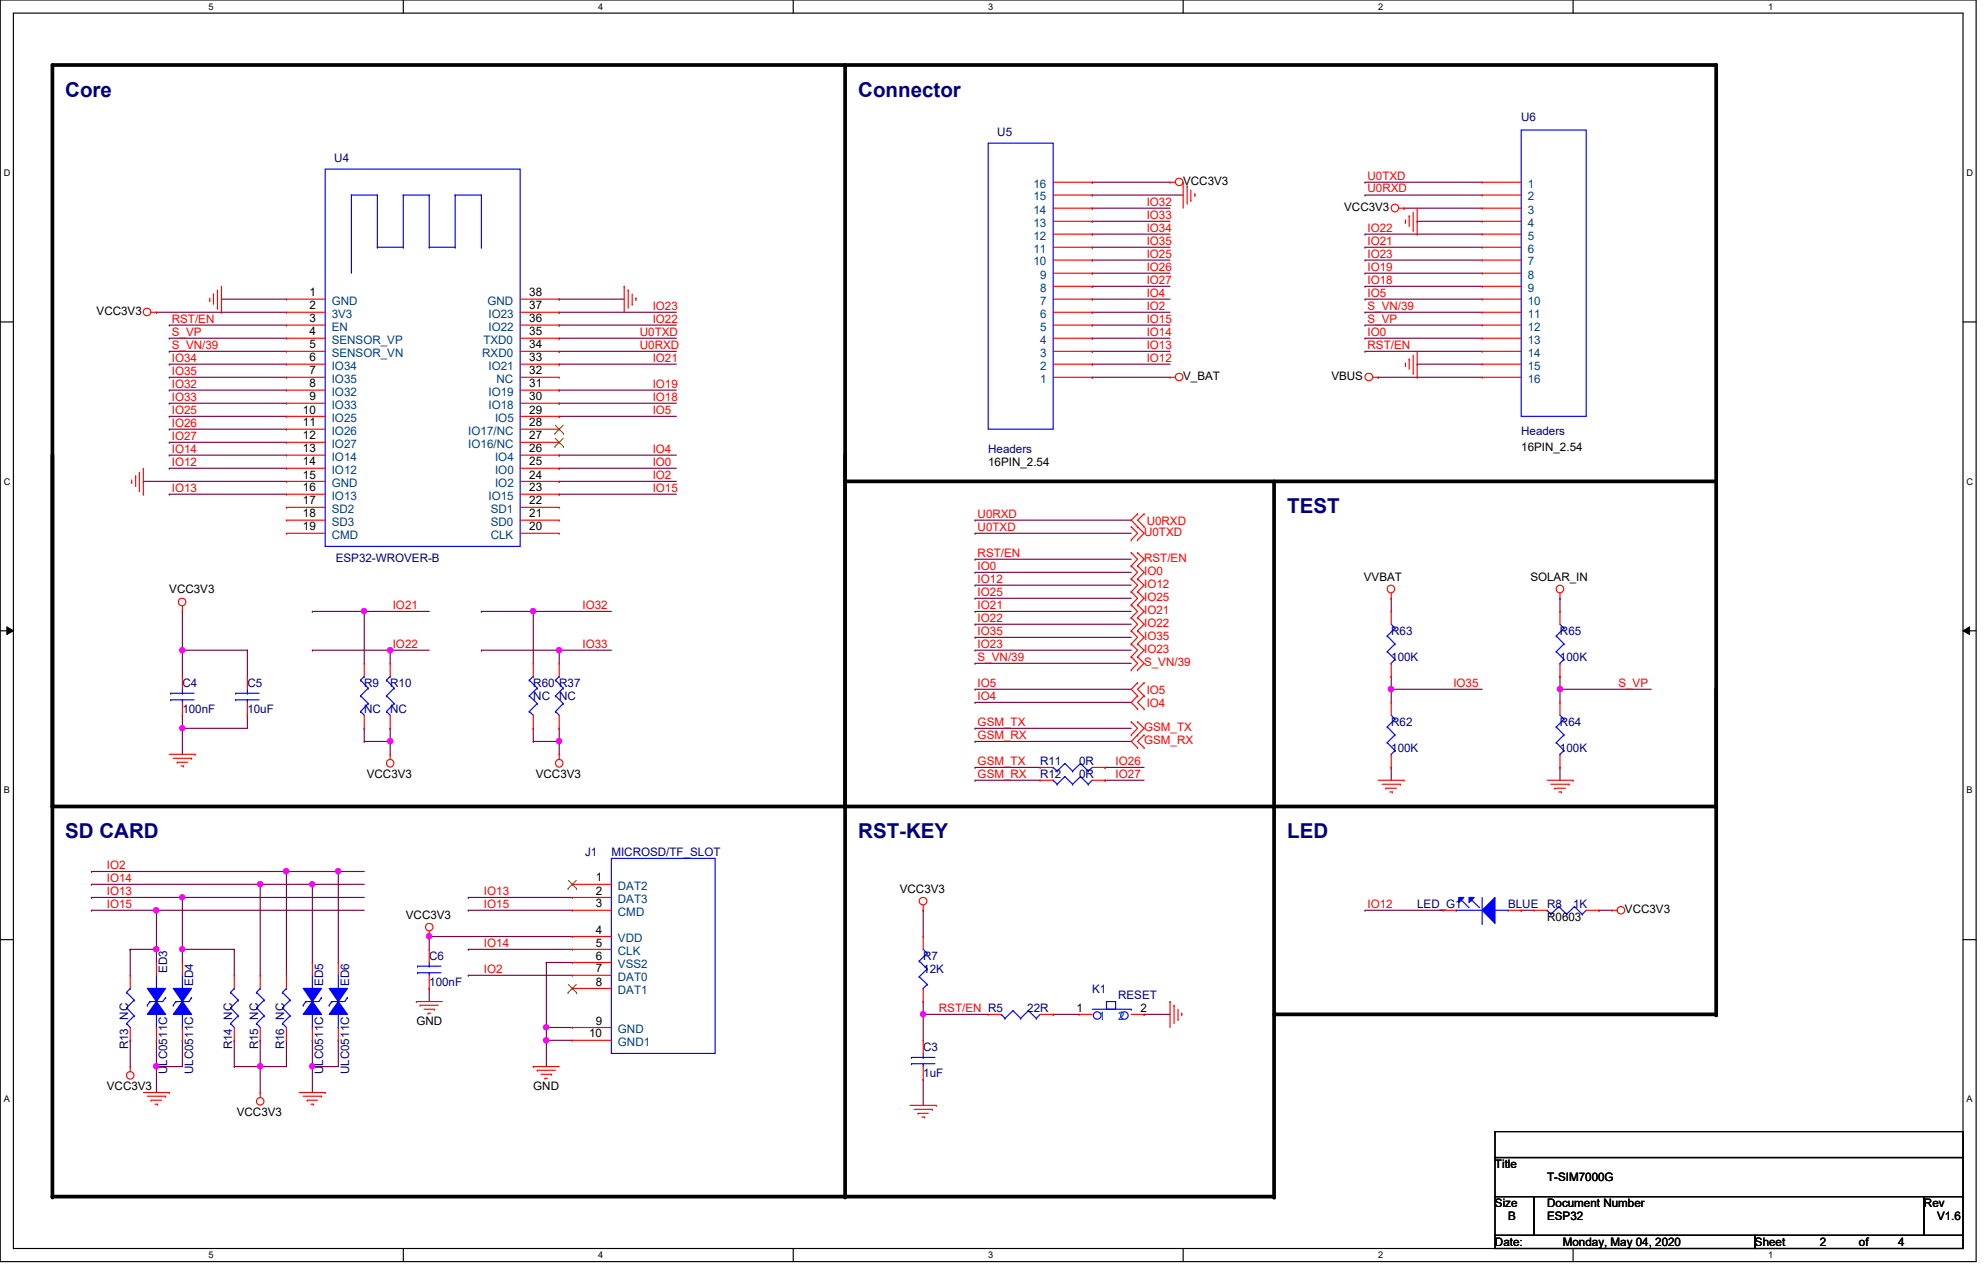
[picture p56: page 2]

# VBAT 3V-4.3V

# UART

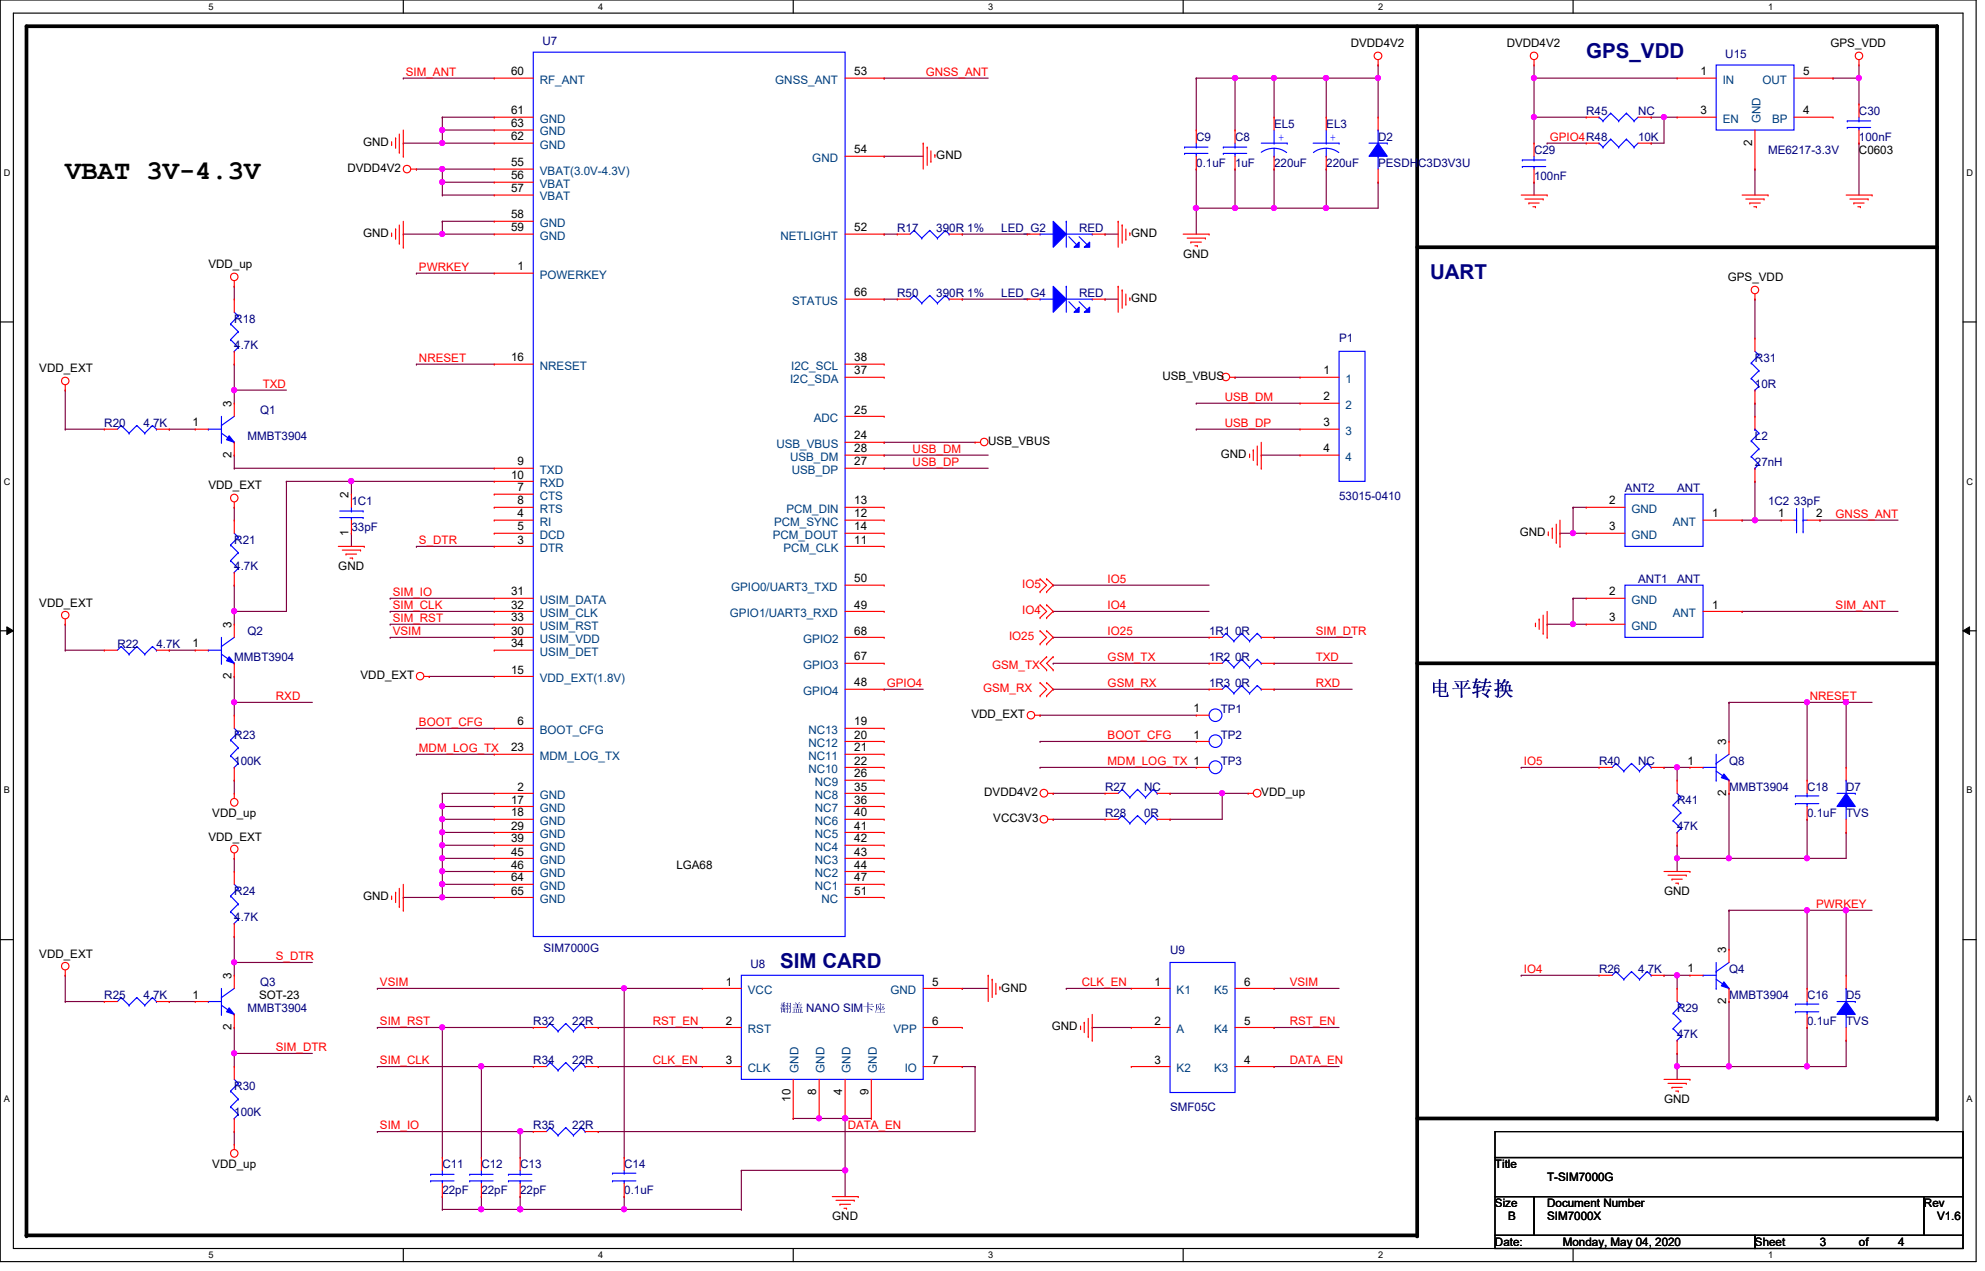
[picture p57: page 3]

NRESET

PWRKEY

VBUS-VCC4.2V | 4.2V-3.3V

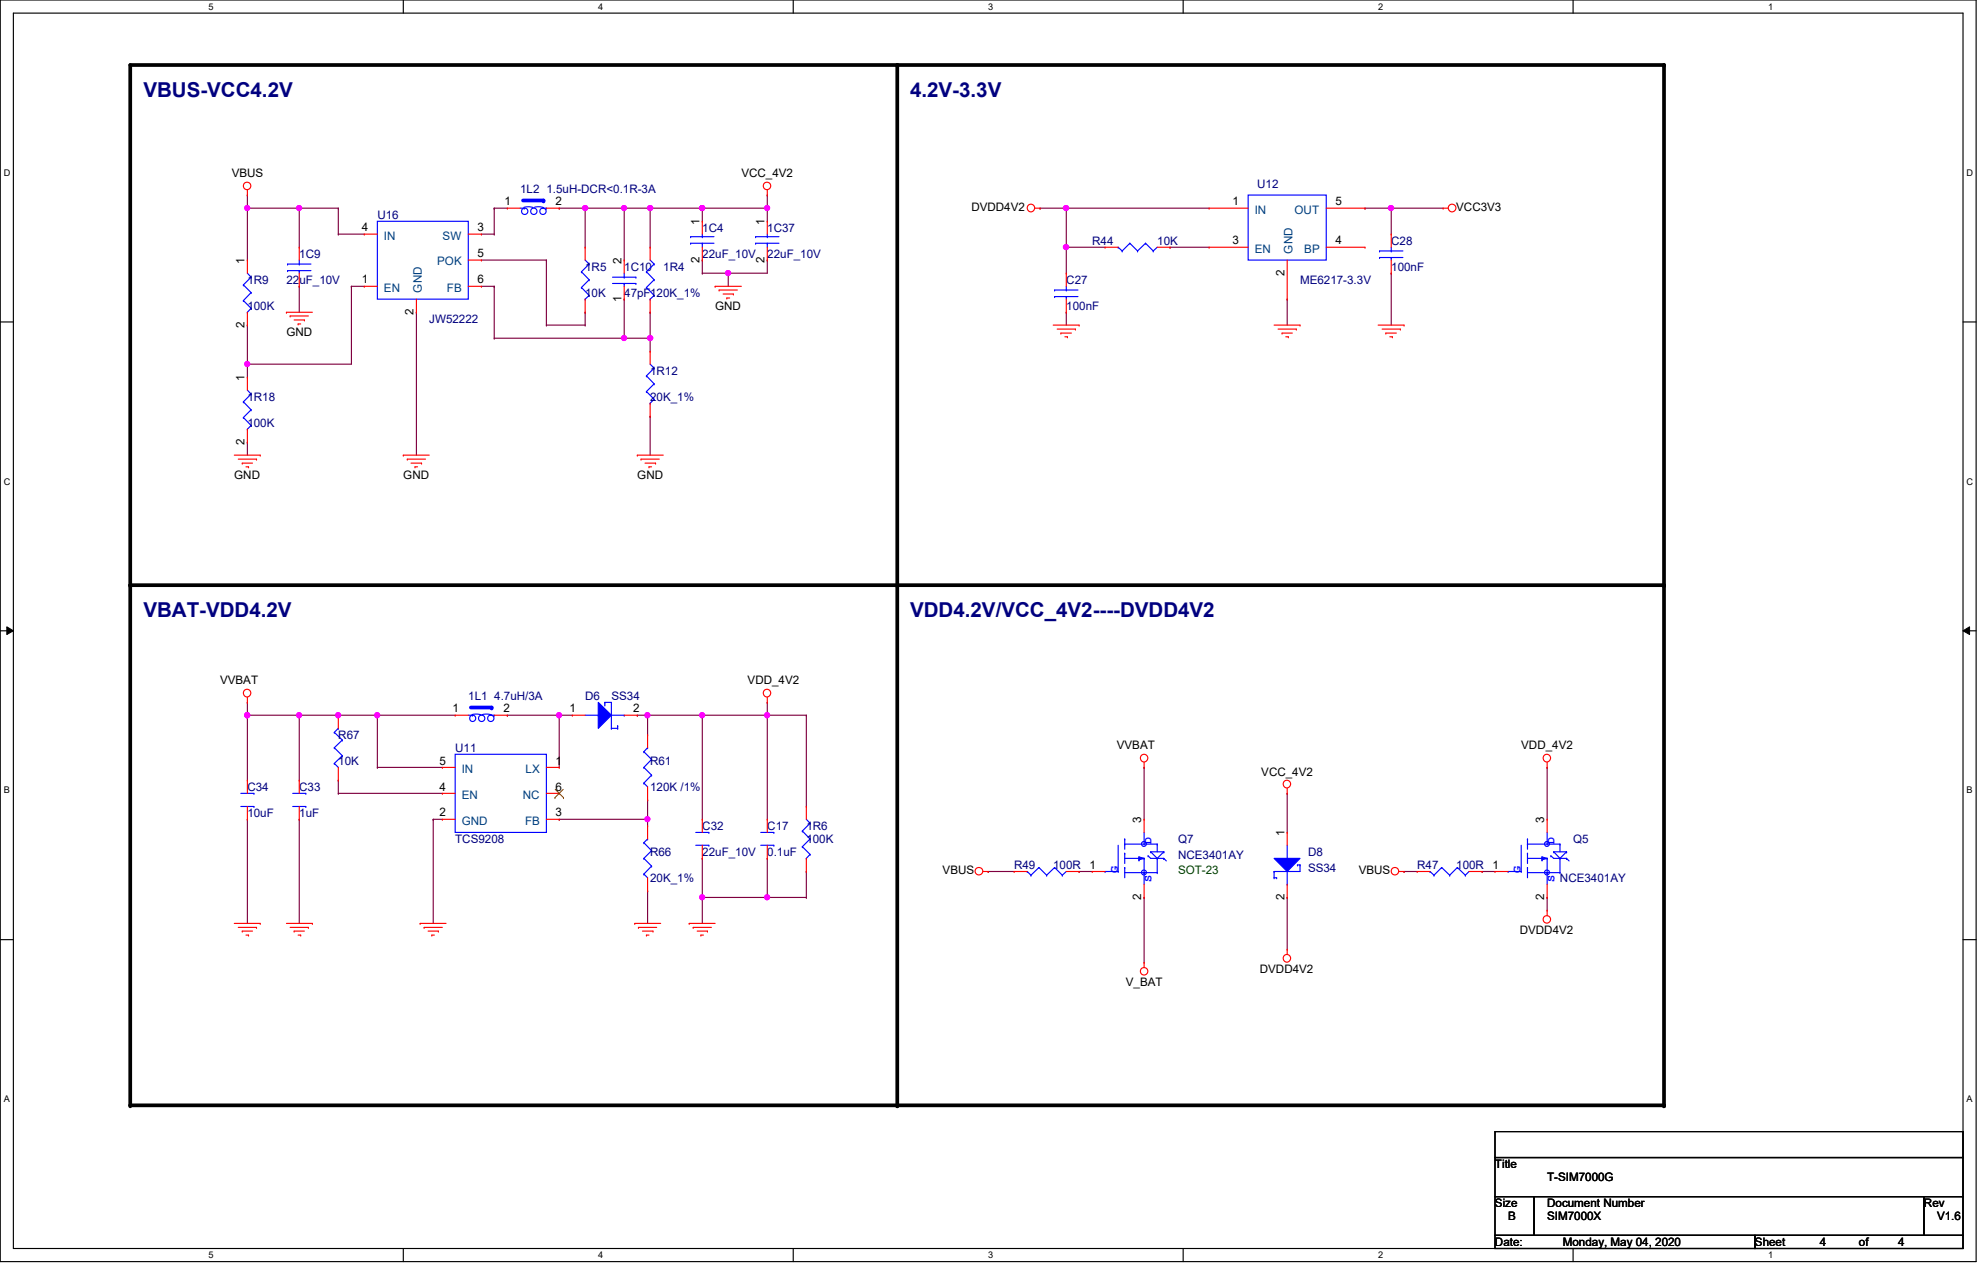
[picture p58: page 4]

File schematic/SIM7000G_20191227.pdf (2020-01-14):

TYPE-C | USB3.0 | UART

DM

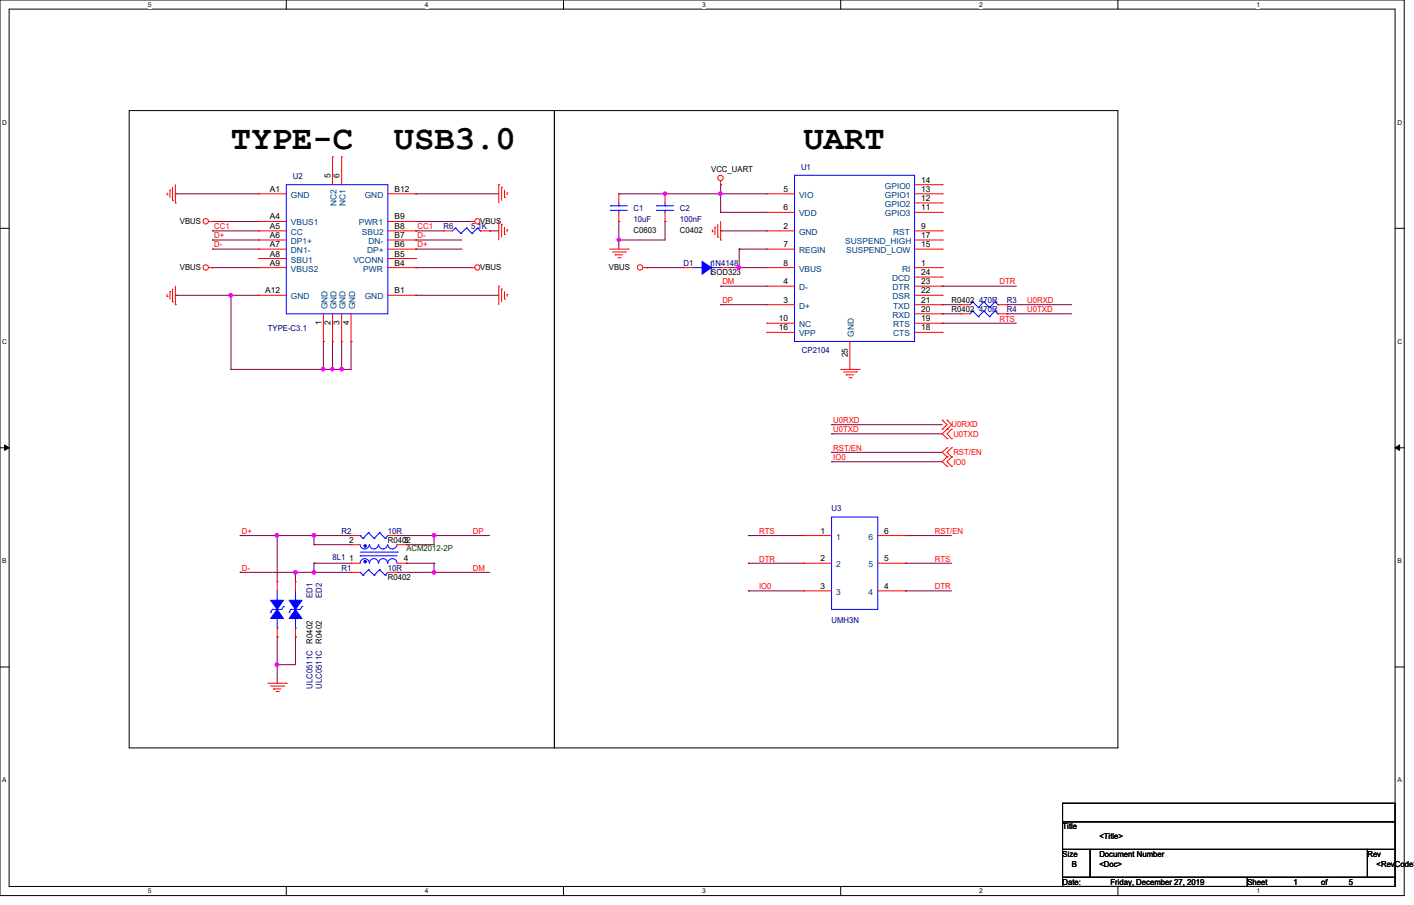
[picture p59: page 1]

# DC/DC 4.2V

# BAT

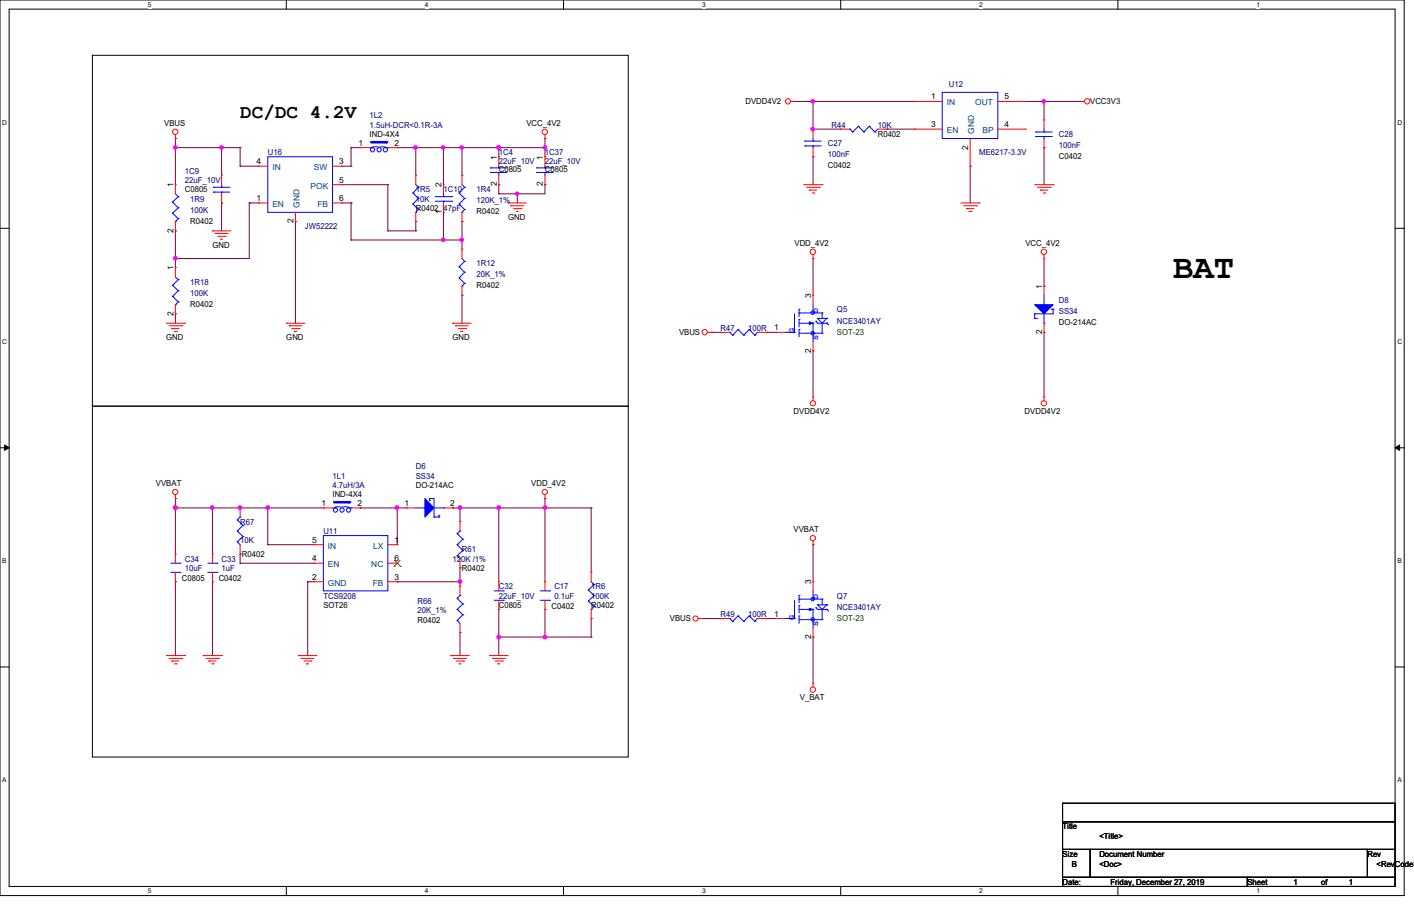
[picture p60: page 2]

# Connector

# ESP32-WROVER

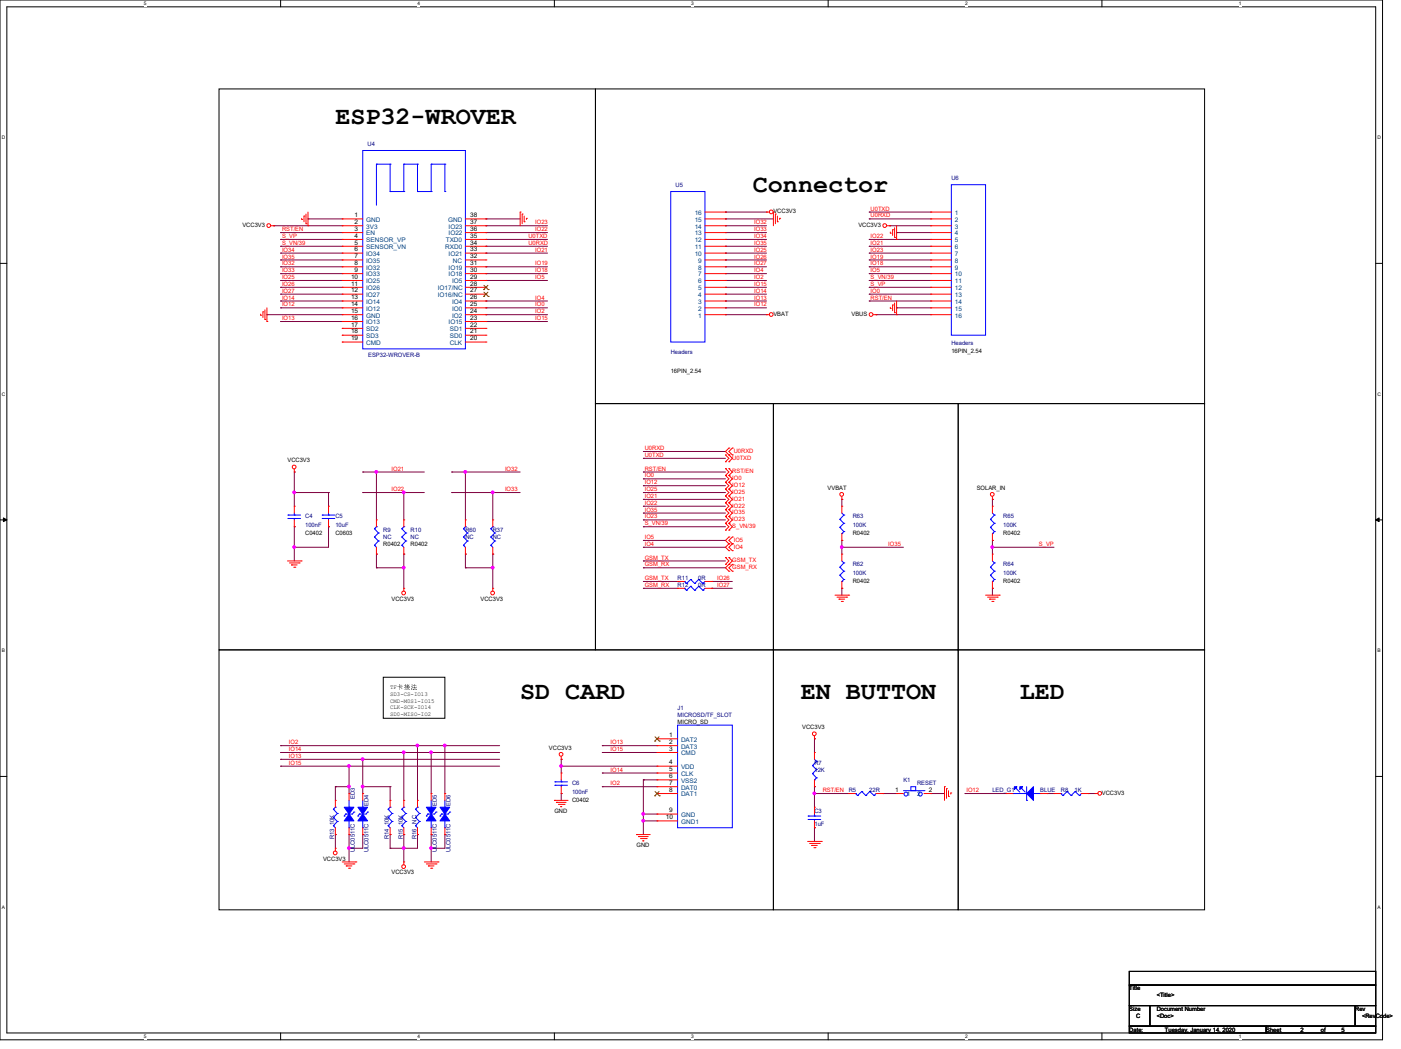
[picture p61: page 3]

# VBAT 3V-4.3V

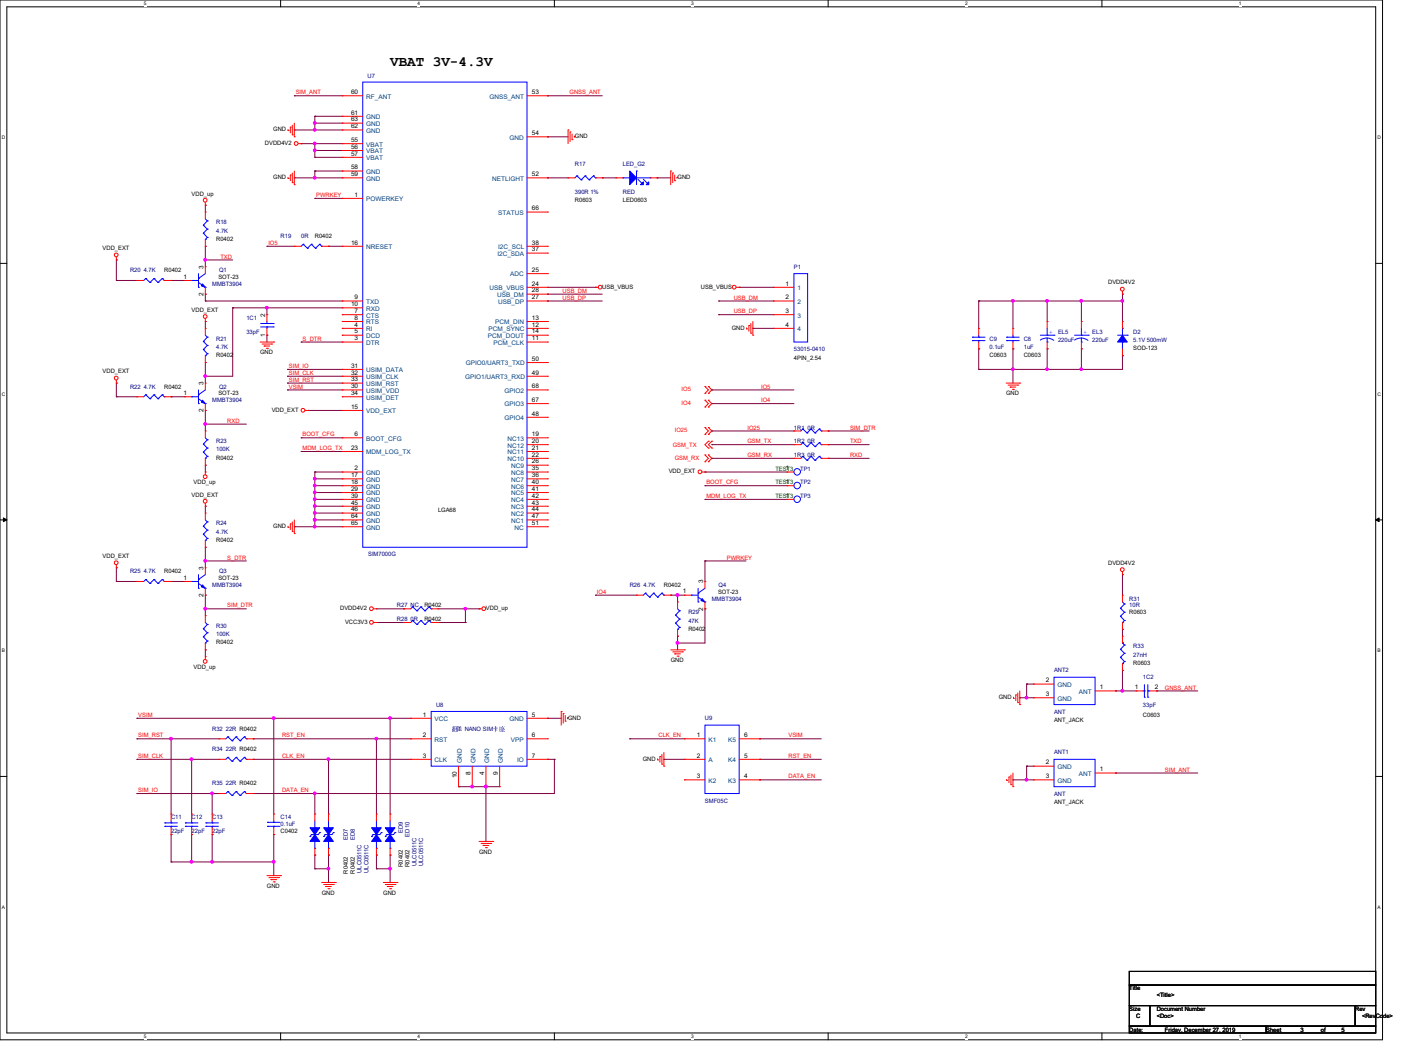
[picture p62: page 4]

5V

## SOLAR_IN

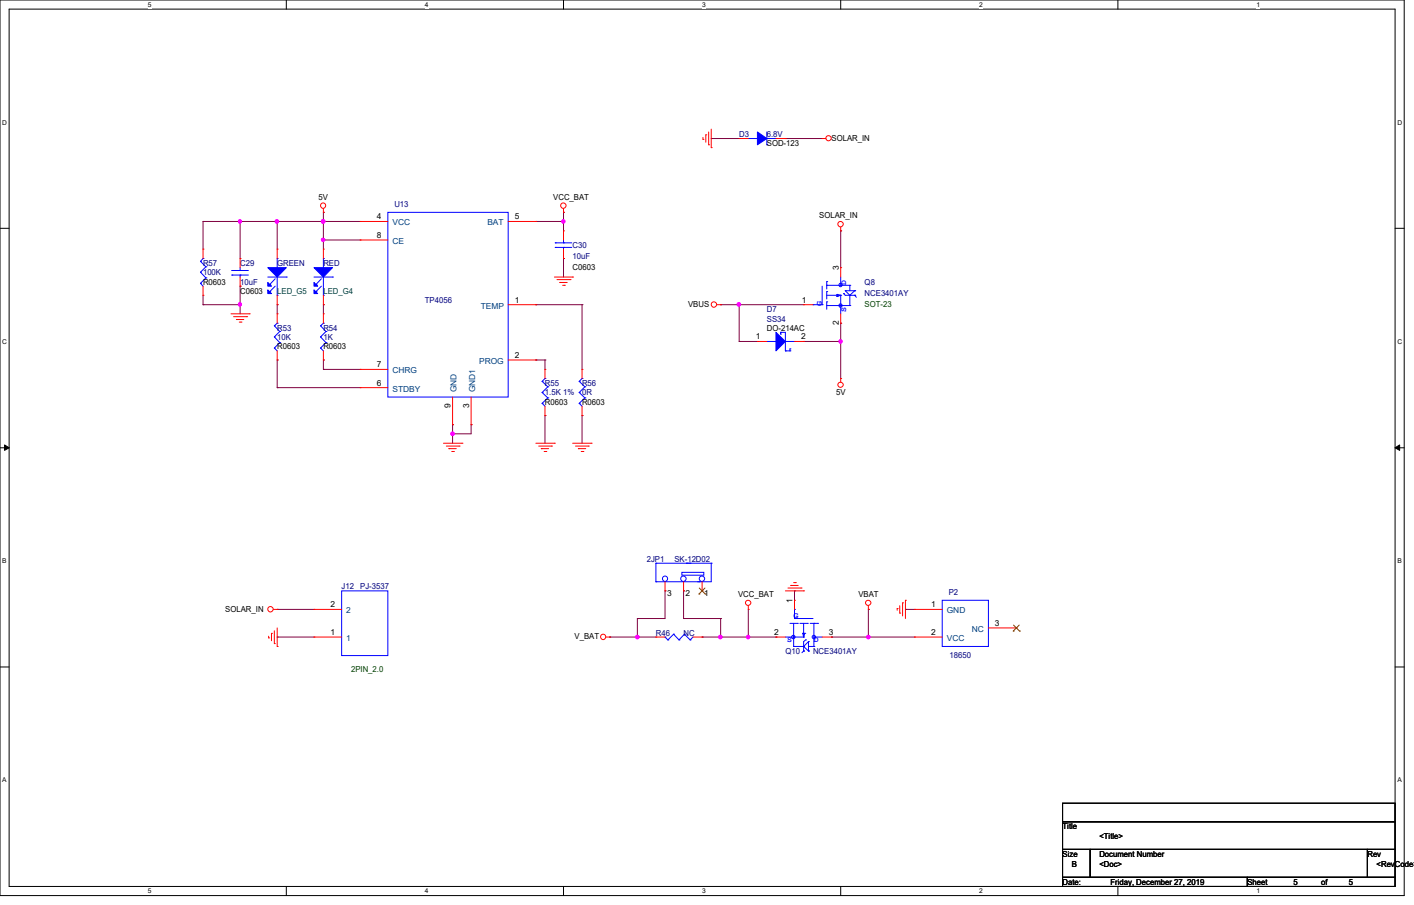
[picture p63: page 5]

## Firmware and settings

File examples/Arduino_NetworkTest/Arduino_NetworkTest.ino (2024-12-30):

/**
 * @file      Arduino_NetworkTest.ino
 * @author    Lewis He (lewishe@outlook.com)
 * @license   MIT
 * @copyright Copyright (c) 2023  Shenzhen Xin Yuan Electronic Technology Co., Ltd
 * @date      2023-02-01
 * @note      This example function is the SIM7000/SIM7070 network test to
 *            determine whether the module can access the network and obtain some access parameters
 */

// Set serial for debug console (to the Serial Monitor, default speed 115200)
#define SerialMon Serial

// Set serial for AT commands (to the module)
// Use Hardware Serial on Mega, Leonardo, Micro
#define SerialAT Serial1

#define TINY_GSM_MODEM_SIM7000
#define TINY_GSM_RX_BUFFER 1024 // Set RX buffer to 1Kb
#define SerialAT Serial1

// See all AT commands, if wanted
// #define DUMP_AT_COMMANDS

#include <TinyGsmClient.h>
#include <SPI.h>
#include <SD.h>
#include <Ticker.h>

#ifdef DUMP_AT_COMMANDS
#include <StreamDebugger.h>
StreamDebugger debugger(SerialAT, SerialMon);
TinyGsm modem(debugger);
#else
TinyGsm modem(SerialAT);
#endif

#define UART_BAUD           9600
#define PIN_DTR             25
#define PIN_TX              27
#define PIN_RX              26
#define PWR_PIN             4

#define SD_MISO             2
#define SD_MOSI             15
#define SD_SCLK             14
#define SD_CS               13
#define LED_PIN             12

void enableGPS(void)
{
    // Set Modem GPS Power Control Pin to HIGH ,turn on GPS power
    // Only in version 20200415 is there a function to control GPS power
    modem.sendAT("+CGPIO=0,48,1,1");
    if (modem.waitResponse(10000L) != 1) {
        DBG("Set GPS Power HIGH Failed");
    }
    modem.enableGPS();
}

void disableGPS(void)
{
    // Set Modem GPS Power Control Pin to LOW ,turn off GPS power
    // Only in version 20200415 is there a function to control GPS power
    modem.sendAT("+CGPIO=0,48,1,0");
    if (modem.waitResponse(10000L) != 1) {
        DBG("Set GPS Power LOW Failed");
    }
    modem.disableGPS();
}

void modemPowerOn()
{
    pinMode(PWR_PIN, OUTPUT);
    digitalWrite(PWR_PIN, LOW);
    delay(1000);    //Datasheet Ton mintues = 1S
    digitalWrite(PWR_PIN, HIGH);
}

void modemPowerOff()
{
    pinMode(PWR_PIN, OUTPUT);
    digitalWrite(PWR_PIN, LOW);
    delay(1500);    //Datasheet Ton mintues = 1.2S
    digitalWrite(PWR_PIN, HIGH);
}


void setup()
{
    // Set console baud rate
    SerialMon.begin(115200);

    // Set LED OFF
    pinMode(LED_PIN, OUTPUT);
    digitalWrite(LED_PIN, HIGH);

    modemPowerOn();

    SPI.begin(SD_SCLK, SD_MISO, SD_MOSI);
    if (!SD.begin(SD_CS)) {
        Serial.println("> It looks like you haven't inserted the SD card..");
    } else {
        uint32_t cardSize = SD.cardSize() / (1024 * 1024);
        String str = "> SDCard Size: " + String(cardSize) + "MB";
        Serial.println(str);
    }

    SerialAT.begin(UART_BAUD, SERIAL_8N1, PIN_RX, PIN_TX);

    Serial.println("> Check whether Modem is online");
    //test modem is online ?
    uint32_t  timeout = millis();
    while (!modem.testAT()) {
        Serial.print(".");
        if (millis() - timeout > 60000 ) {
            Serial.println("> It looks like the modem is not responding, trying to restart");
            modemPowerOff();
            delay(5000);
            modemPowerOn();
            timeout = millis();
        }
    }
    Serial.println("\nModem is online");

    //test sim card is online ?
    timeout = millis();
    Serial.print("> Get SIM card status");
    while (modem.getSimStatus() != SIM_READY) {
        Serial.print(".");
        if (millis() - timeout > 60000 ) {
            Serial.println("It seems that your SIM card has not been detected. Has it been inserted?");
            Serial.println("If you have inserted the SIM card, please remove the power supply again and try again!");
            return;
        }

    }
    Serial.println();
    Serial.println("> SIM card exists");


    Serial.println("> /**********************************************************/");
    Serial.println("> Please make sure that the location has 2G/NB-IOT signal");
    Serial.println("> SIM7000/SIM707G does not support 4G network. Please ensure that the USIM card you use supports 2G/NB access");
    Serial.println("> /**********************************************************/");

    String res = modem.getIMEI();
    Serial.print("IMEI:");
    Serial.println(res);
    Serial.println();

    /*
    * Tips:
    * When you are not sure which method of network access is supported by the network you use,
    * please use the automatic mode. If you are sure, please change the parameters to speed up the network access
    * * * * */

    //Set mobile operation band
    modem.sendAT("+CBAND=ALL_MODE");
    modem.waitResponse();

    // Args:
    // 1 CAT-M
    // 2 NB-IoT
    // 3 CAT-M and NB-IoT
    // Set network preferre to auto
    uint8_t perferred = 3;
    modem.setPreferredMode(perferred);

    if (perferred == 2) {
        Serial.println("When you select 2, please ensure that your SIM card operator supports NB-IOT");
    }

    // Args:
    // 2 Automatic
    // 13 GSM only
    // 38 LTE only
    // 51 GSM and LTE only
    // Set network mode to auto
    modem.setNetworkMode(2);


    // Check network signal and registration information
    Serial.println("> SIM7000/SIM7070 uses automatic mode to access the network. The access speed may be slow. Please wait patiently");
    SIM70xxRegStatus status;
    timeout = millis();
    do {
        int16_t sq =  modem.getSignalQuality();

        status = modem.getRegistrationStatus();

        if (status == REG_DENIED) {
            Serial.println("> The SIM card you use has been rejected by the network operator. Please check that the card you use is not bound to a device!");
            return;
        } else {
            Serial.print("Signal:");
            Serial.println(sq);
        }

        if (millis() - timeout > 360000 ) {
            if (sq == 99) {
                Serial.println("> It seems that there is no signal. Please check whether the"\
                               "LTE antenna is connected. Please make sure that the location has 2G/NB-IOT signal\n"\
                               "SIM7000G does not support 4G network. Please ensure that the USIM card you use supports 2G/NB access");
                return;
            }
            timeout = millis();
        }

        delay(800);
    } while (status != REG_OK_HOME && status != REG_OK_ROAMING);

    Serial.println("Obtain the APN issued by the network");
    modem.sendAT("+CGNAPN");
    if (modem.waitResponse(3000, res) == 1) {
        res = res.substring(res.indexOf(",") + 1);
        res.replace("\"", "");
        res.replace("\r", "");
        res.replace("\n", "");
        res.replace("OK", "");
        Serial.print("The APN issued by the network is:");
        Serial.println(res);
    }

    modem.sendAT("+CNACT=1");
    modem.waitResponse();


    // res = modem.getLocalIP();
    modem.sendAT("+CNACT?");
    if (modem.waitResponse("+CNACT: ") == 1) {
        modem.stream.read();
        modem.stream.read();
        res = modem.stream.readStringUntil('\n');
        res.replace("\"", "");
        res.replace("\r", "");
        res.replace("\n", "");
        modem.waitResponse();
        Serial.print("The current network IP address is:");
        Serial.println(res);
    }


    modem.sendAT("+CPSI?");
    if (modem.waitResponse("+CPSI: ") == 1) {
        res = modem.stream.readStringUntil('\n');
        res.replace("\r", "");
        res.replace("\n", "");
        modem.waitResponse();
        Serial.print("The current network parameter is:");
        Serial.println(res);
    }


    Serial.println("/**********************************************************/");
    Serial.println("After the network test is complete, please enter the  ");
    Serial.println("AT command in the serial terminal.");
    Serial.println("/**********************************************************/\n\n");

}


uint32_t check_timestamp = 0;

void loop()
{   
    // AT Debug
    // while (SerialAT.available()) {
    //     SerialMon.write(SerialAT.read());
    // }
    // while (SerialMon.available()) {
    //     SerialAT.write(SerialMon.read());
    // }
    
    if (millis() > check_timestamp) {
        Serial.print("[");
        Serial.print(millis() / 1000);
        Serial.print("]:");
        int16_t sq = modem.getSignalQuality();
        SIM70xxRegStatus s = modem.getRegistrationStatus();
        if (s != REG_OK_HOME && s != REG_OK_ROAMING) {
            Serial.println("Devices lost network connect!");
        } else {
            modem.sendAT("+CPSI?");
            if (modem.waitResponse("+CPSI: ") == 1) {
                String res = modem.stream.readStringUntil('\n');
                res.replace("\r", "");
                res.replace("\n", "");
                modem.waitResponse();
                Serial.print("Network is connected. Signal Quality:");
                Serial.println(sq);
                Serial.print("The current network parameter is:");
                Serial.println(res);
            } else {
                Serial.println("get params failed!");
            }
        }
        check_timestamp = millis() + 5000;
    }


}

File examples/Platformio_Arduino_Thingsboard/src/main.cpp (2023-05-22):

/*
Battery test T-SIM7000 & Thingsboard
 */

#define TINY_GSM_MODEM_SIM7000

#define TINY_GSM_RX_BUFFER 1024 // Set RX buffer to 1Kb
#define DUMP_AT_COMMANDS

#include "TinyGsmClient.h"
#include "ThingsBoard.h"

#define uS_TO_S_FACTOR 1000000 /* Conversion factor for micro seconds to seconds */
#define TIME_TO_SLEEP 60       /* ESP32 should sleep more seconds  (note SIM7000 needs ~20sec to turn off if sleep is activated) */
RTC_DATA_ATTR int bootCount = 0;

HardwareSerial serialGsm(1);
#define SerialAT serialGsm
#define TINY_GSM_USE_GPRS true
#define TINY_GSM_USE_WIFI false

// cosmote
const char apn[] = "internet";
const char nbiot_apn[] = "iot";

// 1nce
// const char apn[] = "iot.1nce.net";
// const char nbiot_apn[] = "iot.1nce.net";

#define isNBIOT true

const char user[] = "";
const char pass[] = "";

// TTGO T-SIM pin definitions
#define MODEM_RST 5
#define MODEM_PWKEY 4
#define MODEM_DTR 25

#define MODEM_TX 26
#define MODEM_RX 27

#define I2C_SDA 21
#define I2C_SCL 22

#define PIN_ADC_BAT 35
#define PIN_ADC_SOLAR 36
#define ADC_BATTERY_LEVEL_SAMPLES 100

#ifdef DUMP_AT_COMMANDS
#include "StreamDebugger.h"
StreamDebugger debugger(serialGsm, Serial);
TinyGsm modem(debugger);
#else
TinyGsm modem(serialGsm);
#endif

#define TOKEN "xxxxxxxxxxxxxxxxxxxx"     // thingsboard token
#define THINGSBOARD_SERVER "192.168.1.1" //thingsboard server

// Baud rate for debug serial
#define SERIAL_DEBUG_BAUD 115200

// Initialize GSM client
TinyGsmClient client(modem);

// Initialize ThingsBoard instance
ThingsBoard tb(client);

// Set to true, if modem is connected
bool modemConnected = false;

void read_adc_bat(uint16_t *voltage);
void read_adc_solar(uint16_t *voltage);
void shutdown();
void wait_till_ready();
void modem_off();

void print_wakeup_reason()
{
    esp_sleep_wakeup_cause_t wakeup_reason;

    wakeup_reason = esp_sleep_get_wakeup_cause();

    switch (wakeup_reason) {
    case ESP_SLEEP_WAKEUP_EXT0:
        Serial.println("Wakeup caused by external signal using RTC_IO");
        break;
    case ESP_SLEEP_WAKEUP_EXT1:
        Serial.println("Wakeup caused by external signal using RTC_CNTL");
        break;
    case ESP_SLEEP_WAKEUP_TIMER:
        Serial.println("Wakeup caused by timer");
        break;
    case ESP_SLEEP_WAKEUP_TOUCHPAD:
        Serial.println("Wakeup caused by touchpad");
        break;
    case ESP_SLEEP_WAKEUP_ULP:
        Serial.println("Wakeup caused by ULP program");
        break;
    default:
        Serial.printf("Wakeup was not caused by deep sleep: %d\n", wakeup_reason);
        break;
    }
}

void modem_reset()
{
    Serial.println("Modem hardware reset");
    pinMode(MODEM_RST, OUTPUT);
    digitalWrite(MODEM_RST, LOW);
    delay(260); //Treset 252ms
    digitalWrite(MODEM_RST, HIGH);
    delay(4000); //Modem takes longer to get ready and reply after this kind of reset vs power on

    //modem.factoryDefault();
    //modem.restart(); //this results in +CGREG: 0,0
}

void modem_on()
{
    // Set-up modem  power pin
    pinMode(MODEM_PWKEY, OUTPUT);
    digitalWrite(MODEM_PWKEY, LOW);
    delay(10);
    digitalWrite(MODEM_PWKEY, HIGH);
    delay(1010); //Ton 1sec
    digitalWrite(MODEM_PWKEY, LOW);

    //wait_till_ready();
    Serial.println("Waiting till modem ready...");
    delay(4510); //Ton uart 4.5sec but seems to need ~7sec after hard (button) reset
    //On soft-reset serial replies immediately.
}

void modem_off()
{
    //if you turn modem off while activating the fancy sleep modes it takes ~20sec, else its immediate
    Serial.println("Going to sleep now with modem turned off");
    //modem.gprsDisconnect();
    //modem.radioOff();
    modem.sleepEnable(false); // required in case sleep was activated and will apply after reboot
    modem.poweroff();
}

// fancy low power mode - while connected
void modem_sleep() // will have an effect after reboot and will replace normal power down
{
    Serial.println("Going to sleep now with modem in power save mode");
    // needs reboot to activa and takes ~20sec to sleep
    modem.PSM_mode();    //if network supports will enter a low power sleep PCM (9uA)
    modem.eDRX_mode14(); // https://github.com/botletics/SIM7000-LTE-Shield/wiki/Current-Consumption#e-drx-mode
    modem.sleepEnable(); //will sleep (1.7mA), needs DTR or PWRKEY to wake
    pinMode(MODEM_DTR, OUTPUT);
    digitalWrite(MODEM_DTR, HIGH);
}

void modem_wake()
{
    Serial.println("Wake up modem from sleep");
    // DTR low to wake serial
    pinMode(MODEM_DTR, OUTPUT);
    digitalWrite(MODEM_DTR, LOW);
    delay(50);
    //wait_till_ready();
}

void shutdown()
{

    //modem_sleep();
    modem_off();

    delay(1000);
    Serial.flush();
    esp_deep_sleep_start();
    Serial.println("Going to sleep now");
    delay(1000);
    Serial.flush();
    esp_deep_sleep_start();
}

void wait_till_ready() // NOT WORKING - Attempt to minimize waiting time
{

    for (int8_t i = 0; i < 100; i++) { //timeout 100 x 100ms = 10sec
        if (modem.testAT()) {
            //Serial.println("Wait time:%F sec\n", i/10));
            Serial.printf("Wait time: %d\n", i);
            break;
        }
        delay(100);
    }
}
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

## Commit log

2020-02-10 Example project for Platformio - T-SIM7000 NBIoT or GSM mode (modified TinyGSM lib) - Connecting to Thingsboard and sending telemetry battery/rssi/bootcount via MQTT - Sleeping ESP32 & SIM7000 (~1mA 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
2020-07-06 Add ModemReset
    Can run this sketch to reset the modem to factory default if it is misbehaving after AT commands
    [ResetModem.ino]
2020-07-13 Create ATdebug.ino
    This is very helpful for both creators and for resolving issues on the GitHub. Can now easily ask them to run an AT command and tell the response to quickly pin down the error.
    [ATdebug.ino]
2020-07-17 Update ATdebug.ino
    fixed the link (V1.05 is new)
    [ATdebug.ino]
2020-07-17 Update ResetModem.ino
    added a check to see if modem is responding before trying to do anything
    [ResetModem.ino]
2022-03-21 fix： Flash Download Tools
2022-04-23 perfect：Band lock and some simple AT instructions
2023-02-01 Update Arduino_NetworkTest Example
2023-03-29 Add an example of reading battery voltage
2023-04-22 Fix GPS Control Pin https://github.com/Xinyuan-LilyGO/LilyGO-T-SIM7000G/issues/228
    [AllFunctions.ino, Arduino_GPSTest.ino, Arduino_NetworkTest.ino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]
2023-05-04 Fix incorrect startup time
    [ATdebug.ino, AllFunctions.ino, Arduino_Azure_IoTHub.ino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]
2023-05-22 Add dxf
    [T-SIM7000G..dxf]
2023-06-08 Added PCB 3D
    [T-SIM7000g-PCB.stp, t-sim7000g-shell.stp]
2023-06-08 Added board 3D
    [Shell.stp, T-SIM7000G(6.08).stp]
2023-10-20 Update UART-USB bridge schematic
2023-10-20 Update UART-USB schematic
2024-09-26 Update README.MD
    include MODEM_RST pin, as per example:
    https://github.com/Xinyuan-LilyGO/LilyGO-T-SIM7000G/blob/master/examples/Platformio_Arduino_Thingsboard/src/main.cpp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
2025-02-18 Update device video description
2025-06-16 Added modem sleep examples https://github.com/Xinyuan-LilyGO/LilyGO-T-SIM7000G/issues/305
    [ModemSleep.ino]
